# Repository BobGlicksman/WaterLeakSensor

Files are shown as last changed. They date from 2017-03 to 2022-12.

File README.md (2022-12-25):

# WaterLeakDetector - Version 2
The Water Leak Detector (WLD) is an IoT device that can monitor two specific locations for the presence of water. 
When water is detected, an alarm will sound and an SMS text alert will be sent to the user's mobile phone. 

A typical use case is to deploy the WLD in a laundry room where it can monitor water leaks that might occur from a washing machine, 
hot water heater, or sewer backup.

The WLD also includes a temperature and humidity sensor. These values are displayed on a dial and also in a smartphone app.  The
smartphone app (Android only at this time) is included in this project.  High and low temperature limits may be set via the smartphone
app.  When either limit is hit, an SMS text alert will be sent to the user's mobile phone.  The smartphone app allows the user to set the
high and low temperature limits.  The app displays the current temperature, relative humidity, and the status of all three alarms (low
temperature, high temperature, water leak).

This version (version 2) of the WLD eliminates Blynk and IFTTT integrations in favor or our current standard techniques for app development,
alarms and alerts, and for logging to Google cloud spreadsheets.  For details, see: 

https://github.com/TeamPracticalProjects/Connectivity_Tools_with_Particle_Devices

Begin with the file WLD Read Me First.pdf

<!--- ![front view completed project](Photos/Finished%20pointerB.JPG?raw=true "Completed Project") -->

<!--- ![app screen](Photos/App_screenshot.jpg?raw=true "App Screen") -->

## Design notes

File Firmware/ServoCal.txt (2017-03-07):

/* SERVOCAL: program to calibrate the servo.
    The servo is connected to a 3.3 volt to 5 volt converter.  The converter
    input is connected to Photon pin D3.  A 5.6K ohm pulldown resistor is used
    to ensure that the servo is quiet while the Photon is being flashed/reset.
    
    The SIS debug client is used to specify positions for the servo.  In order
    to calibrate the servo, the servo with a pointer is mounted on to the meter
    scale.  The user specifies positions for the sero and observes where the 
    servo pointer is on the meter scale.  The position values for the scale minimum
    and for the scale maximum are determined by trial and error and the final
    values are noted for use in the WaterLeakDetector program.
    
    date: 3/07/17, by Bob Glicksman
    
    (c) 2017 by Bob Glicksman, Jim Schrempp, and team Practical Projects
*/

Servo myservo;  // create servo object to control a servo

const int MIN_POS = 5;  // the minimum position value allowed
const int MAX_POS = 175;  // the maximum position value allowed

int pos = (MAX_POS - MIN_POS)/2;    // global variable to store the servo position

void setup() {
    Particle.function("Servo", servoCmd);
    
    myservo.attach(A5);  // attaches pin A5 to the servo object
    delay(2000);  // wait 2 seconds before continuing

} // end of setup

void loop() {
    myservo.write(pos); 
} // end of loop

int servoCmd(String cmd) {
    int servoPosition = cmd.toInt(); // get the user's desired position for the servo
    
    if(servoPosition > MAX_POS)  {
        pos = MAX_POS;
    }
    else if(servoPosition < MIN_POS)  {
        pos = MIN_POS;
    }
    else  {
        pos = servoPosition;
    }
    
    return servoPosition;
}  // end of servoCommand

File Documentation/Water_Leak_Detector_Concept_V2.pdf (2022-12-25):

# Water Leak Detector Concept Document

By: Jim Schrempp and Bob Glicksman; updated 12/04/2022

By: Team Practical Projects; 10 June 2017

This document is © Copyright 2022, 2017 Team Practical Projects, Bob Glicksman and Jim Schrempp. All rights reserved.

NOTICE: Use of this document is subject to the terms of use described in the

document “Terms_of_Use_License_and_Disclaimer” that is included in this release package. This document can also be found at: https://github.com/TeamPracticalProjects/WaterLeakSensor/blob/master/Documentation/Terms_of_Use_License_and_Disclaimer.pdf

© 2022, 2017, Team Practical projects, Jim Schrempp and Bob Glicksman; all rights reserved. Subject to “Terms of Use, License and Disclosure”

Table of Contents.

Table of Contents. | 1
Problem. | 2
Proposed Solution. | 2
Operational Details. | 4

Problem.

A leaking washing machine, overflowing tub or sink, or leaky pipes or toilet can cause considerable damage to a home if not detected and shut off early. Years ago, a washing machine water valve stuck open while washing clothes late at night. One of us awoke in the middle of the night to find a flood in the washer/dryer vestibule resulting in $12,000 in water damage. Since that time, we have been reluctant to run the washing machine at night or at any time when someone is not home to watch over it. This is not always convenient and it would help to have a solution that can detect a water leak and signal us via a local alarm (for when we are at home) and/or a smartphone notification (for when we are out).

Leaky or humid basements and leaking water heaters present similar problems. Adding a second water leak detection sensor, as well as temperature and humidity measurement to the project, can cover all of these bases.

Proposed Solution.

There are inexpensive, analog water detection sensors, such as: https://www.amazon.com/Solu-Detection-Arduino-Sensitivity-Surface/dp/B00UJ0DVN4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 (https://www.amazon.com/Solu-Detection-Arduino-Sensitivity-Surface/dp/B00UJ0DVN4)
This sensor looks as follows:

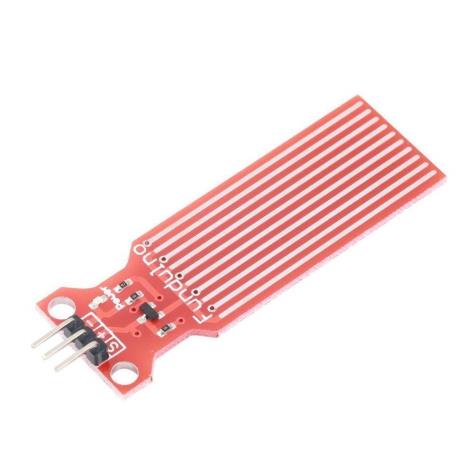
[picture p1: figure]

Water Leak Sensor.

The sensor consists of a bunch of parallel conductors that have a very high DC resistance when the sensor is dry. However, when water shorts out adjacent conductors, the resistance falls.

This project uses a Particle Photon (e.g. https://www.adafruit.com/products/2721) to sense the presence and amount of water via an analog input from this sensor. Based upon our analysis and test results for this water level sensor, the sensor’s analog output should be thresholded to produce an alarm condition when the voltage output goes from 0 volts (dry) to a relatively low value (e.g. 0.5 volts). Tests of the sensor have determined that a pool of water of as little as 2 mm deep will cause this level of change.

Whenever water is sensed, the project will sound a loud, pulsing, audible alarm made from an inexpensive piezo buzzer (e.g. https://www.adafruit.com/products/1536). An LED will also flash when the water level threshold is exceeded. A backlit push button switch (e.g. https://www.adafruit.com/products/1440) provides both the LED indicator and a means to mute the audible alarm when pressed.

Temperature and humidity are measured by one, inexpensive (DHT11) sensor (e.g. https://www.adafruit.com/products/386). An inexpensive servo (e.g. https://www.adafruit.com/products/169) is used to provide a visual “meter” for temperature or humidity, based upon a toggle switch selection (e.g. https://www.adafruit.com/products/3221).

The WiFi capability of the Photon is used to provide a smartphone notification of an alarm condition. Alarms are generated for: Water leak detection by either of the two sensors, low temperature detection, and high temperature detection. Publications to the Particle Cloud from the Photon firmware trigger a webhook which, in turn, runs a Google Apps Script that is deployed as a web app. The script sends an e-mail to the user’s mobile carrier’s SMS gateway, producing an alarm text message on the user’s mobile phone.

A smartphone app is provided as part of this project. The app is written in MIT App Inventor 2 and currently supports Android smartphones (iOS support is in beta testing by MIT as of this writing). The app allows the user to:

- Display the current temperature and relative humidity from the device, over the Internet.
- Display the current status of the alarms (temperature and leak).
- Set and display the low and high temperature alarm limits.

Communication between the Photon, the Particle Cloud and other necessary cloud services follow the Team Practical Projects now-standard approach, as described in the document:

https://github.com/TeamPracticalProjects/Connectivity_Tools_with_Particle_Devices/blob/main/TPP_Connectivity_Tools_Technical_Description.pdf (https://github.com/TeamPracticalProjects/Connectivity_Tools_with_Particle_Devices/blob/main/TPP_Connectivity_Tools_Technical_Description.pdf)

The concept is shown, schematically, below:

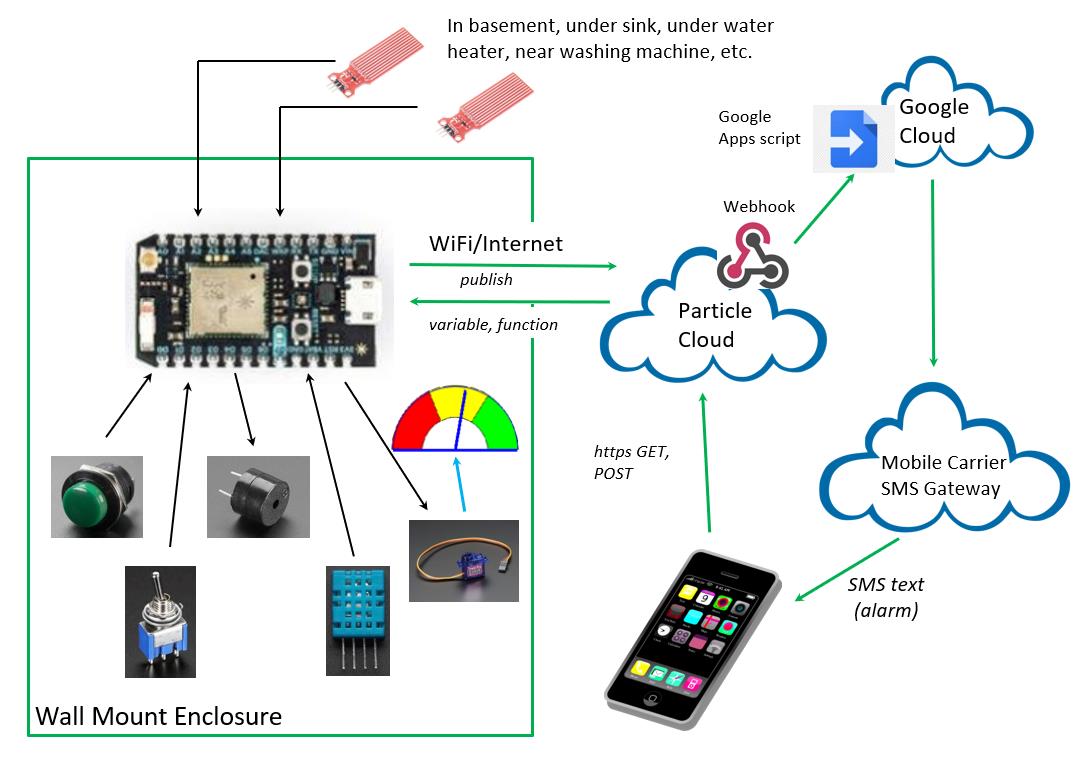
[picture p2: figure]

Water Leak Alarm Concept.

Operational Details.

The project supports two water level sensors. Each water level sensor may be placed under or near a sink, toilet, washing machine, water heater, or basement wall to be monitored. The sensors should be positioned vertically so that the maximum number of conductors are shorted when the water level rises to the bottom of the sensor and above.

The two sensors are cabled to the Photon which, along with the DHT11, toggle switch, pushbutton switch, piezo buzzer and servo, should be wall mounted in a plastic box. The location of the plastic box should be somewhere visible, so that the temperature/humidity indication can clearly be seen and the LED/mute button accessed. Analysis of the water level sensor has determined that it has an output impedance of about 100 ohms; thus, a relatively long cable (e.g. 25 feet) can be used between the sensors and the electronics enclosure, particularly if several threshold readings are required to trigger an alarm.

The firmware in the Photon continuously monitors the amount of water on the sensors, based upon their analog signal value. When a predetermined “flood alert” threshold is exceeded for five measurements, the piezo buzzer is pulsed to create an easily heard audible alarm and the backlit push button LED flashes. The alarm sounds continuously until someone presses the pushbutton to silence it or until the alarm condition is cleared. The LED continues to flash until the alarm condition is cleared. The alarm also publishes an alarm event to the Particle Cloud, which, in turn, results in an SMS alarm notification to the user’s mobile phone. The alarm resets and rearms automatically when five measurements fall below the threshold value.

The Photon reads out temperature and humidity values from the DHT11 sensor every few seconds. The servo “meter” displays either temperature or humidity, based upon the toggle switch selection. The Photon firmware tests to see if the temperature exceeds a low or high reading threshold and publishes an alarm accordingly. Low and high temperature alarms result in an appropriate SMS alarm notification to the user’s mobile phone.

The current temperature and humidity readings and the status of all of the alarms may be read, at any time, using a smartphone app that is part of this project. The app also provides a means for the user to set the high and low temperature alarm limits. The Particle Console may be used in lieu of the smartphone app or for testing purposes.

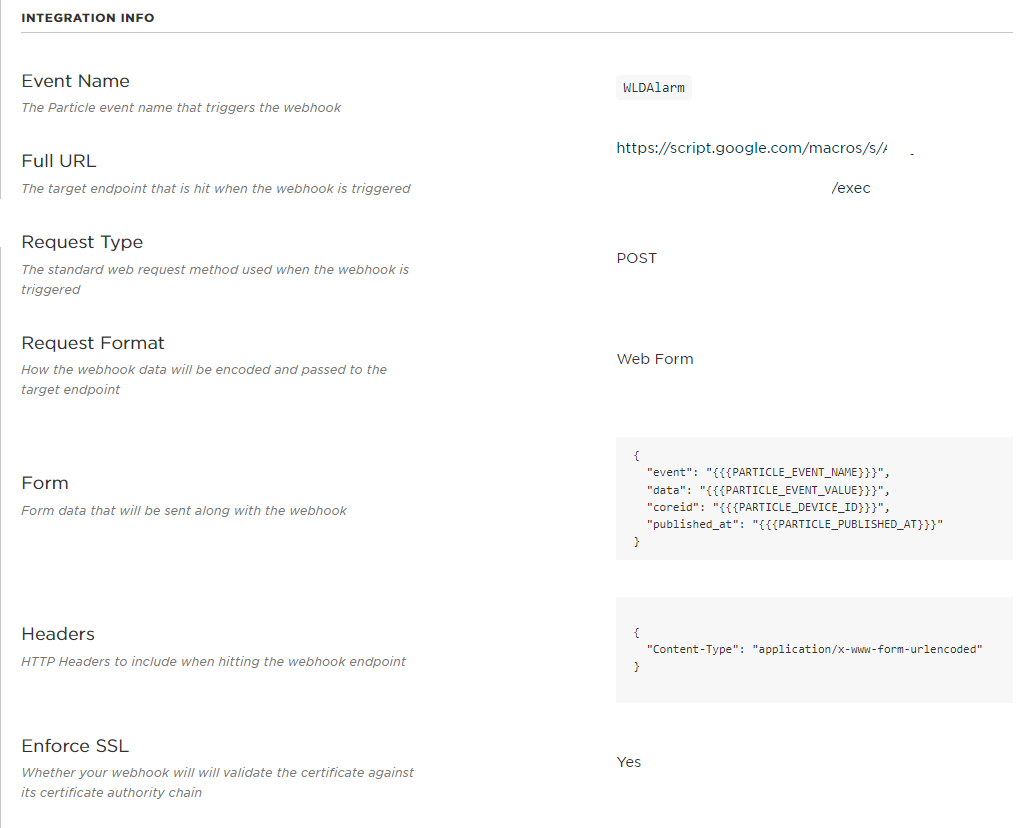
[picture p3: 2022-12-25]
Scripts/Webhook.png

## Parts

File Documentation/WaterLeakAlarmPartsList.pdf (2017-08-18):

REQUIRED PARTS FOR PCB ASSEMBLY
Item # | Qty | Vendor | Vendor Part # | Description | Link | Unit Price | Extended
| | | | | | | price

Notes

1 | 1 Dirty PCBs | N/A | PC Board | http://dirtypcbs.com/store/designer/details
| | | | | /JSchrempp/5148/water-leak-detector-pcb- | $12.00 | $12.00 Only $2 each in quantities of 10 or more.
2 | 1 Adafruit | 2721 | Particle Photon WiFi
| | | | Microcontroller with
| | | | breadboard headers | https://www.adafruit.com/products/2721 | $19.00 | $19.00 The Particle Electron may also be used.
3 | 1 Adafruit | 1787 | 74HCT125 level converter, 3 volt to 5 volt
https://www.adafruit.com/products/1787 | $1.50 | $1.50
4 | 1 Adafruit | 1536 | Piezo Buzzer | https://www.adafruit.com/products/1536 | $0.95 | $0.95
5 | 1 Adafruit | 169 | Micro Servo | https://www.adafruit.com/products/169 | $5.95 | $5.95
6 | 1 Adafruit | 386 | DHT11 temperature/humidity sensor with pullup resistor | https://www.adafruit.com/products/386 | $5.00 | $5.00
7 | 1 Adafruit | 1440 | Momentary pushbutton switch with green LED | https://www.adafruit.com/products/1440 | $1.50 | $1.50
8 | 1 Adafruit | 3221 | SPDT toggle switch | https://www.adafruit.com/products/3221 | $0.95 | $0.95
9 | 1 Adafruit | 501 | USB power supply, 5 volt/1 Amp | https://www.adafruit.com/products/501 | $5.95 | $5.95
10 | 1 Adafruit | 266 | strip of 40 female-female 6" jumper wires | https://www.adafruit.com/products/266 | $3.95 | $3.95
11 | 10 Jameco | 691024 | Resistor, 4.7 k ohm, 1/4 watt axial) | http://www.jameco.com/z/CF1-4W472JRC- Resistor-Carbon-Film-4-7k-Ohm-1-4-Watt-5- _691024.html | $0.10 | $0.99 Must order 10 pcs (need 5)
12 | 1 Jameco | 222608 | USB cable | http://www.jameco.com/z/10U2-02203-BK- Cable-USB2-0-A-B-3-Feet-Black-USB-A-Male- To-USB-B-Male_222608.html
$1.75 | $1.75
13 | 2 Amazon.com sensor | Solu water level sensor | https://www.amazon.com/gp/product/B00 UJ0DVN4/ref=oh_aui_detailpage_o00_s00? ie=UTF8&psc=1
$3.62 | $7.24 Order 1 or 2 sensors, as needed for your project.
14 | 2 Sparkfun.com 14021 | RJ11 dual breakout | https://www.sparkfun.com/products/1402
| | | 1 | $1.95 | $3.90
15 | 4 Sparkfun.com 132 | RJ11 6 pin PCB connector | https://www.sparkfun.com/products/132 | $1.25 | $5.00
16 | 10 Jameco | 690785 | Resistor, 470 ohm, 1/4 watt
| | axial) | http://www.jameco.com/z/CF1-4W471JRC- Resistor-Carbon-Film-470-Ohm-1-4-Watt-5- _690785.html | $0.10 | $0.99 Must order 10 pcs (need 1)
17 | 10 Jameco | 93761 | Capacitor, 100 uf, 25 v | http://www.jameco.com/z/R100-25-100-uF- 25-Volt-Radial-Capacitor_93761.html
$0.09 | $0.90 Must order 10 parts (need 1)

18 | 10 Jameco | 151116 | Capacitor, 0.1 uf, ceramic | http://www.jameco.com/z/DC-1-25- Capacitor-Ceramic-Disc-0-1-micro-F-25V- plusmn-20-37-_151116.html
$0.15 | $1.50 Must order 10 parts (need 7)
19 | 1 Jameco | 230958 | USB female type B connector | http://www.jameco.com/z/USB-B-S-RA-CS1- SPCC-WT-Adam-Technologies-Connector- USB-2-0-USB-B-Pcb-Female-Right-
$0.99 | $0.99 http://www.jameco.com/webapp/wcs/stores/servlet/Produ
ct_10001_10001_230958_-1
20 | 1 Sparkfun.com 10158 | Breakaway male pin
| | | headers (strip of 40) | https://www.sparkfun.com/products/1015
| | | | 8
$2.95 | $2.95
21 | 1 Jameco | 317197 | 14 pin DIP socket | http://www.jameco.com/z/6100-14-R- Socket-IC-14-Pin-Machine-Tooled-Low- Profile-0-3-Inch-Wide_37197.html
$0.50 | $0.50
22 | 1 Jameco | 164822 | 4 pin SIPP socket | http://www.jameco.com/z/6100-1-4-Socket- SIPP-1x4-Pin-Machine-Tool-Pins-Soldertail- Female_164822.html
$0.59 | $0.59 Best to mount the DHT11 in a socket. This miounts the part
vertically - can bend the DHT11 horizinal after installation.
23 | 2 Digi-Key | S7016-ND | 18 pin female header | https://www.digikey.com/products/en?key words=S7016-ND
$1.37 | $2.74
24 | 2 Jameco | 196227 7 ft 4 wire telephone cable http://www.jameco.com/z/8101-64207-
| | | | Modular-Network-Cable-RJ11-6P4C-7-Feet- Long-Reverse-Grey_196227.html
$1.75 | $3.50 NOTE: the assembly instructions are for "reverse" or
"telephone wired" cables. This part number is an example of a 7 foot cable. You can buy telephone cables in many sizes and colors in hardware stores and online. Be sure to get 4 wire (not 2 wire) cables!
TOTAL: | $78.29
| | | | ENCLOSURE AND MOUNTING HARDWARE (CUT BOX)
1 | 1 Office max | 452378 | Box | http://www.officedepot.com/a/products/4 52378/Really-Useful-Box-Plastic-Storage- Box/
$2.79 | $2.79 Use this part for the plastic box that you can cut to make the
enclosure per the instructions.
2 | 8 Digi-Key | 36-1902E-ND | Threaded standoff, F-F, 4- 40 x 1", Nylon | https://www.digikey.com/products/en?key words=36-1902E-ND
$0.90 | $7.20
3 | 8 Digi-Key | 36-9529-ND | Nylon screw, 4-40 x 1/2" | https://www.digikey.com/product- detail/en/keystone-electronics/9529/36-
$0.14 | $1.12
4 | 12 Digi-Key | 36-9427-ND | Nylon screw, 4-40 x 1/4" | https://www.digikey.com/products/en?key words=36-9427-ND
$0.14 | $1.68
5 | 4 Digi-Key | 36-9605-ND | Nylon nut, 4-40 | https://www.digikey.com/product- detail/en/keystone-electronics/9605/36-
$0.17 | $0.68
6 | 1 Home Depot 11364 | #8 wood screw and wall
| | | anchors | http://www.homedepot.com/p/E-Z-Ancor- Twist-N-Lock-75-lb-8-x-1-1-4-in-Philips-Zinc- Plated-Nylon-Flat-Head-Drywall-Anchors- with-Screws-4-Pack-11364/100165900
$1.49 | $1.49 4 pack (need 2)
7 | 1 N/A | N/A | Front panel, laser cut from
3 mm plastic or wood
N/A | N/A | N/A | This is a custom made part from a 2D CAD file. You need
access to a laser cutter to fabricate it.

8 | 1 N/A | N/A | Mounting bracket, laser cut
from 3 mm plastic or wood
N/A | N/A | N/A | This is a custom made part from a 2D CAD file. You need
access to a laser cutter to fabricate it.

ENCLOSURE AND MOUNTING HARDWARE (3D PRINTED)
1 | 1 Shapeways | | Mounting assembly | https://www.shapeways.com/product/HBS
| | | | DDYLAU/water-leak-detector-chassis (https://www.shapeways.com/product/HBSDDYLAU/water-leak-detector-chassis)
$24.00 | $24.00 Use this in lieu if the plastic box for a 3D printed ready to
assemble mounting enclosure.
2 | 1 Shapeways | | 3D printed front panel | https://www.shapeways.com/product/UST
| | | | N8GVJQ/wld-bezel (https://www.shapeways.com/product/USTN8GVJQ/wld-bezel)
$15.00 | $15.00 Use this with the Shapeways 3D printed Mounting assembly
3 | 8 Digi-Key | 36-9427-ND | Nylon screw, 4-40 x 1/4" | https://www.digikey.com/products/en?key
| | | | words=36-9427-ND
$0.14 | $1.12
4 | 8 Digi-Key | 36-9605-ND | Nylon nut, 4-40 | https://www.digikey.com/product-
| | | | detail/en/keystone-electronics/9605/36-
| | | | 9605-ND/2746252
$0.17 | $1.36
5 | 4 | Self tapping screw | [need link from Jim]
6 | 1 Home Depot 11364 | #8 wood screw and wall
| | anchors | http://www.homedepot.com/p/E-Z-Ancor-
| | | Twist-N-Lock-75-lb-8-x-1-1-4-in-Philips-Zinc-
| | | Plated-Nylon-Flat-Head-Drywall-Anchors-
| | | with-Screws-4-Pack-11364/100165900
$1.49 | $1.49

ENCLOSURE AND MOUNTING HARDWARE (LASER CUT)
1 | 1 Tap Plastics | 8x11 3mm material | $10.00 | $10.00 acrylic or wood. For this case you have to cut it yourself from the WLD plans.
2 | 4 Jameco | 77650 | Threaded standoff, M-F, 6-
| | 32 x 1", Metal

https://www.jameco.com/webapp/wcs/stores/servlet/ProductDisplay?productId=77650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 (https://www.jameco.com/webapp/wcs/stores/servlet/ProductDisplay?productId=77650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)

| | | $0.59 | $2.36
3 | 4 Jameco | 77578 | Threaded standoff, F-F, 6- 32 x 1", Metal

https://www.jameco.com/webapp/wcs/stores/servlet/ProductDisplay?productId=77578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 (https://www.jameco.com/webapp/wcs/stores/servlet/ProductDisplay?productId=77578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)

$0.90 | $3.60
4 | 8 Jameco | 2094418 | #6-32 x 1/4" Phillips Pan Head Machine Screw

https://www.jameco.com/webapp/wcs/stores/servlet/ProductDisplay?productId=2094418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 (https://www.jameco.com/webapp/wcs/stores/servlet/ProductDisplay?productId=2094418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)

$0.09 | $0.72
5 | 4 Jameco | 2094434 | #6-32 x 1/2" Phillips Pan Head Machine Screw

https://www.jameco.com/z/1128804--6-32-x-1-2-Phillips-Pan-Head-Machine-Screw_2094434.html (https://www.jameco.com/z/1128804--6-32-x-1-2-Phillips-Pan-Head-Machine-Screw_2094434.html)

$0.09 | $0.36
6 | 8 Jameco | 42420 | #6-32 Nut Hex | https://www.jameco.com/webapp/wcs/sto res/servlet/ProductDisplay?langId=- (https://www.jameco.com/webapp/wcs/stores/servlet/ProductDisplay?productId=42420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)
0.065 | $0.52

7 | 4 Digi-Key | 36-9529-ND | Nylon screw, 4-40 x 1/2" | https://www.digikey.com/product- detail/en/keystone-electronics/9529/36-
$0.14 | $0.56
8 | 8 Digi-Key | 36-9605-ND | Nylon nut, 4-40 | https://www.digikey.com/product- detail/en/keystone-electronics/9605/36-
$0.17 | $1.36
9 | 1 Home Depot 11364 | #8 wood screw and wall
| | | anchors | http://www.homedepot.com/p/E-Z-Ancor- Twist-N-Lock-75-lb-8-x-1-1-4-in-Philips-Zinc- Plated-Nylon-Flat-Head-Drywall-Anchors- with-Screws-4-Pack-11364/100165900
$1.49 | $1.49

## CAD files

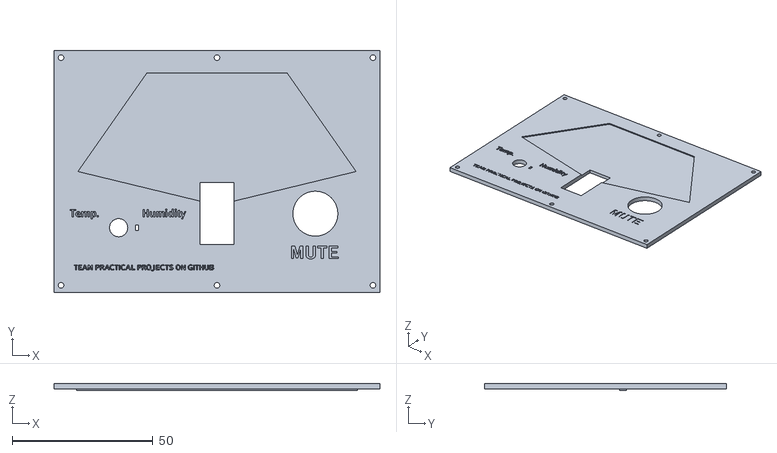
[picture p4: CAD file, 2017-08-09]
Case/casebezel.stl
116.0 x 86.0 x 2.50

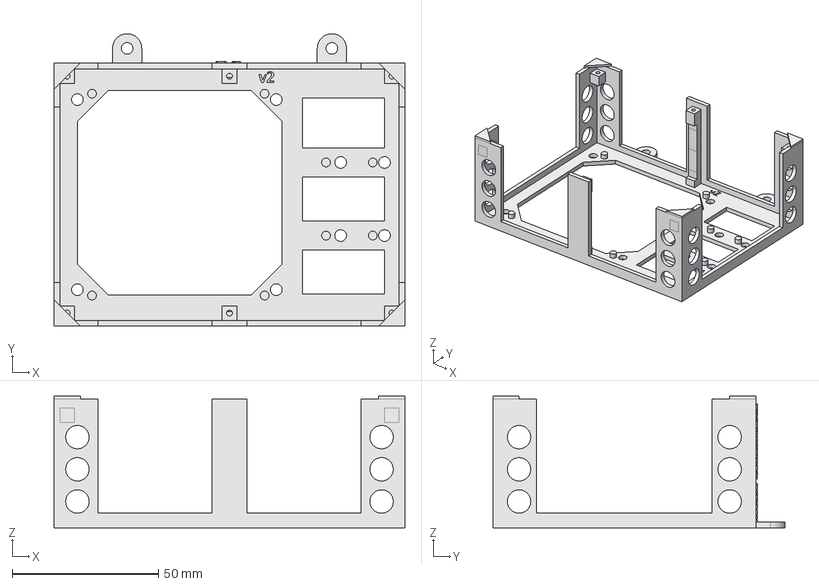
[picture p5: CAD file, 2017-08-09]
Case/casebottomskel.FCStd
120.0 x 100.0 x 45.0 mm

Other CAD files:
Case/casebottomskel.stl

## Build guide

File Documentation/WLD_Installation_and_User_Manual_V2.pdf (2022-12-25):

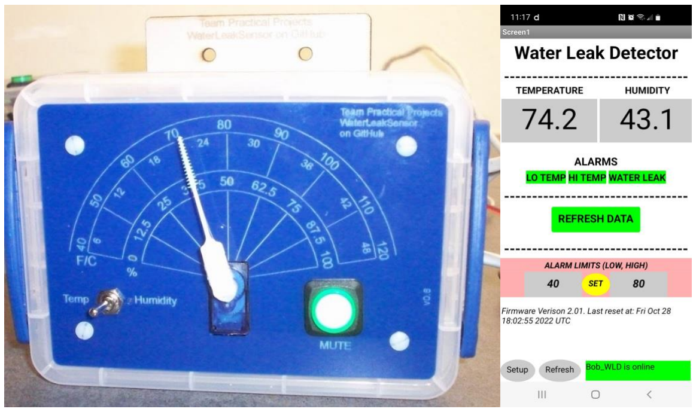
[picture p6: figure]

© 2022, 2017 Jim Schrempp and Bob Glicksman. All Rights Reserved

# Water Leak Detector Installation and User Manual

© 2022, 2017, Jim Schrempp and Bob Glicksman date: 12/23/22

NOTICE: Use of this document is subject to the terms of use described in the

document “Terms_of_Use_License_and_Disclaimer” that is included in this release package. This document can also be found at: https://github.com/TeamPracticalProjects/WaterLeakSensor/blob/master/Documentation/Terms_of_Use_License_and_Disclaimer.pdf

# Water Leak Detector

## Table of Contents

# 1.Overview

The primary purpose of the Water Leak Detector (WLD) is to detect leaks and to notify the user in time to contain the damage while it is still minor. To this end, the WLD provides both a local audible and visual notification and a remote notification to the user’s mobile phone. The WLD is designed to support two sensors, each of which may be placed anywhere that can be cable connected to the WLD electronics.

Secondarily, the WLD contains an inexpensive temperature and humidity sensor (DHT11) that monitors ambient conditions and may provide useful augmentation to the water leak sensor data; e.g. an indication of a steam leak in a boiler in the basement of a house.

The sensors used in the WLD are actually water level sensors whose data is processed to provide an alarm condition in the event of a puddle of water less than 2 mm in height. An alarm condition exists whenever either of the sensors detects the presence of water. The alarm condition persists until both sensors are dry, in which case the WLD automatically clears out the alarm condition and re-arms for subsequent triggering of a water leak alarm.

The WLD electronics are based upon the Particle Photon module (https://www.particle.io). The Photon contains an advanced 32 bit microcontroller with a built in Wi-Fi capability. The WLD electronics requires a Wi-Fi connection to the Internet and will not work (even locally) unless the Photon can communicate with the Particle cloud over the Internet. The Particle cloud service is available to users of Particle’s devices with a generous free monthly service allotment.

The WLD is designed to be accessed remotely via a smartphone. WLD uses a custom app (part of this project) to provide the user with current temperature, humidity and alarm status information, as well as to allow the user to set low and high temperature alarm limits. The app is written in MIT App Inventor 2 (http://ai2.appinventor.mit.edu/) and is currently supported on Android smartphones and tablets¹
(including Amazon Fire tablets). Water leak and temperature alarms are sent to the user’s mobile device using SMS texting.

The WLD is offered to all users free of charge for non-commercial use. Any and all use of the information provided in this package is subject to the restrictions described in the document “Terms_of_Use_License_and_Disclaimer.pdf” that is included in this release package. This document can also be found at:

https://github.com/TeamPracticalProjects/WaterLeakSensor/blob/master/Documentation/Terms_of_Use_License_and_Disclaimer.pdf

The WLD is only available as a set of documentation at this time. You must purchase all of the parts yourself and you must assemble the WLD yourself, including soldering of electronic

1 Support for iOS devices is currently in beta testing with Apple.

components and cabling, cutting and assembling of plastic material, mounting of materials on walls, setting up of accounts on cloud-based services and smartphones, and following written instructions. You will need basic hand tools (screwdrivers, files, knives, drill) and basic through hole soldering tools (soldering iron, long nose pliers, diagonal cutters, wire strippers) and the skills to use these tools properly in order to assemble the WLD.

We have endeavored to provide full, accurate, step by step instructions for each and every step in making a fully operational WLD. However, we explicitly disclaim any responsibility or liability for inaccuracies or confusion in any of our documentation. We are not a commercial entity and we cannot offer any guarantee of support or warranty of any kind if you are unable to successfully build and deploy a WLD. Therefore, we urge you to read through all of the documentation for this project and make sure that you are comfortable with everything that you will need to do to make a working WLD before proceeding to order parts or begin the manufacture of any of the WLD components.

# 2.Component Parts

An overview of the WLD can be found in the document “Water_Leak_Dectector_Concept.pdf” which is included in this package and can also be found at:

https://github.com/TeamPracticalProjects/WaterLeakSensor/blob/development/Documentation/Water_Leak_Detector_Concept.pdf.

Please read through this document first so that you are familiar with the WLD overall, before proceeding to read the details below. The WLD project consists of hardware, firmware (for the Photon), a Google Apps Script (deployed as a web app), and an app for your smartphone. These items are described in this section.

2.1. Hardware.

The WLD hardware consists of the following components:
- The water leak sensors
- The WLD electronics
- Your Wi-Fi router
- Your smartphone
2.1.1. Water Leak Sensors.

Figure 2-1 is a picture of the sensors that are used in this project. A US quarter is included in the photo to provide an indication of the size of these sensors (they are small). The sensors are intended to measure the level of water, where the bottom of the sensor is at the left of the photo and the electronics (right) are at the top.

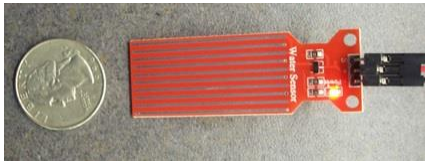
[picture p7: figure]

Figure 2-1. Water Leak Sensor.

Each sensor consists of a set of parallel conductive traces arranged as interleaved “fingers”. These traces are an open circuit when the sensor is dry. However, when the sensor encounters water at some level up from the bottom, the resistance of these traces lowers and the sensor outputs a voltage that is indicative of the level of the water between the bottom (lowest voltage) and the top of the traces (supply voltage).

The WLD is only interested in the presence of water. The WLD firmware in the Photon continuously measures the voltage from each of the sensors and compares this voltage to a threshold. When this threshold is exceeded for a set number of measurements, a water leak alarm is triggered. The alarm remains triggered until both sensors are dried off and thus below the alarm threshold for a set number of measurements. We have empirically set the threshold so that an alarm is triggered by a water level that is less than 2 mm from the bottom of the sensor.

The WLD accommodates two sensors so that one WLD can monitor two different locations; e.g. by a washing machine and by a water heater in a basement or garage. The sensors themselves connect using a 3 pin 0.1” spaced header. In order to cable the sensors to the electronics neatly and securely, the WLD design includes pin header to RJ11 connector boards. A short pin header cable at the sensor end connects to a miniature circuit board that wires it to an RJ11 telephone connector. A similar board and connector are used in the electronics enclosure to transition back from RJ11 cable to the WLD electronics. RJ11 cables are available on-line and in many hardware stores. They are inexpensive, available pre-terminated in many different cable lengths and in different colors for running along baseboards and up walls. They are jacketed, relatively rugged, and the connectors have a locking mechanism so that the cable won’t fall out of its mating socket. Make sure that you use 4 wire (not 2 wire) RJ11 cable. 2 wire RJ11 telephone cables will not work!

2.1.2. Electronics.

The WLD electronics are contained in a plastic enclosure. Figure 2-2 shows this enclosure with sensor cables, power cable and mounting bracket attached.

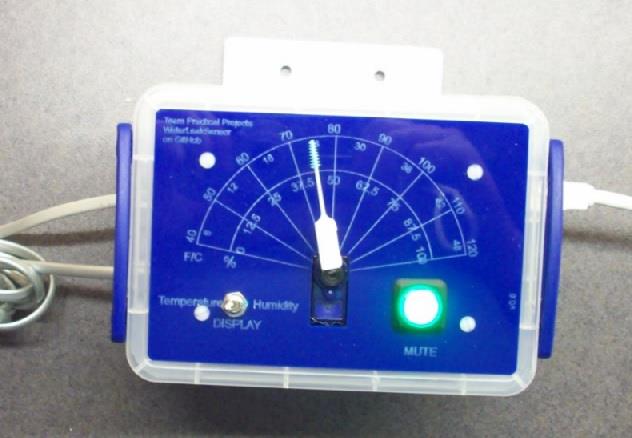
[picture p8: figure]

Figure 2-2. Assembled and Cabled Electronics Enclosure.

A plastic meter faceplate is attached to the cover of the box. The faceplate is laser cut from 3 mm plastic stock using a CAD file that is included in this project package. If you do not have access to a laser cutter, you can print out a paper copy of this faceplate from the included pdf file and carefully glue it to the cover of the box.

The faceplate mounts the “servo” meter, which indicates temperature and humidity locally. The toggle switch to the left of the servo meter is used to select whether the servo meter displays temperature or humidity. Both Fahrenheit and Centigrade scales are included on the faceplate. The humidity scale is always %RH.

The right side of the faceplate contains a backlit pushbutton switch. The backlight lights steady when the WLD is armed and ready. The backlight blinks rapidly when a water leak alarm condition is present. A piezo buzzer inside of the enclosure beeps annoyingly when a water leak condition occurs, but pressing the backlit pushbutton mutes the audible alarm until the system is automatically re-armed after the sensors are dried off.

The project documentation also includes a template for laser cutting a wall mounting bracket for the enclosure. This bracket may optionally be used both as a template for drilling mounting holes for the circuitry inside of the enclosure as well as providing holes for wall mounting the electronics enclosure after it is assembled and tested.

The two water level sensors are connected to the left side of the enclosure using RJ11 cables. The right side of the enclosure contains a USB “B” connector which is used to supply power to the enclosure. The enclosure must be placed in a location where AC power is available.

Figure 2-3 shows the inside of the electronics enclosure.

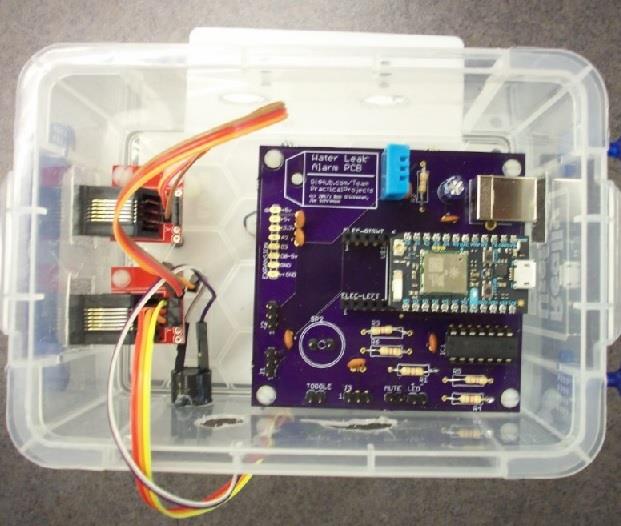
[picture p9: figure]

Figure 2-3. Inside View of Electronics Enclosure.

On the left side of the enclosure are two small printed circuit boards that transition RJ11 connections to pin header cables. The RJ11 jacks are accessible through holes cut through the side of the box. The main electronics printed circuit board is mounted on the right side of the enclosure with the USB “B” type power connector accessible through a hole cut through the side of the box. Figure 2-3 shows the piezo buzzer glued to the lower side of the box; however, the released version of the main printed circuit board allows the buzzer to be soldered directly to the board, obviating cutting and gluing it to the box itself.

2.1.3. Other Hardware.

The WLD project requires a Wi-Fi connection to the Internet. You must have a Wi-Fi router or gateway that is compatible with the Particle Photon – specifications can be found at:

https://www.particle.io/products/hardware/photon-wifi-dev-kit

The WLD project also requires that you have an app on a smartphone in order to receive current status information from the WLD. A suitable app for Android phones is included in this

project²
. You will need a mobile phone (not necessarily a “smart” one) to receive water leak and temperature alarms via SMS texts.
2.2. Firmware.

Firmware is what we call the software that runs on the Particle Photon microcontroller. The released WLD firmware is included in this package in the Firmware folder of this repository.

You must have an account at https://www.particle.io in order to flash the firmware to your Photon device. You will also need to have a Google account and an active account with a mobile carrier in order to receive SMS alarms messages from the WLD. Complete installation instructions are included in this document.

2.3. Smart Phone App (optional).

The WLD communicates with an app on your (Android) smartphone. The code for this app is included in the App folder of this repository. Both source code (.aia file) and an Android installer file (.apk file) are included. Installation instructions are included in this document.

2.4. Script.

The WLD requires a Google Apps Script to be installed in a Google account that is owned by the user. This script generates the SMS text alarms to the user’s mobile phone (via the user’s mobile carrier SMS gateway). Installation instructions are included in this document.

2 The Particle Console may be used in lieu of a smartphone app (see: https://console.particle.io)

# 3.WLD Hardware Build, Installation and

Placement.

The WLD hardware must be assembled from the parts that are listed in the “WaterLeakAlarmPartsList” document that is in the Documentation folder of this repository. The electronics are contained on a custom printed circuit board. Eagle CAD files are provided in the Hardware folder of this repository. Assembly instructions for the printed circuit board can be found in the document “PCB Assembly Instructions” in the Documentation folder of this repository.

The assembled printed circuit board becomes part of the overall WLD hardware assembly by adding an enclosure and two standalone RJ11 jack modules. There are three different options for the enclosure:
- An off the shelf plastic box with a laser cut faceplate.
- An enclosure made from 2D laser cut wood or plastic parts.
- A 3D printed plastic enclosure.

The Documentation folder of this repository contains instructions for fabricating and assembling each of these enclosure options. You may choose whichever option suits you best.

Once assembled, the Servo Meter must be calibrated. See the document “Servo_Meter_Calibration” in the Documentation folder of this repository. After calibrating the servo meter, the operating firmware needs to be flashed to the Photon microcontroller in the WLD and the WLD hardware operation should be tested using the Particle Console. See section 6.1 of this document for firmware installation instructions.

Once the WLD hardware is assembled and tested, the electronics should be mounted on a wall or otherwise accessible location within cable distance of the sensors. A wall mounting bracket is available as part of this project. The wall mounting bracket allows you to assemble and test the WLD electronics and then to mount it on a wall using two #8 screws. The wall mounting bracket also serves as a template for drilling holes in the bottom of the enclosure box for assembly of the electronic components into the box. The wall mounting bracket is provided as a CAD file with this project and you may use this CAD file to laser cut the bracket out of 3 mm plastic or wood material. If you do not have access to a laser cutter, you will have to fabricate your own means of mounting the WLD electronics to a wall.

The location of the WLD electronics must:

- Be accessible to AC power. A “wall wart” power supply plugs into a standard wall outlet and provides power to the WLD electronics via a standard USB A/B cable. The power cable plugs into a mating USB connector located on the right side of the enclosure.
- Be physically accessible. You will want to mount the WLD electronics enclosure in a location where you can see the servo meter and the backlit pushbutton switch on the face of the enclosure. You should also be able to easily operate the toggle switch and press the backlit pushbutton at this location.
- Be located where sensor cables can be run neatly to the enclosure. RJ11 cables from the two water level sensors plug into mating RJ11 jacks located on the left side of the WLD electronics enclosure.

The two water level sensors must be mounted vertically, with the bottom of the sensor in physical contact with the floor. The back of each sensor is completely blank. We recommend that you use high strength outdoor double sided tape to secure the sensor to a wall, in the proper orientation and location.

The best location for the water level sensors are along a wall that is the lowest point in the room, near where a leak would occur (sink, washing machine, water heater, etc.). If the room has its low point at a drain near the center of the room, you might want to improvise some sort of mount for the sensor, such as a block of wood. Note, however, that the sensor must be cabled to the electronics, so you will need to take care to ensure that the sensor, its mount and the cable run do not interfere with movement through the room. A better solution might be to place a flat pan or other container underneath where leaks are expected, with one edge of the pan against a wall where the sensor wires will run. This way, the water leak can puddle in the pan and trigger a sensor that is cabled along a wall.

Each sensor attaches to a miniature printed circuit board using a 3 wire female-female header cable. The printed circuit board transitions this header cable to a 4 wire RJ11 telephone cable, as shown in figure 3-1.

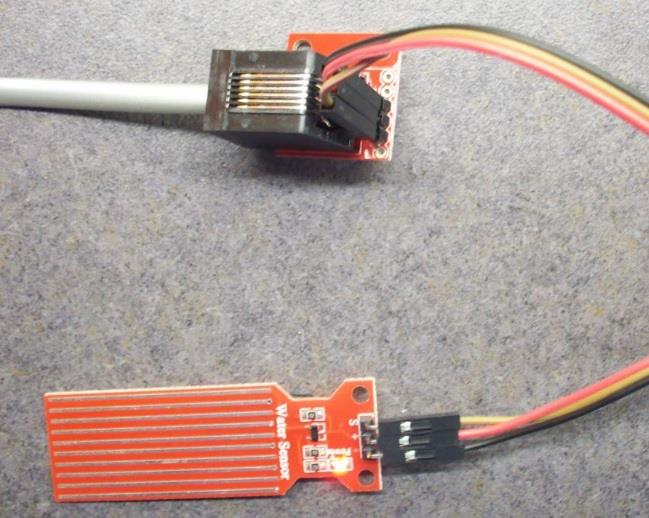
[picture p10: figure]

Figure 3-1. Water Level Sensor Transition to RJ11 Telephone Cable.

When locating the water level sensor along a wall or mounting block, provision must be made for similarly mounting this miniature printed circuit board nearby and for neatly routing the telephone cable from the miniature printed circuit board up to the electronics enclosure. We have tested connection of water level sensors to the WLD electronics enclosure using 10 foot long telephone cables. In theory, longer cables (25 feet or even 50 feet) should work fine; however, we have not tested longer cable connections.

Figure 3-2 is a schematic diagram for the wiring of the water level sensors through transitions to and from RJ11 jacks and cable and up to the WLD electronics printed circuit board on the enclosure.

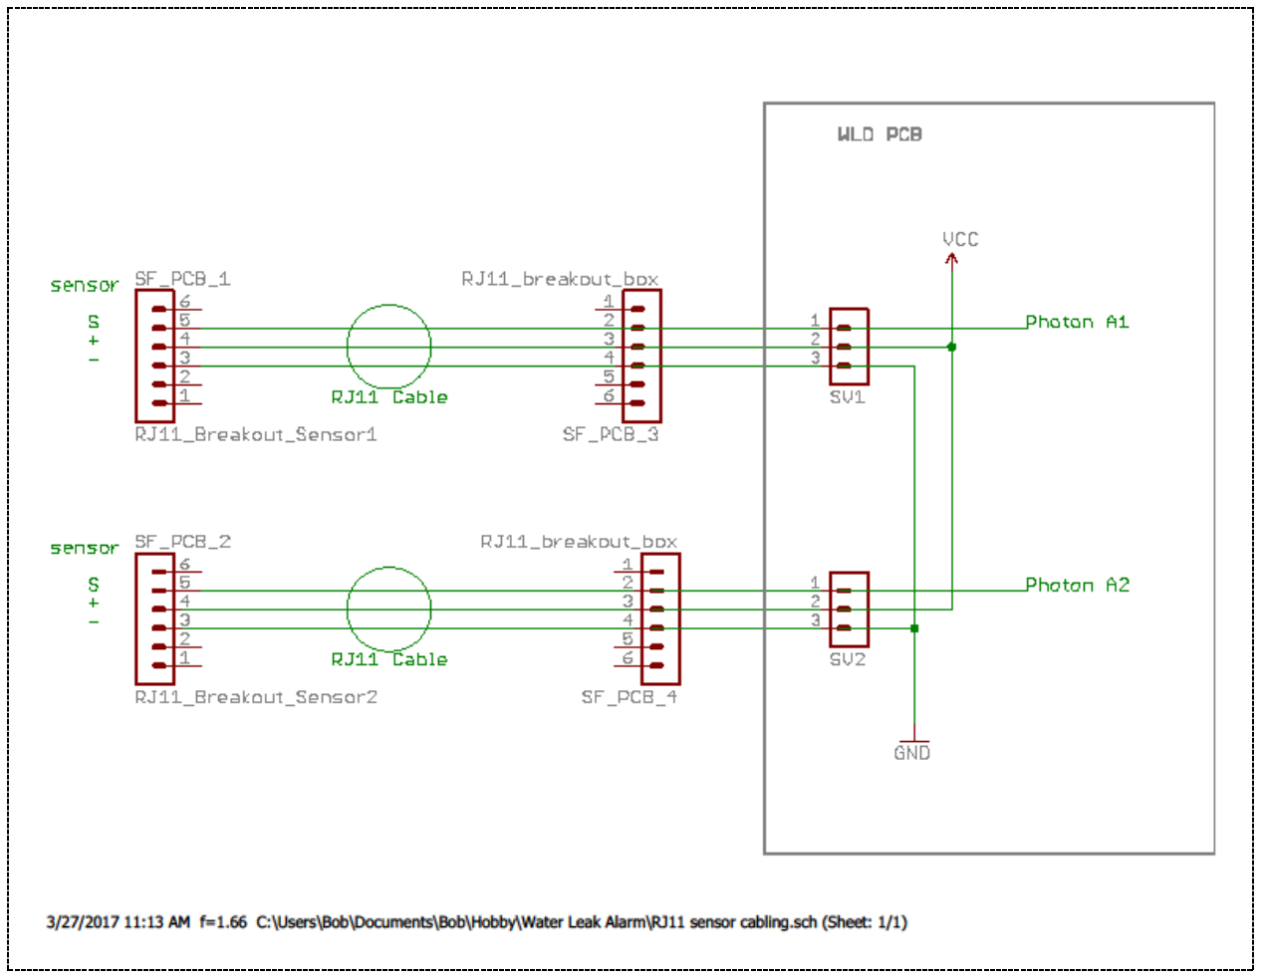
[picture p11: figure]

Figure 3-2. Water Level Sensor Cabling to WLD Electronics.

Note that the sensors connect to pins 5, 4 and 3 on the miniature PCB by the sensor, but the corresponding pins at the miniature PCB within the WLD electronics enclosure are pins 2, 3, and 4 respectively. Be careful to use the correct pins when wiring sensors to the miniature PCB and the corresponding miniature PCB to the main electronics PCB. Further details can be found in the document “WLD_Enclosure_Build_Instructions.pdf” which is included in the Documentation folder of this repository.

The WLD supports two water level sensors, so that two different locations can be monitored for leaks (e.g. a washing machine and a water heater in a basement or garage). It is best if you use both sensors, even if the sensors are monitoring two locations nearby the same appliance. If you wish to use only one sensor, you must ground the signal input pin at the 3 pin header connector for that sensor on the WLD electronics main PCB. This can be achieved by placing a female-female pin header jumper between pin 1 and pin 3 on whichever of the sensor connectors are not used. If you do not install either this jumper or a sensor to one of the sensor input connectors, ambient noise will trigger water leak alarms.

4.Local Operation.

The WLD has been designed for both local and remote operation. Local operation is described in this section.

In normal circumstances, the WLD is powered up and the green backlit pushbutton is lit continuously. This indicates that the WLD is powered up, connected to the Particle cloud via the Internet, reading temperature and humidity from the DHT11 sensor, and that the water leak detection is armed.

If either of the water level sensors detects a leak, the LED in the backlit pushbutton begins to blink and the piezo buzzer makes an annoying loud sound. This provides a local user with both an audible and visual alert to the leak condition. When the local user responds to the alarm, s/he can mute the buzzer sound by pressing the pushbutton. The backlight of the pushbutton will continue to blink until the alarm condition is cleared. The alarm condition is cleared whenever both water level sensors are dry. Clearing the alarm also automatically rearms the system for subsequent leak detection.

The servo meter on the front of the WLD enclosure continuously displays either the ambient temperature or the ambient humidity, depending upon the position of the toggle switch. When the toggle switch is in the Temperature position, the servo meter indicates the temperature which can be read off of either the Fahrenheit or Centigrade scales on the meter face; whichever scale is desired. When the toggle switch is in the Humidity position, the %RH can be read off of the humidity scale. Flipping the toggle switch position instantly changes the servo meter from temperature to humidity or visa-versa.

If the light on the backlit pushbutton is off (neither flashing nor lit constantly), then the WLD is not up and running properly. This may be due to one of the following conditions:

- Power is off.
- Photon is not connected to the Internet through Wi-Fi.
- Photon is connected to the Internet but not able to connect to the Particle cloud.
- Photon is cloud connected to Particle but the DHT11 temperature and humidity sensor is not responding.

If the light on the backlit pushbutton is off, check that the power supply is plugged into a working AC outlet and that the USB cable is connected to the power supply and to the WLD electronics. If power is connected, unplug the power supply or the power cable for 5 seconds and then plug it back in. The Photon should reset and reestablish all needed connections, if possible. This may take 30 seconds or more. If everything is working, the backlit pushbutton should light continuously. Otherwise, something did not connect properly.

In order to further diagnose a problem, it is necessary to observe the multicolor LED on the Photon module and also the blue “D7” LED on the Photon. These can be seen without removing the faceplate by looking in through the transparent right side of the WLD electronics enclosure. After unplugging and re-plugging the power supply, the following observations can be made:

- Power is on in the electronics. It may take a few seconds, but the Photon’s multicolor LED should start flashing different colors after power is applied. If not, there is a power problem.
- Photon acquisition. The Photon should blink green for a while, perhaps blink some other colors (but not red), and finally “breath cyan”. Breathing cyan means that the Photon is connected to the Particle cloud via Wi-Fi to the Internet. If the breathing cyan state is not reached after 30 seconds of power, consult the Particle documentation (https://docs.particle.io/guide/getting-started/modes/photon) for further definition of the problem.
- Setup. After the Photon starts breathing cyan, it enters setup mode. In setup mode, the Photon is connecting to the DHT11 sensor. This normally takes no more than 3 seconds. If setup mode completes correctly, the Photon enters normal operation with the backlit pushbutton LED on constantly and the servo meter reading the temperature or humidity, as selected by the toggle switch. When in normal operation, the Photon’s D7 LED flashes on and off at 4 second intervals. If the D7 LED is not flashing, then the Photon has not exited setup mode and there was a problem with the DHT11 communication. Make sure that the DHT11 is plugged into its socket correctly and solidly. If the D7 LED is flashing on and off but the backlit pushbutton is not lighting, then there is a problem with the wiring to the pushbutton (perhaps a wire has broken off).

5.Remote Operation (App, SMS Alarms).

The WLD sends standard SMS text messages to a specific phone number when an alarm condition is triggered: the presence of water; temperature that goes above or below specified limits. Alarm messages may be received by any device that supports receiving SMS text messaging - all cellular phones, tablets, and watches.

Remote access to the WLD is made possible through a smartphone app. Android installation package for this app (“WaterLeakDetectorApp.apk) is provided in the App folder on this repository. MIT App Inventor 2 source code for this app is also provided: “WaterLeakDetectorApp.aia”. See section 6.2, below, for further installation information. Use of this app is helpful, but optional.

The smartphone app provides real-time status from the WLD:
- Current temperature at the WLD (to one decimal place).
- Current RH at the WLD (to one decimal place).
- Status of the three alarms: low temperature alarm, high temperature alarm, leak alarm.

In addition, the app displays the current low and high temperature alarm thresholds and provides a button to set new temperature alarm thresholds.

5.1. SMS Alarms.

Three alarm conditions are processed by the WLD:
- Temperature is at or below the low temperature alarm limit.
- Temperature is at or above the high temperature alarm limit.
- A water leak is detected at either of the water leak sensors.

When an alarm condition is met, an SMS text message will be sent to the user’s mobile phone. An overview of this process is contained in the document “Water_Leak_Detector_Concept_V2” in the Documentation folder of this repository.

A low or high temperature alarm message will contain the nature of the alarm as well as the actual temperature measured when the alarm was triggered. A water leak alarm will contain the alarm message.

Each type of alarm is re-activated after the condition that causes the alarm is cleared; hence, a new alarm message will be sent immediately upon the alarm condition being met once more. However, for persistent conditions once an alarm message is sent, that alarm message will be held off for 24 hours. If the alarm condition persists for a full day, a new alarm message will be sent, followed by another one-day alarm holdoff. In other words, a persistent alarm condition will generate an SMS textual alarm message only once per day. The alarm hold off periods are also reset upon a power cycle of the WLD.

Note that alarm messages are immediate and independent of any smartphone app. In fact, alarm messages may be received by any mobile device that supports SMS text messaging. Alarm text messages are initiated by the Google Apps Script (part of this project) sending an email to the SMS gateway of the user’s cellular phone carrier. SMS text alarms may be sent to more than one device – simply add more lines of “EMAILapp.sendMail()” of the script. More information about this process can be found in the document:

https://github.com/TeamPracticalProjects/Connectivity_Tools_with_Particle_Devices/blob/main/TPP_Connectivity_Tools_Technical_Description.pdf (https://github.com/TeamPracticalProjects/Connectivity_Tools_with_Particle_Devices/blob/main/TPP_Connectivity_Tools_Technical_Description.pdf)

5.2. Smart Phone App.

This project includes a smartphone App. The App is currently available only for Android phones and tablets. The App allows the user to monitor and status the WLD in real-time. Figure 5-1 is an annotated screenshot of the App. See section 6 of this document for App installation instructions.

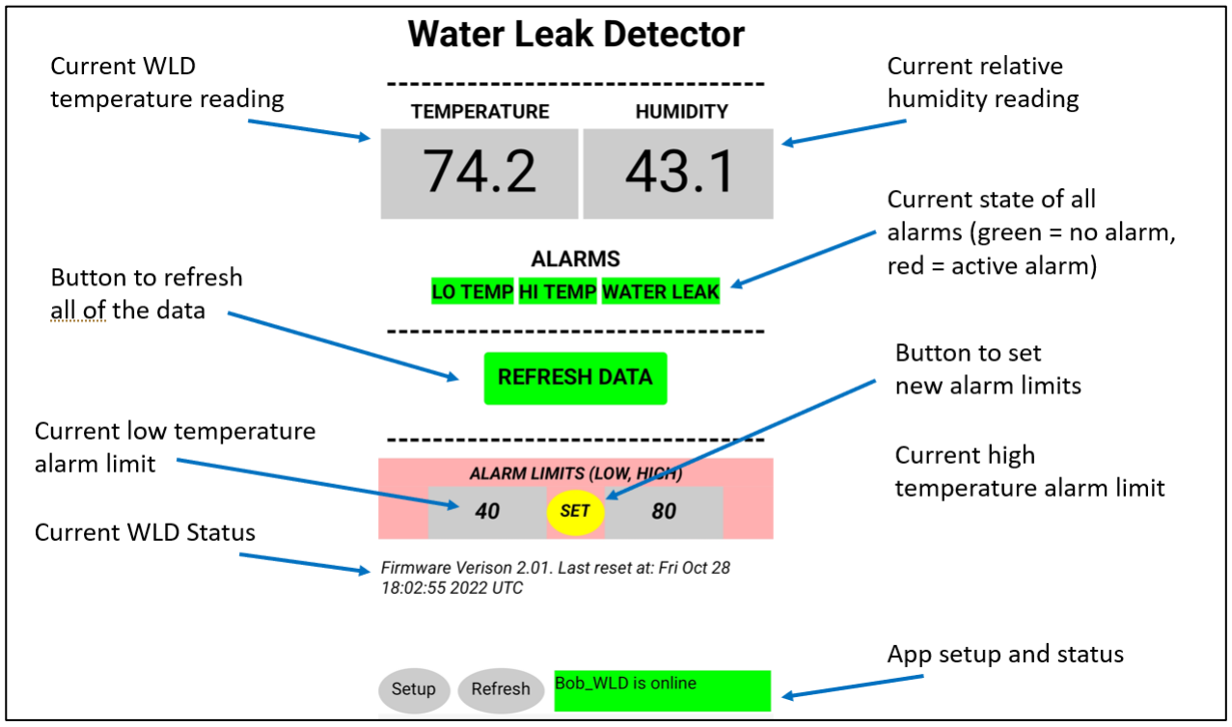
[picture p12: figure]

Figure 5-1. Smartphone App Screen.

The following is an explanation of the features and functions of the App, from top to bottom:

- TEMPERATURE. Displays the current temperature as measured by the WLD in degrees F (to one decimal place). The reading is updated each time that the REFRESH DATA button is tapped.
- HUMIDITY. Displays the current relative humidity as measured by the WLD in % RH (to one decimal place). The reading is updated each time that the REFRESH DATA button is tapped.
- ALARMS. The current status of three alarms is displayed in the following order: LOW TEMP(erature), HIGH TEMP(erature), WATER LEAK. The alarm text is always present, regardless of the alarm status. The alarm background color is: Green for no alarm, Red for a current alarm. The alarm status’ are updated each time that the REFRESH DATA button is tapped.
- REFRESH DATA. This button is tapped to refresh all of the data. This includes TEMPERAURE, HUMIDITY, and all three alarms. The current alarm limits (below) are also refreshed to show the latest information from the WLD.
- ALARM LIMITS. There are three parts to the ALARM LIMITS field. The leftmost part is the current low temperature alarm limit, in degrees F, as an integer. The rightmost part is the current high temperature alarm limit, in degrees F, as an integer. These fields are editable, so the user can change the alarm limits in the WLD by changing these values and tapping the SET button in the middle of this field. After tapping SET, the contents of the low temperature alarm limit and the high temperature alarm limit fields are stored into non-volatile memory inside the WLD and then the contents of both of these fields will be updated to show the current status of the WLD alarm limits. (Note that these values can also be set manually through use of the Particle.io console).

At the very bottom of the App screen are SETUP and REFRESH buttons and a STATUS field. These elements are part of our standard “Particle App Template”, see:

https://github.com/TeamPracticalProjects/Particle_App_Template

Briefly, tapping the SETUP button takes the user to the App’s setup screen, where the user can log into their Particle account and select the Particle device that the App communicates with³ .
The REFRESH button re-connects the App with the currently selected Particle device and also refreshes all of the App screen data (i.e. similar to REFRESH DATA). The status field shows which device the App is connected to and the connection status (Green denotes “connected OK”, Red denotes “not connected”, and Yellow denotes “awaiting response”). This field must be green in order for the App to work.

A note about the field and button colors and contents: After the REFRESH DATA or the SET button is pressed, the button color turns gray and stays gray until the operation is complete.

3

In this case, choose the Particle device you have used in your WLD.

After the button operation is complete, the button returns to its normal color (shown in figure 5-1). Temperature, humidity and temperature alarm limit fields turn blank (no displayed text) when the data is being refreshed. Only the newest data is displayed.

6.Software/Firmware Installation.

6.1. Firmware Installation and Servo Calibration.

The Firmware folder in this repository contains the Particle firmware that you need to flash to your WLD Photon. There are two subfolders:

- ServoCal/src: contains one file: “ServoCal.ino”. This is the source code that you need to flash to the WLD Photon in order to calibrate the servo that is used as a temperature and humidity meter.
- WaterLeakDetector: contains all source code and library files that are needed to flash the WLD operating firmware to the WLD Photon.

You must first build and test the WLD hardware before you flash firmware to the Photon. We strongly recommend that you thoroughly familiarize yourself with the WLD overall by reading this manual and the document “Water_Leak_Detector.pdf” before proceeding to build anything. Next, you will need to build the WLD printed circuit board, per the instructions in the document “PCB Assembly Instructions.pdf”. Finally, you will need to build one of the enclosures: either (1) “Enclosure Build Instructions Plastic Case.pdf”, or (2) “Enclosure Build Instructions 2D Box.pdf”, or (3) “Enclosure Build Instructions 3D Case.pdf”. The choice of which enclosure to use for your WLD is up to you. You will also need to claim a new Photon to your Particle account; see Particle’s documentation at:

https://docs.particle.io/quickstart/photon/

You should also familiarize yourself with the Particle Workbench IDE:

https://docs.particle.io/getting-started/developer-tools/workbench/

Once you have assembled all of the hardware, you will need to calibrate the servo meter. In order to do so, you need to flash the firmware “ServoCal.ino” to the WLD Photon and follow the instructions in the document “Servo_Meter_Calibration.pdf” in the Documentation folder in this repository. NOTE: you may use Particle’s WEB IDE or the Particle Workbench to flash this code to your WLD Photon.

After calibrating the servo meter, you will need to re-flash the WLD Photon with the WLD firmware. This firmware is found in the WaterLeakDetector subfolder in the Firmware folder in this repository. NOTE: There are multiple subfolders and firmware source code files in the WaterLeakDetector subfolder. We strongly recommend that you use the Particle Workbench to compile and flash this firmware to your WLD Photon. You must compile this firmware using the Particle Workbench and then you can use the Workbench to flash the compiled code to your

WLD Photon. We suggest compiling against Particle OS version 3.3 released. As of this writing, this is the latest version of the Particle OS that supports the Photon. You may use either the cloud compile and cloud flash options in the Workbench to do this, or else the local compile and local flash, if you prefer. Cloud compiling and cloud flashing is probably the fastest and easiest to use, while local compiling and flashing provides more information about the build progress.

6.2. App Installation.

You will need to install the smartphone app on an Android mobile phone or tablet if you want to read the status your WLD at any time. You do not need to install the app in order to get SMS text alarms from your WLD.

The smartphone app files are in the App folder in this repository. Two files are included:

- “WaterLeakDetectorApp.apk”: This is the installation package. You need to load this package onto your Android smartphone or tablet in order to install the App.
- “WaterLeakDetectorApp.aia”: This is the source code file, written in MIT App Inventor 2 (http://ai2.appinventor.mit.edu). You do not need this source code in order to install and use the App. The source code is provided for those users who wish to examine the code and perhaps modify the app to meet their unique needs.

In order to install the app on your Android device, you need to get the file “WaterLeakDetector.apk” loaded on to this device. There are several ways to do this:

- Download the .apk file directly to your Android device from this repository. Make note of where this file is downloaded to in the Android device’s folder hierarchy.
- Sideload the .apk file: Connect a USB cable from your development computer (where you downloaded this file) to your Android device. The Android device should appear as a memory device on your development computer. You can then drag and drop the .apk file somewhere on the Android device, e.g. in the Downloads folder. It doesn’t matter where you sideload this file to; just make note of where it is.
- Email the apk file from your development computer to yourself. Then read the email on your Android device and store the attachment (the .apk file) on the Android device, making note of where the file is stored.

However you choose to get the .apk file on to your Android device, you next need to use the Android device’s file explorer to locate the .apk file. Then tap on the file to install it. The Android OS will install the file on the Android device. NOTE: The installation process will warn you about the Android resources that the App requires – you need to accept this to install the App. Sometimes the Android installer will issue you a warning that the App is not trusted. This simply means that you didn’t download it from the Google Play Store. Go ahead and tap on the option to install it anyway.

Once the App is installed on your Android device, you may tap to open it. You can identify the App by the little leaky pipe icon that it presents on the Android device’s App selector screen.

Before continuing, power on your WLD and wait for the Particle Photon to connect to the cloud (the multi-color LED breathes cyan).

The first time that you open the App after installation, the App’s home screen will show a red ERROR! Message at the bottom right of the screen. This means that a Particle device has not been selected for the App to communicate with. Tap on the “Setup” button at the lower left of the home screen to get to the setup page of the App. On the Setup page, you need to type in your Particle login and Password where indicated and tap “Request Device List”. The gray button below that said “No Devices” will change to “Select device”. Tap on “Select device” to get a pick list of all of the Particle devices in your Particle account. Then tap on the device used for your WLD and then tap “Exit Setup” at the bottom of the setup screen to return to the App home screen. The status field at the bottom right of the home screen should turn yellow briefly and then turn green, indicating that the WLD Photon is on-line and the App can be used. If this field turns red, the selected Particle device is not on-line to the Particle cloud. Make sure that the Photon in your WLD is powered up and that the multicolor LED is breathing cyan, indicating that it is connected to the Particle cloud.

6.3. Script and Webhook Installation.

The Google Apps Script should be created and deployed first. The Script has a URL which needs to be copied and pasted into the webhook.

6.3.1. Script Installation.

Open an “Incognito” window on a web browser. Then log in to your Google account and open the Google “drive” app. Select “New” in the upper left hand corner and then find and select “Google Apps Script”; see figure 6-1. If you don’t see Google Apps Script in your Google account, you can add it by clicking on “+ Connect more apps”.

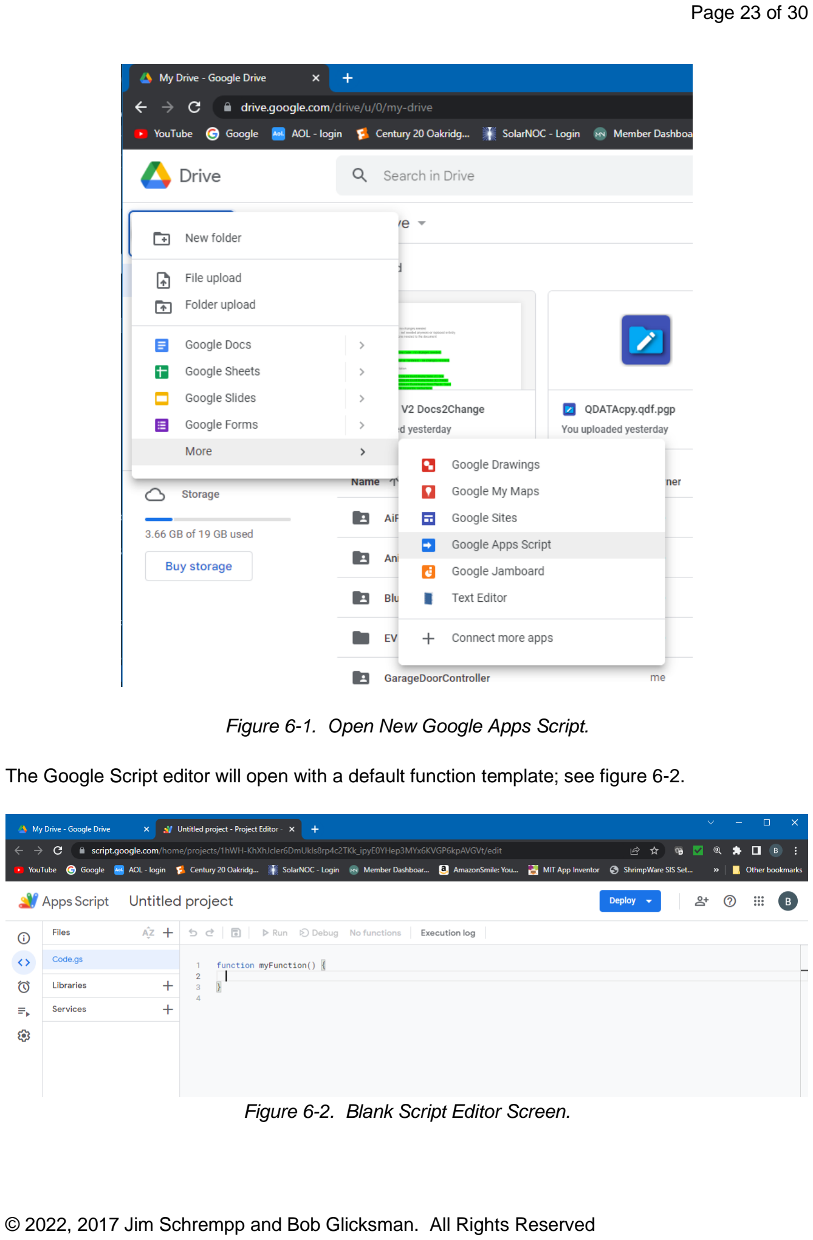
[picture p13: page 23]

Figure 6-1. Open New Google Apps Script.

The Google Script editor will open with a default function template; see figure 6-2.

Figure 6-2. Blank Script Editor Screen.

Delete the function template on the script editor screen so that nothing at all is in the editor window. Also, click on Untitled project at the top of the editor screen and give your project a name, such as “WLDAlarmScript”.

In the GitHub repository for this project, open the “Scripts” folder and open “Alarm_script.txt”. Select every line in this document and copy it to your computer’s clipboard. Make sure that you copy all lines (1-50). Then go back to the scripts editor and paste the script code in the editor window. Locate the line (line 10):

const targetBob = "<email for sms gateway goes here>";

Replace <email for sms gateway goes here> with the email address of your sms gateway account with your cellular carrier. The email address begins with your 10 digit cell phone number, @ sign, and then the address of the gateway. Gateway addresses for all cellular carriers in the United States can be found here:

https://jagerpro.com/help-center/sms-and-mms-gateway-list/

For example, mobile carrier “AT&T former Cingular” would be formatted:

111-222-3456@att.txt.net

If you are not in the US Pacific time zone, go to the script line 47 (begins with “var formattedDate = “) and replace the parameter “America/Los_Angeles” with the time zone that you want alarms reported in⁴
. Now save your script using the little disk icon near the top of the editor screen.

Check that the script is complete and correctly edited. Now click on the “Deploy” button near the top right of the screen. You will get a window similar to figure 6-3, below:

4 A list of these can be found at: https://en.wikipedia.org/wiki/List_of_tz_database_time_zones

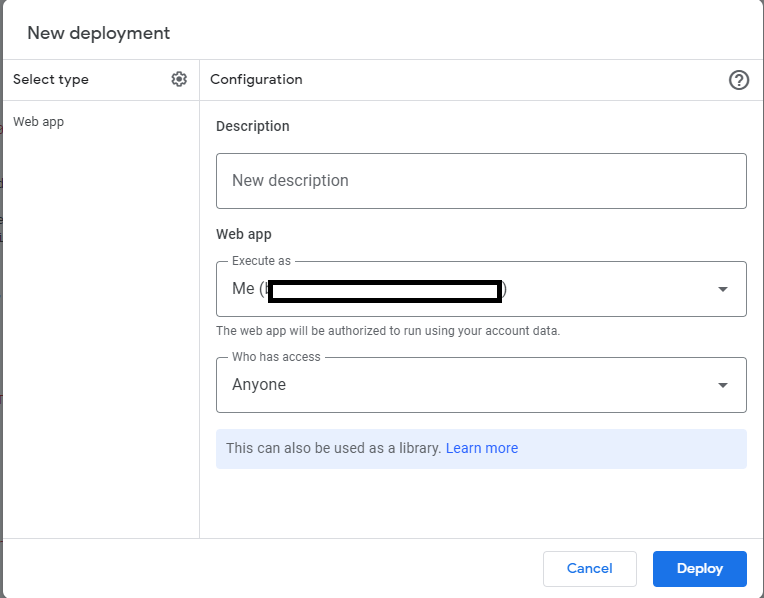
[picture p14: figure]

Figure 6-3. Script deployment.

Make sure to deploy the script as a “Web app”. Put something in the Description field, e.g. “Initial release” or “Version 1”. In “Execute as”, select the “Me” option. In “Who has access”, select “Anyone”. Double check your settings and click “Deploy”. You will see a popup with the App ID and the App URL. Click “Copy link” for the App URL to copy this link to your computer’s clipboard. If you accidently copy something else over this when you need it for the webhook, you can return to the Script editor “Manage deployments” and find and select it again.

6.3.2.Webhook Installation.

You create a new webhook by going to “console.particle.io” in your web browser and logging in to your Particle account. Select “Integrations” (the little star like icon in the left hand panel of the screen). Click on “NEW INTEGRATION” and click on “Webhook”. You will be presented with a form that has a number of fields to fill out. Fill them out as follows:

- Event Name: enter WLDAlarm (exactly as shown here – case sensitive).
- URL: paste in the script URL that you saved to your computer’s clipboard in the previous section.
- Request Type: POST

- Request Format: Web Form
- Device: Any
- Status: Enabled

You do not need to access the Advanced Settings. Just click on Create Webhook. You should see the webhook as in figure 6-4, below.

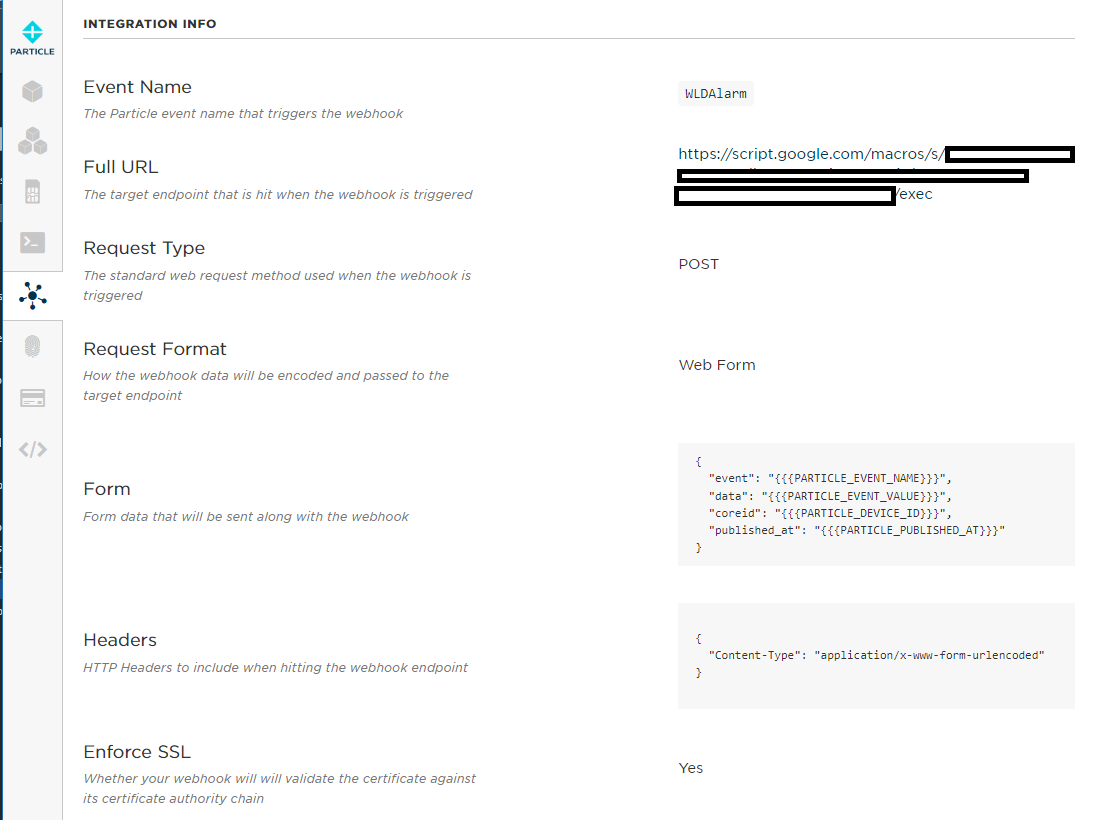
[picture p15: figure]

Figure 6-4. Webhook Setup.

The webhook is ready to go.

7.Testing Using the Particle Console.

The Particle console may be used to test out the hardware/firmware, and also to generate a test alarm to test that the webhook and Google Apps Script are working properly. Go to “console.particle.io” in your web browser and log in to your Particle account. You will see a list of the Particle devices in your account. Make sure that the WLD device is powered up and that the multicolored LED is breathing Cyan. Select the Photon device used in your Water Leak Detector in the Console. You will see the Console screen for this device. The Console screen has many helpful items, including device status, device health, etc. When using the Console for testing, you will use two sections of the Console screen:

- Events (on the left side of the screen).
- Functions and Variables (on the right side of the screen).

Figure 7-1 focuses in on the Functions and Variables. The WLD firmware has two cloud functions:

- “SetTempAlarmLimits”: used to set the low and high temperature alarm limits. Enter the data as “lowTempAlarmLimit,highTempAlarmLimit”; e.g. 40,85 as shown in figure 7-1. Clicking on “CALL” will set these limits (low temp alarm limit of 40 degrees and high temp alarm limit as 85 degrees) into the Photon’s non-volatile memory.
- “Send a test alarm”: clicking on “CALL” with no argument data will send a test alarm message to your configured SMS gateway and, from there, to your cell phone. You will also see the published alarm event in the Event window on the left side of the Console screen, as in figure 7-2. This shows that the Photon firmware sent out the test alarm event to the Particle cloud. If you don’t get an SMS text message within a few seconds, this means that either your webhook or your script was improperly set up. You can test that your mobile carrier SMS text gateway is working by sending an email to the gateway address that you configured in your Google Apps Script on the line:

const targetBob = ……

Below the Functions on the Console screen are the Cloud Variables:

- Info (string): Clicking on GET will return a string of information about the firmware – the version number and the time of the last reset (in UTC – not timezone adjusted).
- Temperature (string): Clicking on GET will return the currently measured temperature, in degrees F, rounded to one decimal digit.
- Humidity (string): Clicking on GET will return the currently measured relative humidity, in %RH, rounded to one decimal digit.

- Alarms (string): Clicking on GET will return a comma delimited string indicating the state of three alarms, in the order of: low temperature alarm, high temperature alarm, water leak alarm. A “0” indicates no alarm, a “1” indicates a current alarm condition. Note: this is the current status of the alarms which may be different from the alarm status when an SMS text was sent.
- LowTempAlarmLimit (string): Clicking on GET will return the low temperature alarm limit that is currently being used by the Photon firmware, rounded to the nearest integer value.
- HighTempAlarmLimit (string): Clicking on GET will return the high temperature alarm limit that is currently being used by the Photon firmware, rounded to the nearest integer value.

Note that you can force a low or high temperature alarm by setting the low temperature alarm limit higher than the current temperature, or setting the high temperature alarm limit lower than the current temperature. You will see the Alarm event publications in the Console Event panel, as depicted in figure 7-2.

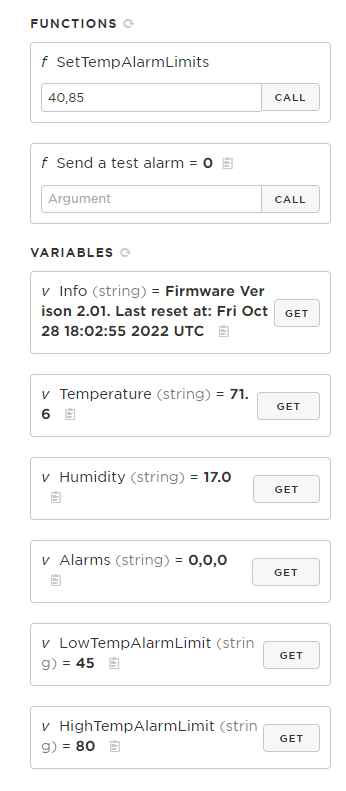
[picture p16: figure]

Figure 7-1. Variables and Functions.

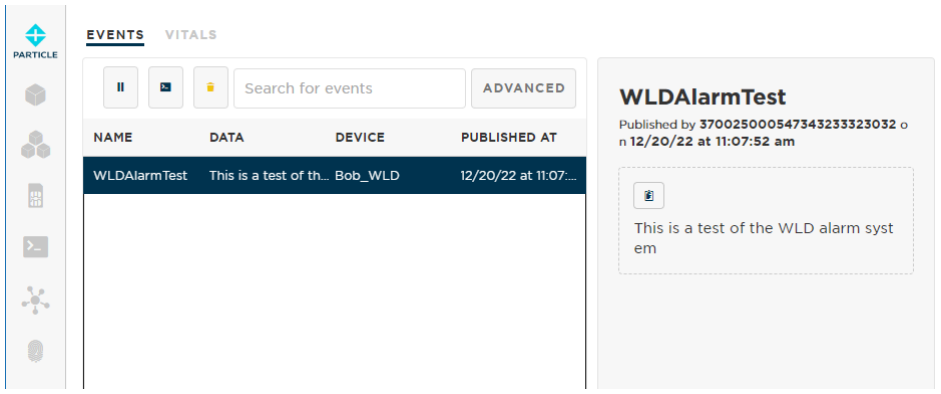
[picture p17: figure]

Figure 7-2. Test Alarm.

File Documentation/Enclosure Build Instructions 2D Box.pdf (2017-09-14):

# Water Leak Detector

## Enclosure Build Instructions for a 2D Box

By: Jim Schrempp and Bob Glicksman; updated 9/13/2017

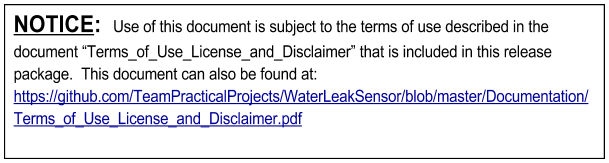
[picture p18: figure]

This document is © Copyright 2017 Bob Glicksman and Jim Schrempp. All rights reserved.

© 2017 Jim Schrempp and Bob Glicksman. All Rights Reserved

Table of Contents.

Introduction. | 3
What You Will Need. | 3
From the materials list: | 3
From your previous assembly steps: | 3
Tools: | 3
Step by Step Assembly Instructions | 4
Order or make the two box parts | 4
Install standoffs | 5
Add mounting bolts | 5
Mount WLD PCB | 5
Mount RJ11 PCBs | 6
Assemble The Bezel | 6
Mount Servo | 6
Mount toggle switch | 7
Mount push button | 7
Wire it up | 7
Mount bezel to chassis | 9
Appendix A - A More Enclosed Box | 11

Introduction.

This document contains instructions to fabricate a Water leak Detector (WLD) enclosure using 2D (flat) laser cut parts. A 2D enclosure is one of three options for housing the WLD electronics. The other two options are a 3D printed enclosure and an enclosure fabricated from a plastic box.
What You Will Need.

## From the materials list:

1. The two box parts
2. 8 ea. ½-inch 6-32 bolts
3. 8 ea. ⅜-inch 6-32 bolts
4. 16 ea. 6-32 nuts
5. 1 ea. Micro Servo
6. 4 ea. Female-Female 1-inch threaded standoffs 6-32
7. 4 ea. Male-Female 1-inch threaded standoffs 6-32

## From your previous assembly steps:

1. 2 ea. RJ11 jacks on breakout boards
2. 1 ea. WLD PCB
3. 1 ea. Backlit push button with wires soldered
4. 1 ea. Toggle switch with wires soldered

## Tools:

1. Screw driver

# Step by Step Assembly Instructions

## Order or make the two box parts

You will need to fabricate the two pieces of the box. Plans for the two pieces are in the file Graphics/CaseDial.pdf and the CorelDraw source is in Graphics/CaseDial.cdr. See: https://github.com/TeamPracticalProjects/WaterLeakSensor/tree/master/Graphics

Look at Page 2, labeled “open case”. There are two parts on the page: front and back.

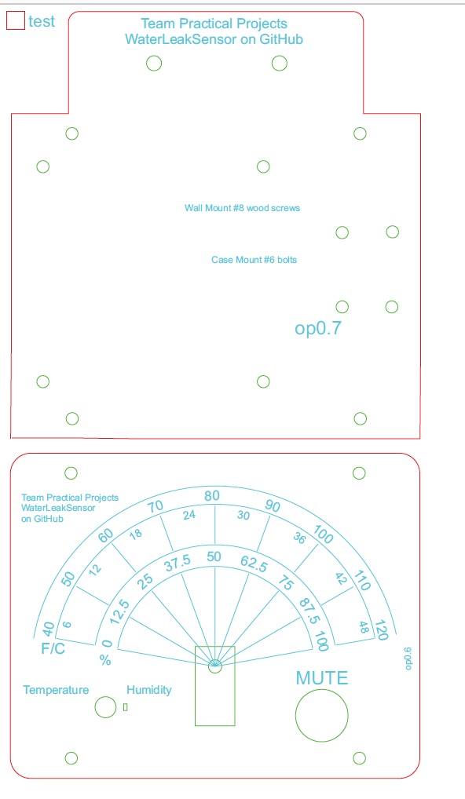
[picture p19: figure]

WLD Laser Cut Case

If you have access to a laser cutter, then you can easily cut the two pieces out of any 3mm (⅛ inch) material.

If you don’t have access to a laser cutter, then you can print out this page, paste the paper onto any 3mm (⅛ inch) material and carefully cut out and drill the pieces by hand.

You third option is to contact us at TeamPProjects@gmail.com and we may be able to sell you the case parts at our cost.

## Install standoffs

Screw each MF standoff into one FF standoff. You will now have 4, 2-inch long FF standoffs.

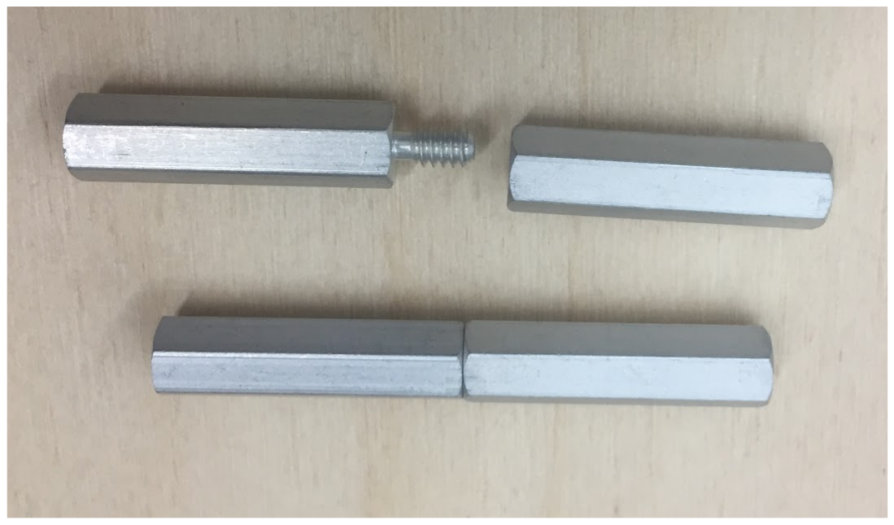
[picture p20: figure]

MF and FF Standoffs combined into one long FF standoff.

Use 4, ⅜-inch bolts to attach the standoffs to the backplate of the case.

## Add mounting bolts

Put ½-inch bolts into all the other mounting holes. Put a 6-32 nut on each and tighten.

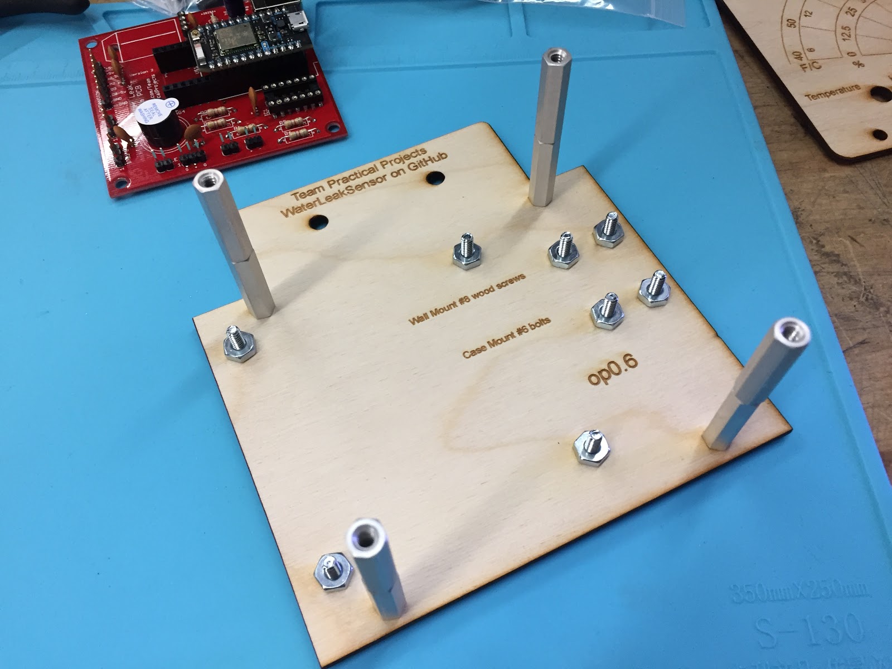
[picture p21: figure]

Standoffs in place. Bolts and nuts in all mounting holes.

## Mount WLD PCB

Place the WLD PCB over the four bolts. Add a nut to each screw and gently tighten.

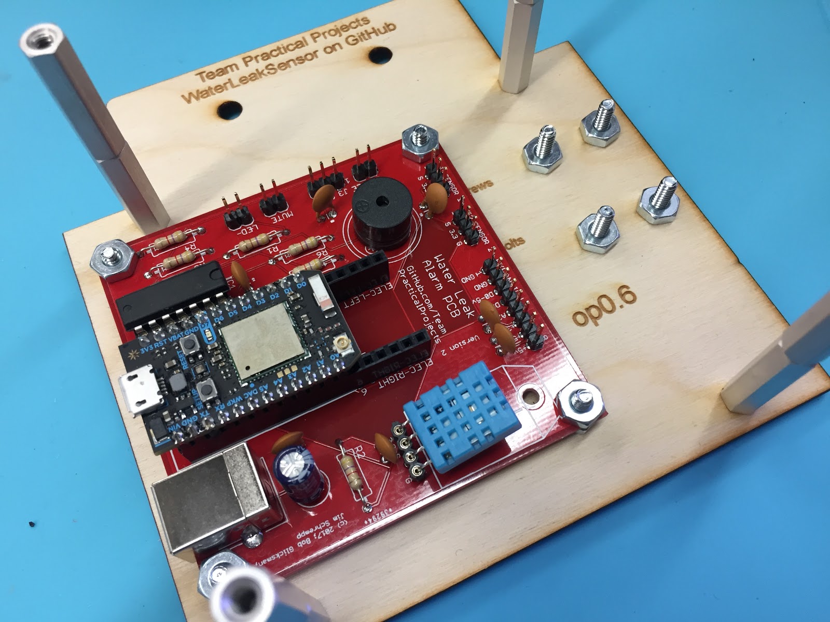
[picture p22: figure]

PCB in place.

## Mount RJ11 PCBs

Place the two breakout boards on the remaining bolts. Add a nut to each screw and gently tighten.

## Assemble The Bezel

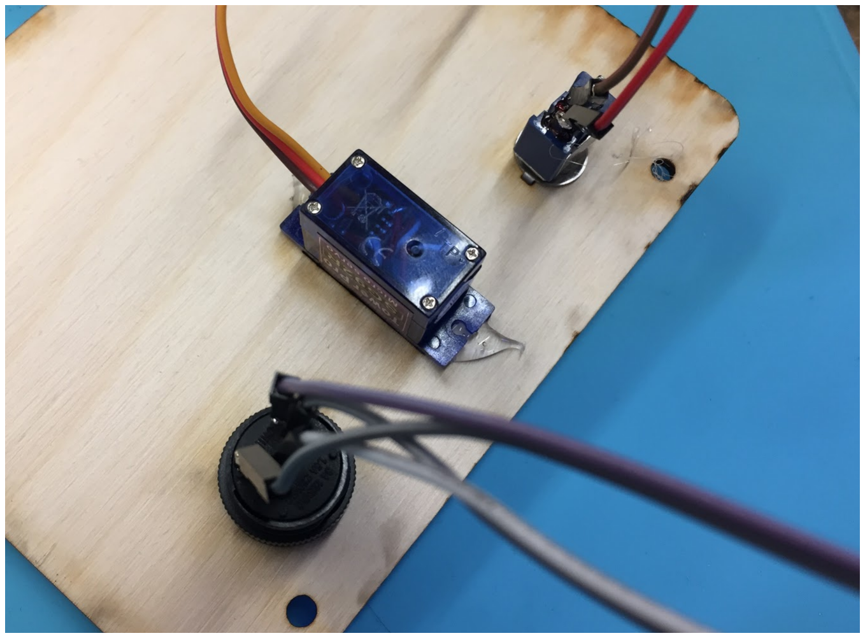
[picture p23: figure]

Back of bezel with components mounted.

### a. Mount Servo

Using hot glue, mount the Micro Servo to the top. Mount it from the back. Be sure that when looking at the front of the bezel, the rotating shaft is nearest the fan of numbers.

### b. Mount toggle switch

Remove the top nut from the toggle switch. Insert the toggle switch into the back of the bezel making sure the little bent tab fits into the provided slot. Put the nut on the toggle switch and tighten.

### c. Mount push button

Remove the round plastic nut from the push button. Insert the push button from the front of the bezel. The plastic nut has some rough fingers on one side. Thread the wires from the push button through the nut so that the rough fingers will contact the bezel and act as a locking mechanism. Tighten the nut.

## Wire it up

It is now time to connect all of the separate pieces together.

1. Wire up the RJ11 boards to their respective connectors on the PCB using three female-female header wires peeled off from the 40 wire ribbon cable. See the wiring diagram and photo below. Further instructions can be found in Section 3 of the “WLD Installation and User Manual” at:

https://github.com/TeamPracticalProjects/WaterLeakSensor/blob/master/Documentation/WLD_Firmware_Installation.pdf (https://github.com/TeamPracticalProjects/WaterLeakSensor/blob/master/Documentation/WLD_Firmware_Installation.pdf)

2. Connect the two wires from the toggle switch to the “toggle” pins on the PCB. There is no polarity to worry about here.
3. Connect the three wire cable from the servo motor to the servo connector (J3) on the PCB. Wires from left to right are: orange, red, brown.

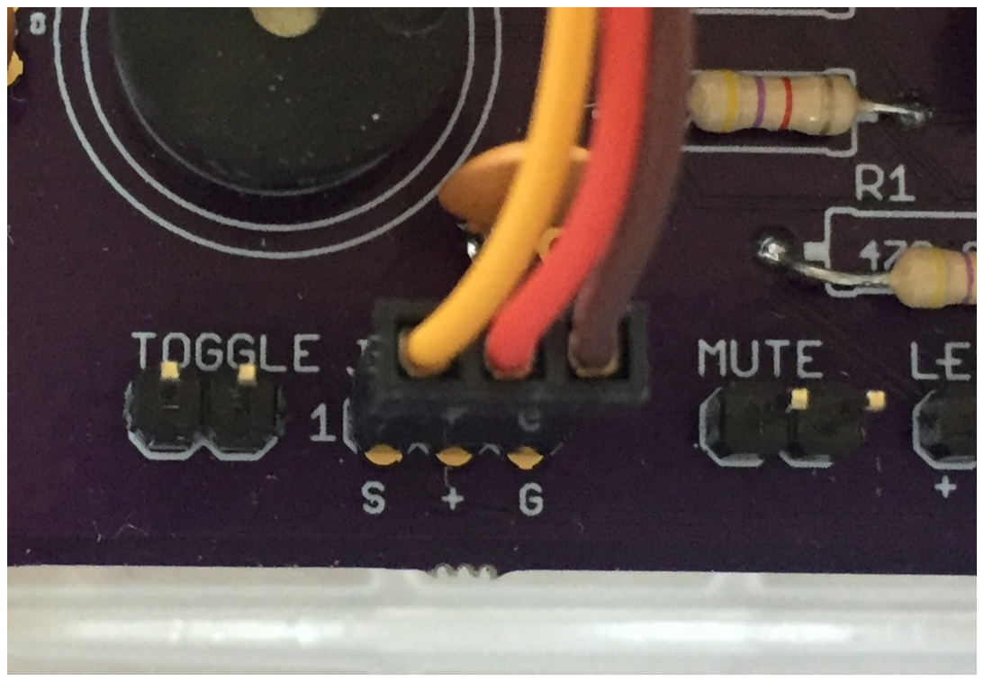
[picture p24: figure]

Servo cable connected

4. Wire the push button switch leads to the “mute” connector on the PCB. There is no polarity to worry about here.
5. Wire the pushbutton LED leads to the “LED” connector on the PCB. Be careful to observe the polarity marked on the switch and on the PCB. If you wire this backwards you won’t hurt your devices but the LED will not light.

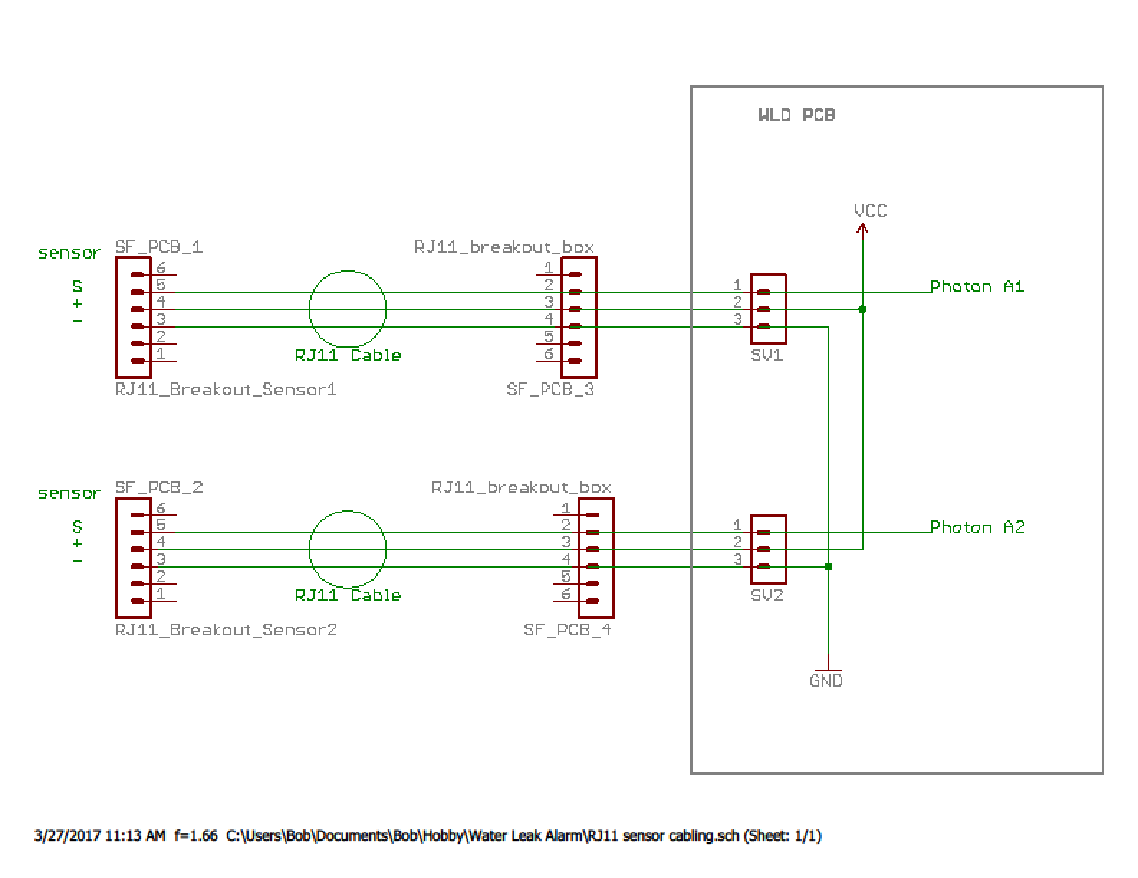
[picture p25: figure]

Diagram of wiring PCB to RJ11 boards, to sensors

## Mount bezel to chassis

Place the bezel onto the four standoffs. Secure it with four ⅜-inch 6-32 bolts. You’re done!

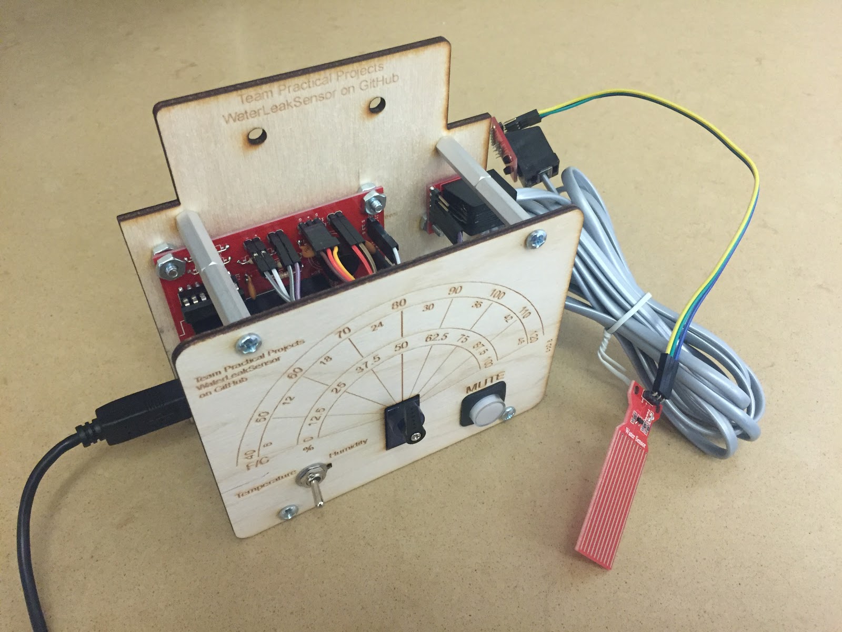
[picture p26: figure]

Completed water leak detector with one sensor

# Appendix A - A More Enclosed Box

In the file Graphics/CaseDial.pdf you will also find a third page with parts to make a more completely enclosed case. We do not fully document how to use these parts, but with some wood glue you should be able to figure it out.

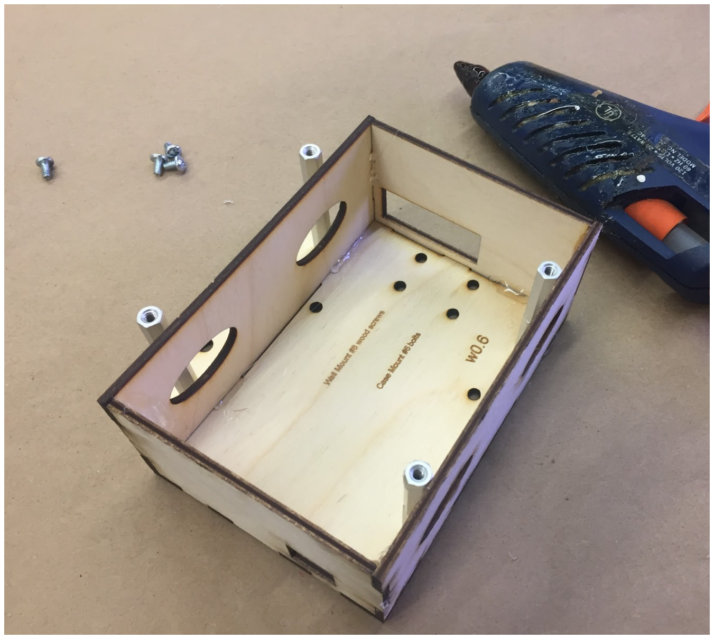
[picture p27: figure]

More enclosed box being assembled.

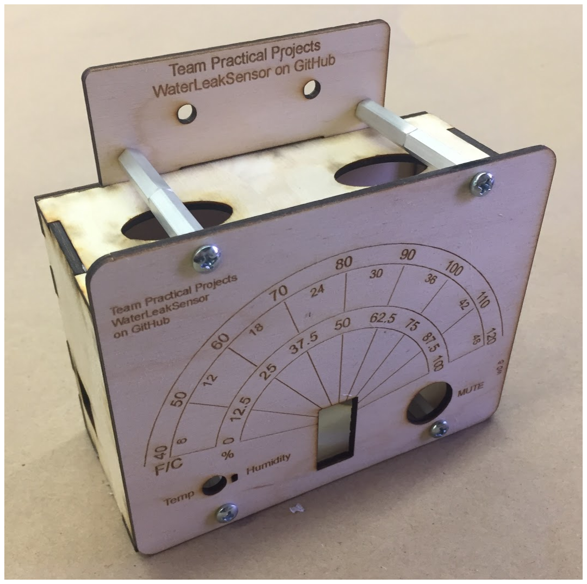
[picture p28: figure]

More enclosed box, assembled.

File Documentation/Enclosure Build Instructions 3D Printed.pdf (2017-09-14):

# Water Leak Detector

## Enclosure Build Instructions for 3D printed chassis

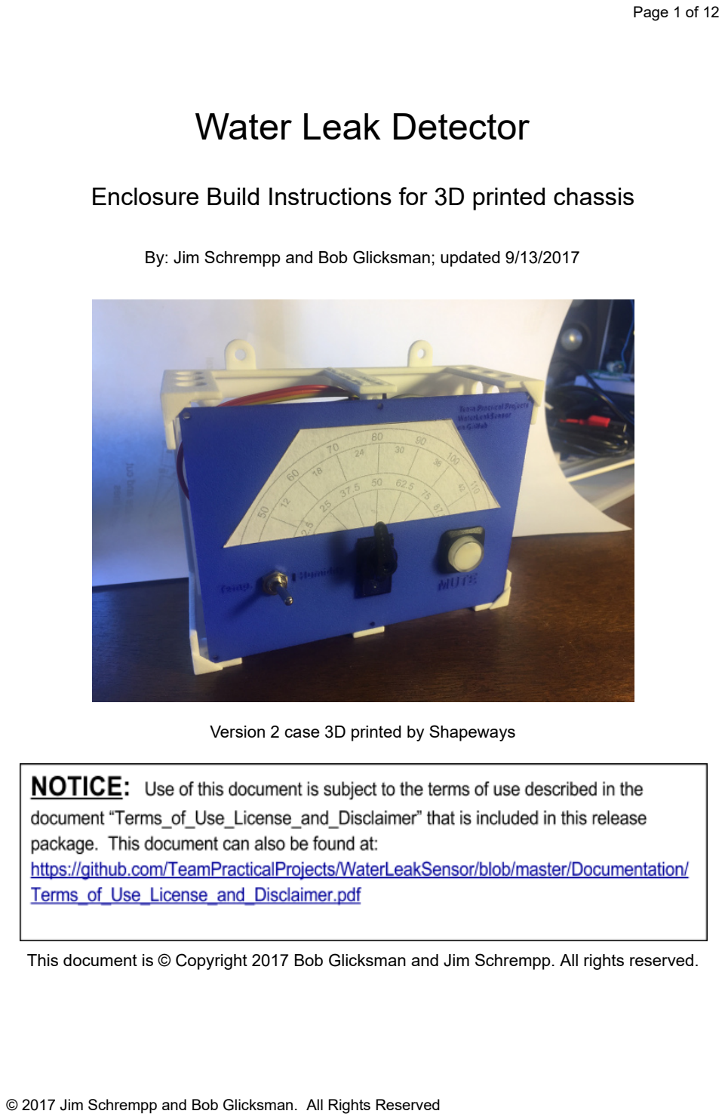
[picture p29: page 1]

By: Jim Schrempp and Bob Glicksman; updated 9/13/2017

Version 2 case 3D printed by Shapeways

This document is © Copyright 2017 Bob Glicksman and Jim Schrempp. All rights reserved.

© 2017 Jim Schrempp and Bob Glicksman. All Rights Reserved

Table of Contents.

Table of Contents. | 2
What You Will Need | 3
From the materials list | 3
From your previous assembly steps | 3
Tools | 3
Step by Step Instructions | 3
Order or make 3D parts | 3
Mount PCB | 4
Mount RJ11s | 4
Assemble Bezel | 5
Mount Servo | 6
Mount toggle switch | 6
Mount push button | 6
Glue on bezel pdf | 6
Wire it all up | 7
Mount bezel to chassis | 11

# What You Will Need

## From the materials list

1. Obtain a 3D printed chassis and bezel
2. Printed bezel pdf file
3. 8 ea. 6-32 bolts
4. 16 ea. 6-32 nuts
5. 1 ea. Micro Servo with 3 mounting screws

## From your previous assembly steps

1. 2 ea. RJ11 jacks on breakout boards
2. 1 ea. WLD PCB
3. 1 ea. Push button with wires soldered
4. 1 ea. Toggle switch with wires soldered

## Tools

1. Hot glue gun
2. White glue
3. Screw driver
4. Long nose pliers

# Step by Step Instructions

## 1. Order or make 3D parts

This enclosure requires you to either make or buy the 3D printed parts: chassis and bezel. The parts are currently available for purchase from Shapeways - a URL is provided in the parts list document. As of today the two parts cost about $40.

If you have access to a 3D printer, you could print the parts yourself. There are two STL files:

Case/casebottomskel.stl
Case/casebezel.stl

The models were created with FreeCAD and the two FCStd files are included in the Case folder (see: https://github.com/TeamPracticalProjects/WaterLeakSensor/tree/master/Case). If you do modify the case or bezel, do not remove the attribution to Team Practical Projects.

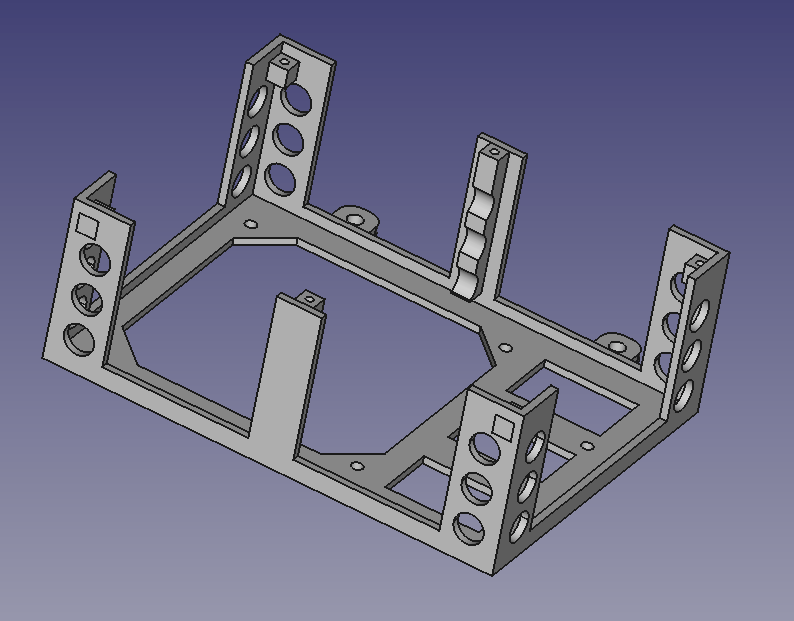
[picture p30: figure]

Version 2 Chassis in FreeCAD

## 2. Mount PCB

Position the WLD PCB in the chassis and use 4, ½-inch 6-32 bolts to hold it in place.

## 3. Mount RJ11s

Position each RJ11 breakout board in the chassis and use 4, ½-inch 6-32 bolts to hold them in place.

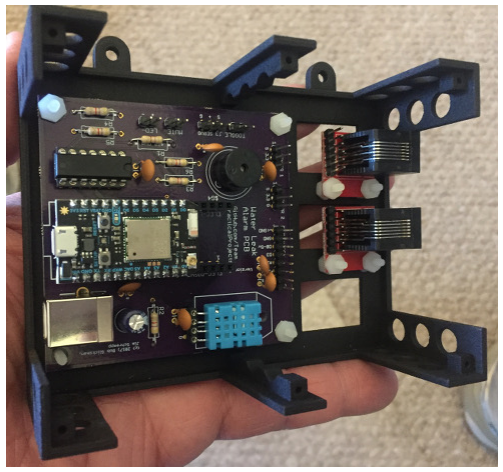
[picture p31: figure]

Chassis with PCB and RJ11 boards mounted.

## 4. Assemble Bezel

In this step you will add three components to the bezel.

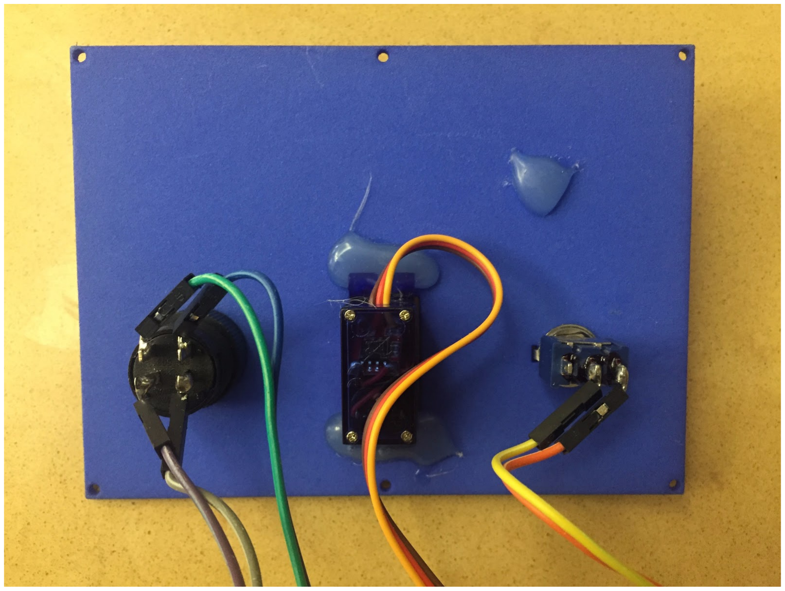
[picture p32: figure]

Back of 3D bezel with components mounted.

### a. Mount Servo

Place the servo into the bezel from the back. Be sure the rotating shaft is near the center of the bezel. Use some hot glue to hold it in place.

### b. Mount toggle switch

Remove the top nut and lock washer from the toggle switch. Place the switch into the bezel from the back, making sure that the small, bent registration tab fits into the supplied slot. From the front, add the lock washer and nut. Tighten the nut.

### c. Mount push button

Remove the round plastic washer from the back of the push button. Thread the push button wires through the round hole from the front of the bezel. Thread the washer back onto the push button base, making sure that the little plastic “fingers” are towards the bezel; these fingers help to lock the washer in place. Make sure the square faceplate of the button is square to the sides of the bezel and tighten the plastic washer.

## 5. Glue on bezel pdf

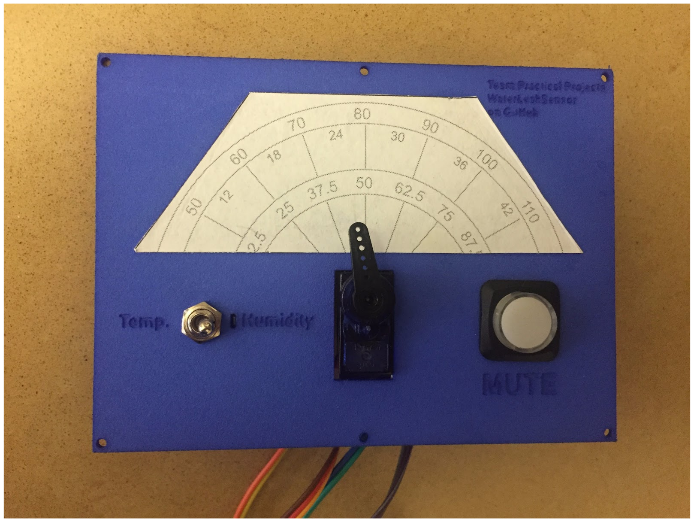
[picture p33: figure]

Finished bezel, version 2
Print out the file Graphics/CaseDial.pdf (see: https://github.com/TeamPracticalProjects/WaterLeakSensor/blob/master/Graphics/CaseDial.pdf)

Be sure to select the “actual size” choice in your printer properties.

Find the 3D case dial and cut it out along the dotted lines. Test that it fits into the depression on the face of the bezel; trim it if necessary.

Apply a bit of white glue to the depression on the face of the bezel and spread it out. Carefully place the printed dial into the depression and smooth it flat.

## 6. Wire it all up

It is now time to connect all of the separate pieces together.

1. Wire up the RJ11 boards to their respective connectors on the PCB using three female-female header wires peeled off from the 40 wire ribbon cable. See the wiring diagram and photo below. Further instructions can be found in Section 3 of the “WLD Installation and User Manual” at:

https://github.com/TeamPracticalProjects/WaterLeakSensor/blob/master/Documentation/WLD_Firmware_Installation.pdf (https://github.com/TeamPracticalProjects/WaterLeakSensor/blob/master/Documentation/WLD_Firmware_Installation.pdf)

2.

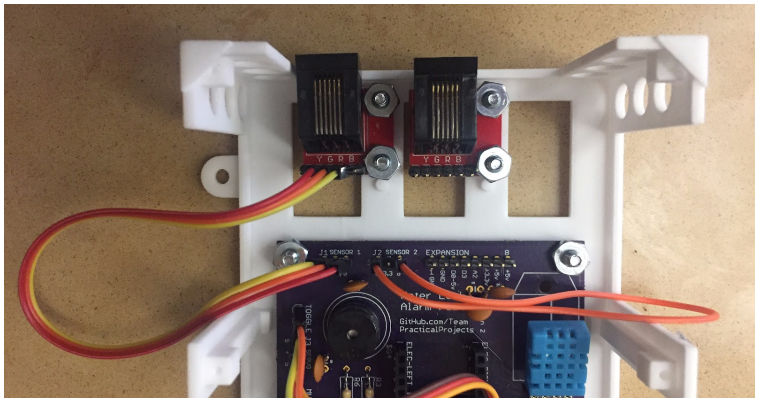
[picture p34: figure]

Showing one RJ11 connected to PCB with three wires. The second Sensor header is not connected and a jumper wire is in place on the PCB to prevent an alarm condition.

3. Connect the two wires from the toggle switch to the “toggle” pins on the PCB. There is no polarity to worry about here.
4. Connect the three wire cable from the servo motor to the servo connector (J3) on the PCB. Wires from left to right are: orange, red, brown.

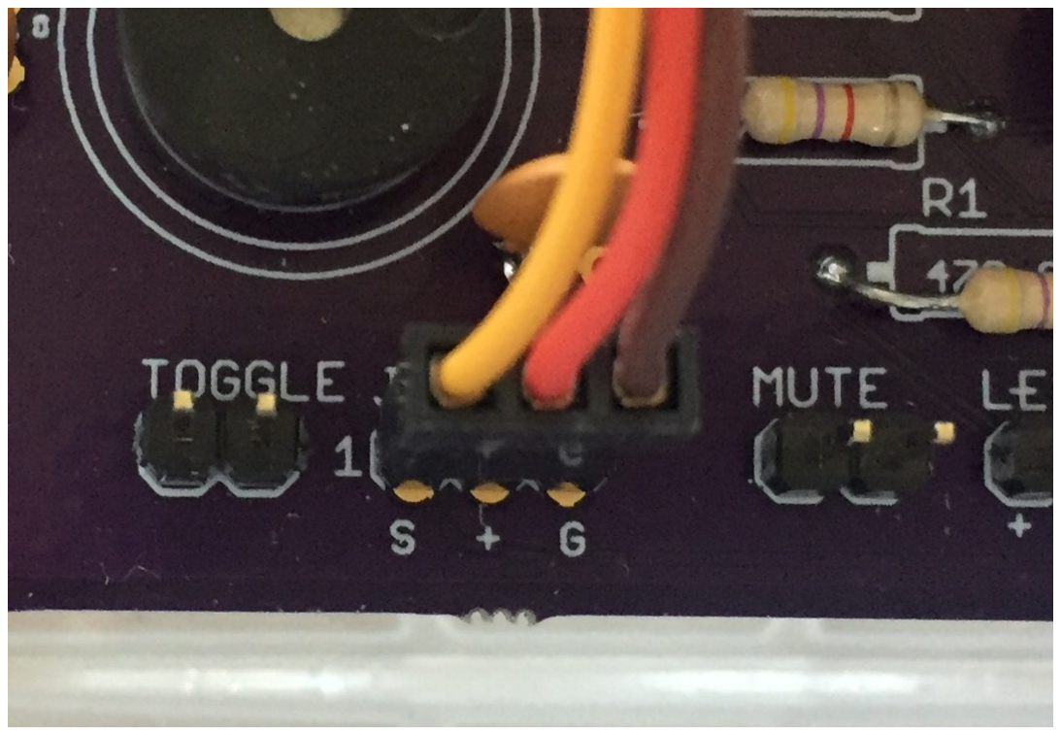
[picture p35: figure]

Servo cable connected

5. Wire the push button switch leads to the “mute” connector on the PCB. There is no polarity to worry about here.
6. Wire the pushbutton LED leads to the “LED” connector on the PCB. Be careful to observe the polarity marked on the switch and on the PCB. If you wire this backwards you won’t hurt your devices but the LED will not light.


Diagram of wiring PCB to RJ11 boards, to sensors

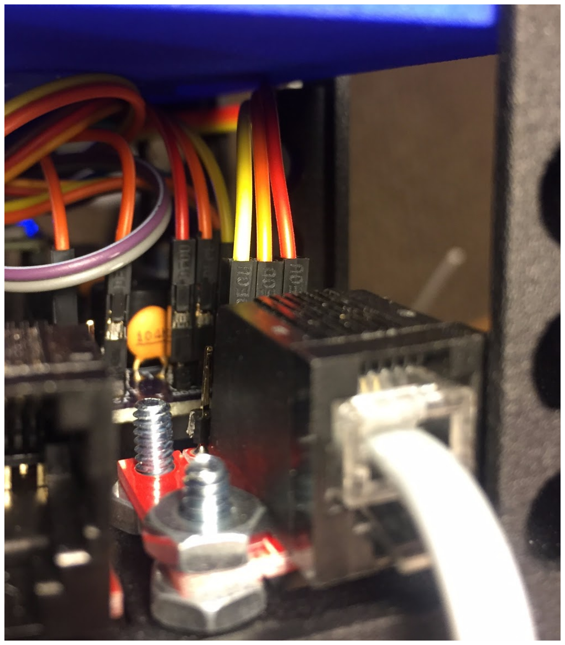
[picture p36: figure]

Note PCB to RJ11 cabling. Cable is twisted; yellow on right of PCB and on the left of the RJ11 breakout board.

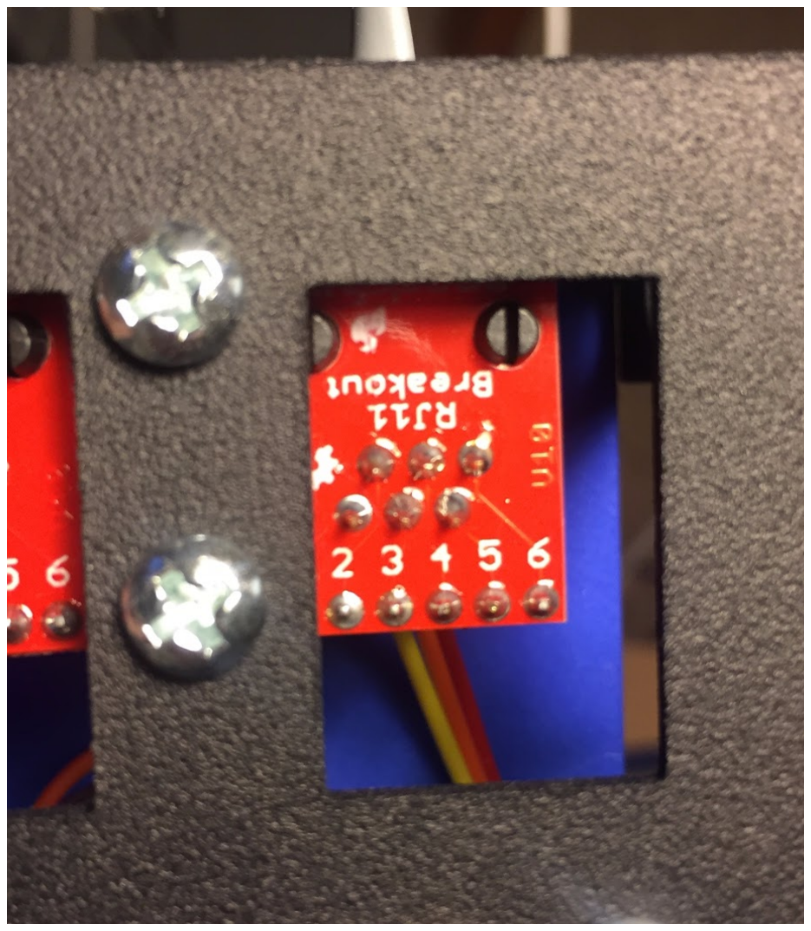
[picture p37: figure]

View of bottom of RJ11 breakout board.

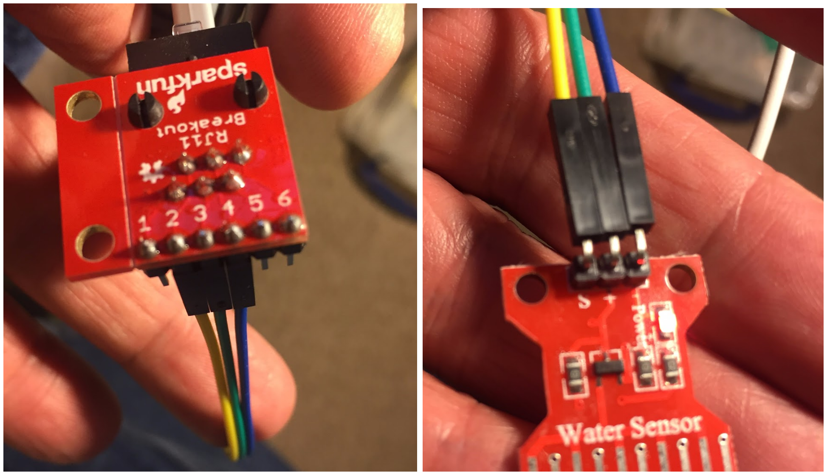
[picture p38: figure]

The far end of the sensor cable showing RJ11 breakout wired to a water sensor.

## 7. Mount bezel to chassis

The bezel is held in place to the chassis by four small covering tabs at the corners of the chassis. (See photo.) Place the bezel into position and under the left two tabs. If the bezel does not fit, then lightly sand the top of the bezel at just the tip of each corner until it does slide in.

Now gently flex the chassis at the upper right tab to allow the bezel to slip in under the tab. Do the same gentle flex at the lower right. The bezel should fit snugly, but not too tight.

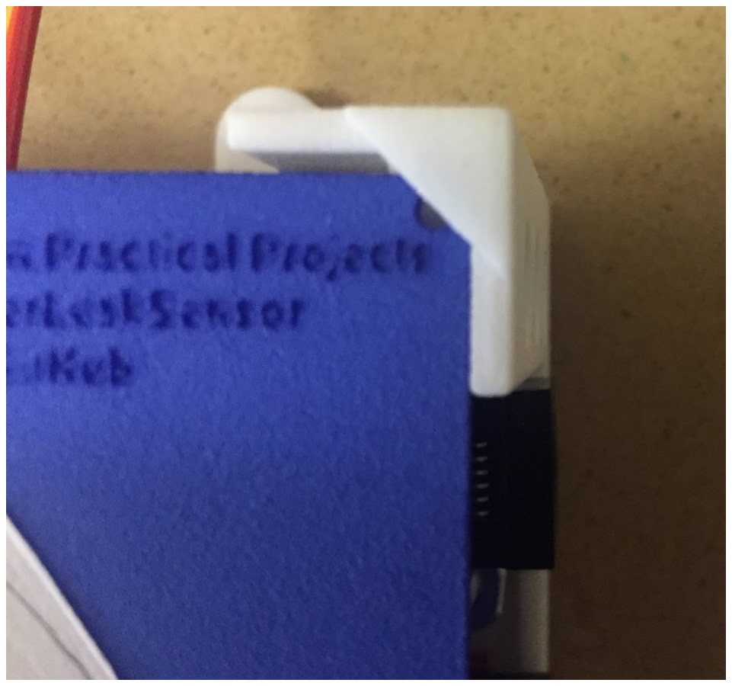
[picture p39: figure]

Detail of bezel corner under upper right chassis tab.

If you want your bezel to be more secure, you can use two of the mounting screws that came with the micro servo to attach the middle of the bezel to the middle supports of the chassis.

Your device is now completely built!

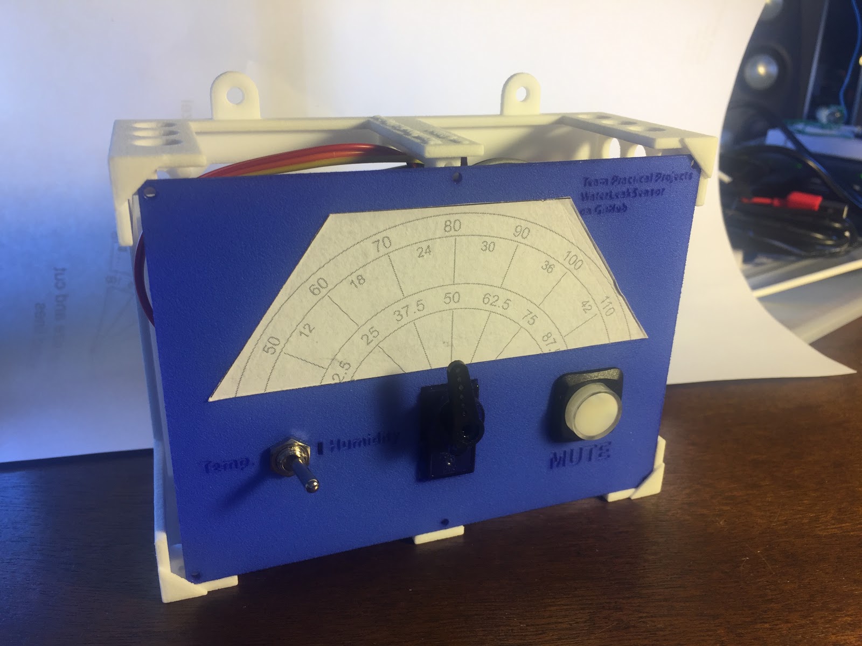
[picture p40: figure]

Version 2 of the 3D case, assembled.

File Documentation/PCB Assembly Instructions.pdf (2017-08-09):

# Water Leak Detector

## PCB Assembly Instructions

For PCB v2

This document is © Copyright 2017 Bob Glicksman and Jim Schrempp. All rights reserved.

© 2017 Jim Schrempp and Bob Glicksman. All Rights Reserved

## Table of Contents

Water Leak Detector | 1
PCB Assembly Instructions | 1
Notices | 1
Table of Contents | 1
Purpose | 2
What you will need | 2
Step by Step Instructions | 2
Resistors and Capacitors | 2
DIP Socket | 4
USB Connector | 5
Side Headers | 5
Side A | 5
Side B | 7
DHT11 Header | 8
Buzzer | 8
Photon Headers | 9
RJ11 Jacks | 10
Components | 11
Testing | 12

## Purpose

This document will provide step by step instructions for assembly of the Team Practical Projects Water Leak Detector printed circuit board.

You can find complete information about this project at: https://github.com/TeamPracticalProjects/WaterLeakDetector

Version 2 PCB with resistors already in place.

## What you will need

In addition to the electrical parts listed in the bill of materials spreadsheet, you will also need the following:

1. Soldering Iron
2. Solder
3. Diagonal cutters
4. Small nose pliers
5. Wire strippers
6. Masking tape

## Step by Step Instructions

### Double check the PCB

If you have a multi-meter it is a good idea to double check the PCB before starting the build.

Locate the 8 pad Expansion header on one edge of the PCB. Use your multi-meter in resistance measuring mode to test that there is no continuity between the pads labeled GND and the pads labeled +3.3v and +5v. If you find that there is connectivity between these pads, then you have a bad PCB.

### Resistors and Capacitors

Locate the single 470 ohm resistor. Locate the one position on the PCB for the 470 ohm resistor (“R1”). Bend the resistor leads to fit the holes on the PCB, insert the resistor, and solder it in place. Trim the extra wire with the diagonal cutters.

Now locate the 4.7K ohm resistors (“R2” through “R6”). Bend the leads of each to fit the locations on the printed circuit board. While not required, it is considered good practice to have them all face the same direction on the board. Solder them in place and trim the extra wire.

Find the 0.1 micro farad disc capacitors (there are 7 of them). Again, it is just good practice to have them all face the same direction. Place them on the PCB and solder them in place. Trim the extra wire.

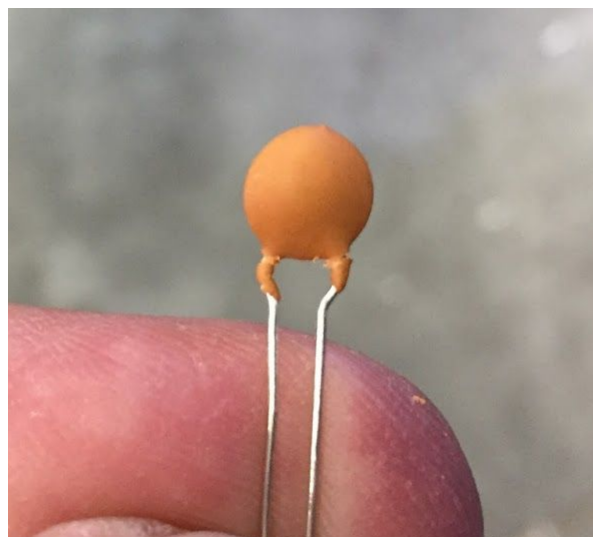
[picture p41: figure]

You may need to bend the leads in slightly, as shown here.

Find the one electrolytic capacitor and its location on the PCB. NOTE the polarity of the capacitor and the holes on the PCB. The negative side is the side with the silver stripe and it must be connected to the “-” round pad on the PCB, with the other side connected to the square pad on the PCB. Solder the capacitor in place and trim the extra wire.

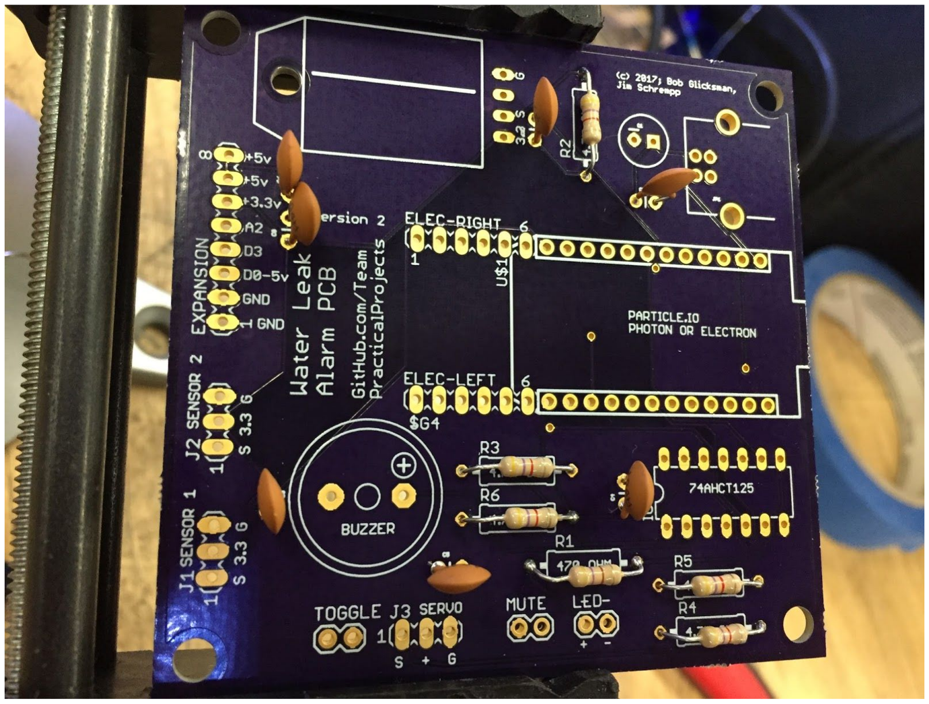
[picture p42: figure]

PCB with resistors and disk capacitors in place.

Note that there is one place where two of the capacitors are placed very close together. The two leads that are near each other are both grounded so it does not matter if those two leads touch. If we make a Revision 3 of the PCB then we will correct it there.

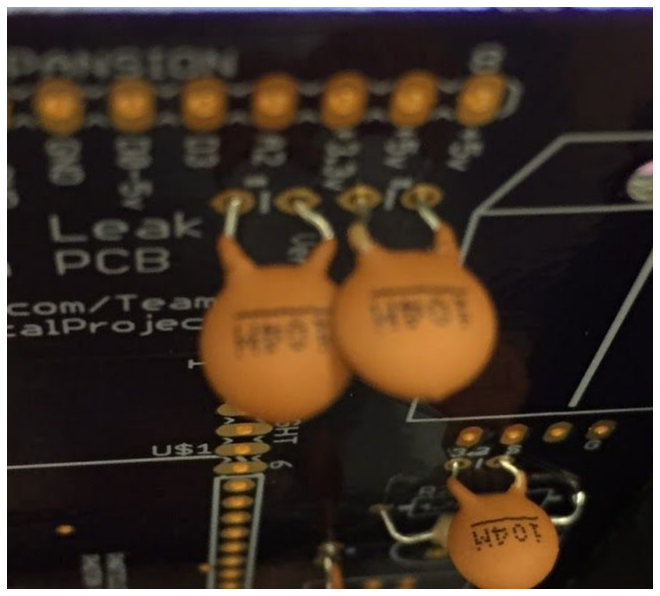
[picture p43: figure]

Two capacitor leads are close, but in this case it does not matter if they touch.

### DIP Socket

Locate the dual in-line socket. Note that one end of the socket had a small divot in it. Note that the icon on the PCB also has a small divot in it. Orient the DIP socket so that the divot is in the location indicated on the PCB. Use a piece of masking tape to hold the DIP in place and solder it to the board.

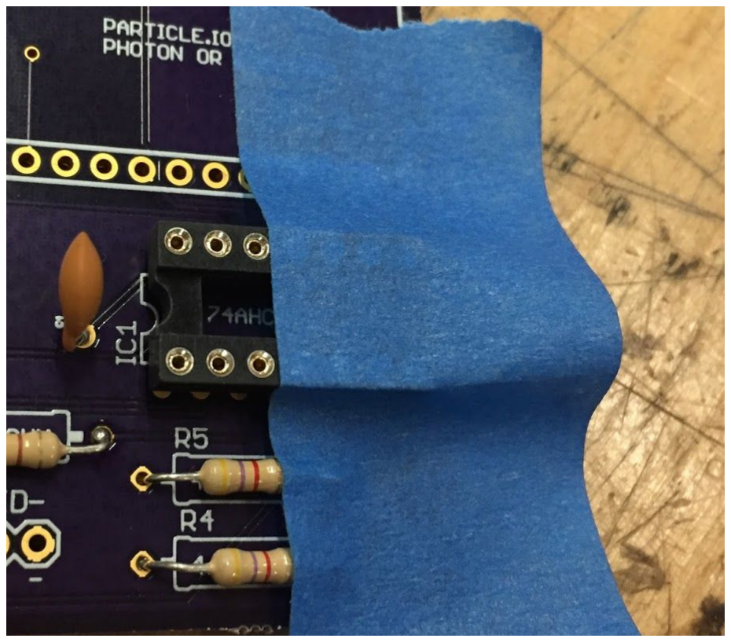
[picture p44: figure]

DIP held in place for soldering.

### USB Connector

Locate the USB connector. Place it on the PCB. Note that you will have to press gently but firmly to seat the big case pins into the PCB. Solder the four pins in place. Then solder the two big case pins to the PCB. Be sure to flow enough solder to fill the big holes.

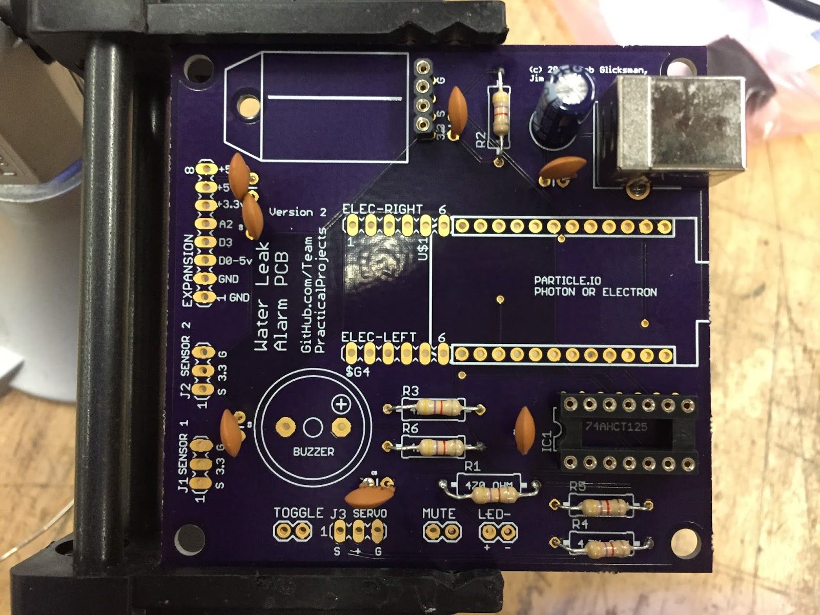
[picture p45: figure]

USB connector is soldered in place

### Side Headers

Side A
Locate the snap apart male pin headers. Make three pieces: one 8-pin and two 3-pin headers.

Locate one of the Photon headers. We will use the Photon header to hold the other headers in place while we solder them. Place the long pins of the 8-pin and 3-pin headers into the Photon header; do this so that the small headers are the correct distance apart to fit into their locations on the PCB.


Two snap apart headers in the Photon header

Now place the snap apart header pins into the PCB and use a bit of masking tape to hold them in place.


Headers in the PCB.


Ready to solder.

Now turn the PCB over and solder the headers to the PCB. Remove the tape and pull off the Photon header.

Side B
Locate the snap apart male pin header and create one 3-pin header and three 2-pin headers. Insert these into the Photon header at the correct locations to fit the PCB.


Snap apart headers in the Photon header


Note how the snap apart headers are in the correct positions to be inserted into the PCB.

Use masking tape to hold the headers in place and solder them to the PCB.


Second set of headers ready to solder.

Pull the photon header from the snap apart headers.

### DHT11 Header

Locate the 4-pin header for the DHT11. This header has round pin holders. Use masking tape to hold it in place and solder it to the PCB.

### Buzzer

Locate the buzzer. Note the polarity indication on the buzzer and on the PCB board. Insert the buzzer and solder it in place. If there is a protective label over the buzzer, remove and discard it.

### Photon Headers

It is critically important that the Photon headers are installed correctly. The procedure here is fool proof.

First insert the Photon into the two Photon headers.

Now place the Photon and headers into position on the PCB.


Photon in headers and on PCB.

Hold the Photon and headers in place with a bit of masking tape. Invert the board and solder the two ends of each header to the PCB.


The ends of each Photon header are soldered.

Now remove the Photon from the headers and set it aside. Solder all the remaining Photon header pins to the PCB. We remove the Photon to make sure it is not exposed to high heat while soldering the pins.

### RJ11 Jacks

Locate four RJ11 jacks and two sets of RJ11 breakout boards.

Break the breakout boards apart so that you have 4 pieces. Insert the RJ11 jacks into each board - you may have to press them gently but firmly into the break out boards. NOTE that the RJ11 jacks are inserted to the side of the breakout boards that say YGRB.


The RJ11 connector on a breakout board. You will make 4 of these

Invert the boards and solder the six pins of each RJ11 connector to their breakout board.
Now make four 3-pin snap apart male headers and solder them to the RJ11 breakout boards. NOTE: on two of the RJ11 boards you will solder the headers to pins 3, 4, and 5 and on the other two RJ11 boards you will solder the pin headers to pins 2, 3 and 4. Insert the snap apart headers on the same side of the board as the RJ11 connector.

## Components

Locate the 74AHCT125 DIP chip. Use straight pliers to gently bend the pins on one side and then the other so that they will fit into the DIP socket on the board. Note that the DIP chip has a small divot or white dot on one end. Insert the DIP chip into the socket so that the divot or dot aligns with the mark on the socket.

Once inserted, look closely at the pins to make sure they are all in their socket. It is easy to have a pin bend and not be inserted correctly.

Locate the DHT11, a blue rectangular component. Insert its four pins into the socket.


Mount the Photon into its socket with the micro USB connector facing forward (the side of the board where the large USB connector is located). Make sure that pin 1 of the photon is as far forward on the connector as it can go, When the Photon is installed in its socket, there will be 6 empty pins on each side at the back of the Photon. These pins are not used (they are for use with the Particle Electron 3G module).

## Prepare Switches

Since you have your soldering iron hot, now is a good time to attach wires to the panel switches.

Locate the two zip wire pieces, one with 2 conductors and one with 4 conductors. Cut the female connectors from one end of all the wires. Using wire strippers, carefully strip off 0.25 inch of insulation from the ends. Use a wire stripper for 22 gauge stranded wire. It is easy to break the strands, so be gentle. We recommend stripping off 0.125 inch at a time.

Comb the bare strands to a neat look, twist them slightly if needed. Use the soldering iron to tin the bare ends of each wire.


Two zip conductors stripped and tinned.

Locate the toggle switch. Solder the two conductor zip wire to the center and one end leads of the switch.

Locate the LED push button switch. Solder the four conductor zip wire to the four leads.


Zip wires soldered to switches.

## Testing

Carefully inspect all solder joints; a magnifier will help. Make sure each solder joint has enough solder on it. Make sure that none of the solder joints has bridged over to another solder joint.

At this point you should have already set up your Photon and tested it with the BlinkLED app from Particle.io.

Insert your Photon into the PCB. Be sure the Photon is all the way to one end of the header socket, with the micro USB connector at the edge of the board.


Photon mounted on PCB.

Connect USB power to the large USB connector on the PCB - not to the connector on the Photon. Your Photon should power up, connect to your Wifi, and run the BlinkLED app. This test shows that the WLD PCB is able to power the Photon.

Your PCB build is now complete. You can move on to the next module build process.

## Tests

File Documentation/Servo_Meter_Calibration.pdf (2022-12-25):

# WLD Servo Meter Calibration

Theory and Procedure.

By: Jim Schrempp and Bob Glicksman; updated 12/25/2022

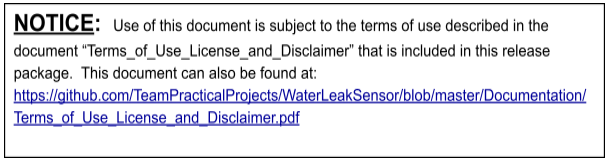
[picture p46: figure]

This document is © Copyright 2022, 2017 Team Practical Projects, Bob Glicksman and Jim Schrempp. All rights reserved.

© 2022, 2017, Team Practical projects, Jim Schrempp and Bob Glicksman; all rights reserved. Subject to “Terms of Use, License and Disclosure”

Table of Contents.

Table of Contents. | 2
1. Introduction. | 3
2. Servo Calibration Procedure. | 3
3. Theory of Servo Calibration. | 5
3.1. Servo end points calibration. | 5
3.2. Servo position calculation for temperature. | 6
3.3. Servo position calculation for humidity. | 7

1. Introduction.
When the servo is mounted onto the meter scale, it needs to be calibrated and scaled in order to convert temperature and humidity to a servo position number that reads out the correct value. Since every servo is a little bit different, each servo should be calibrated and the calibration values should be recorded and placed into named constants within the WLD firmware.

In order to calibrate your servo using the procedure in this document, you will need to build the WLD printed circuit board, per the instructions at:

https://github.com/TeamPracticalProjects/WaterLeakSensor/blob/master/Documentation/PCB%2 0Assembly%20Instructions.pdf (https://github.com/TeamPracticalProjects/WaterLeakSensor/blob/master/Documentation/PCB%20Assembly%20Instructions.pdf)

You will also need to mount your servo to the faceplate (bezel) and attach an indicator (servo horn) to the servo shaft so that you can read the servo position on the meter scale. This step varies slightly with the type of enclosure that you are building. Typical instructions can be found in the document:

https://github.com/TeamPracticalProjects/WaterLeakSensor/blob/master/Documentation/Enclosu re%20Build%20Instructions%20Plastic%20Case.pdf (https://github.com/TeamPracticalProjects/WaterLeakSensor/blob/master/Documentation/Enclosure%20Build%20Instructions%20Plastic%20Case.pdf)

Finally, you should complete the build of your WLD, flash the WLD firmware to the Photon on the PCB, and test out you WLD per the “WLD Installation and User Manual”:

https://github.com/TeamPracticalProjects/WaterLeakSensor/blob/master/Documentation/WLD_Installation_and_User_Manual_V2.pdf. (https://github.com/TeamPracticalProjects/WaterLeakSensor/blob/master/Documentation/WLD_Installation_and_User_Manual.pdf)

Once you have completed building and testing your WLD, you may proceed to calibrate the servo meter using the procedure described below. Note that calibrating the servo requires you to flash a different program to the Photon which is used to obtain calibration values, then modify the WLD Firmware using these calibration values in lieu of the default values, and re-flashing the WLD Firmware back to your Photon.

2. Servo Calibration Procedure.
Once you have completed a working WLD, you will need to flash a servo calibration program onto your WLD Photon. You will use this program to obtain calibration values that you can copy into the WLD Firmware in lieu of the defaults that we supply. You then recompile the WLD Firmware and flash it to your Photon so that your WLD is again operational but with calibrated servo meter values.

The program used to calibrate the servo meter is called ServoCal.ino. You can find this program

at:

https://github.com/TeamPracticalProjects/WaterLeakSensor/blob/master/Firmware/ServoCal/src/ServoCal.ino (https://github.com/TeamPracticalProjects/WaterLeakSensor/blob/master/Firmware/ServoCal/src/ServoCal.ino)

You need to compile this program for your WLD Photon and flash it to the Photon using either the Particle Workbench IDE (local) or the Particle Web IDE, whichever you prefer. You will already be familiar with this procedure by virtue of building and testing your WLD. After flashing ServoCal.ino to your Photon, make sure that the flashing was completed and that the Photon is breathing cyan, indicating that the firmware has been loaded, the Photon is talking to the Particle cloud and that it is ready for you to communicate with.

After compiling and flashing ServoCal.ino to your Photon, this program will set the servo near the center of the scale. Place a servo horn on the servo in the best possible position for indication of the center of the meter scale.

Next, open a web browser and go to the Particle.io web site (www.particle.io). Select “console” from the options at the top of this web page. You will be presented with a login screen. Use this screen to log in to your Particle.io account. After successful login, you will be presented with the Particle Console screen.

On the left hand side of the Console screen, you will see the Particle logo and some symbols below it. The first symbol below it looks like a little cube and mousing over this symbol will display “My Devices”. Click on this symbol and you will be on the “Devices” screen of the Particle Console.

Find your WLD Photon in the device list and click on it. This will open the “View Device” screen. On the right side of this screen, you will see a box called “Functions”. Inside this box will be “Servo”. Under “Servo” will be a text box labeled “Argument” and a button labeled “Call” to the right of the text box. If you don’t see the “Servo” function on the Console screen, make sure that you have selected the correct device and that you have flashed the correct firmware to this Photon device and that the Photon is “breathing cyan”.

At this point, you will be able to type numerical values into the textbox labeled “Argument” and click the “Call” button. This will send the value to the Photon which will use this value to move the servo per the value that you typed in. If the function executed successfully, the label “Servo” will change to “Servo = number” where number is the value that you typed into the Argument text box. NOTE: make sure that you type only numbers into the Argument text box. If you type some non-numeric character string into this box, you will see “Servo = some strange value”.

To calibrate your servo meter, first enter “170” into “Argument” and click “Call”. The servo should move to the left side of the meter scale, near 40 deg F / 0 %RH. You can play with this number in small increments until you determine the exact servo value that indicates 40 deg F / 0 %RH. Record this value as “MAX_POS”. Then enter “20” into “Argument” and click “Call”. Once again note the position of the servo. It should be near 120 deg F / 100 %RH. You can play with this number in small increments until you determine the exact servo value that indicates 120 deg F / 100 %RH. Record this value as “MIN_POS”.

You can test your MAX_POS and MIN_POS calibration values using a hand calculation of various intermediate values, as demonstrated in the examples in the “Theory of Servo Calibration”, below.

Keep your MAX_POS and MIN_POS calibration values handy. You will need to modify the default values in the WLD firmware to correspond to your servo calibration values when you compile and flash the operational firmware to your Water Leak Detector Photon.

Log out from the Particle Console. Follow the instructions in the WLD Firmware Installation document at:

https://github.com/TeamPracticalProjects/WaterLeakSensor/blob/master/Documentation/WLD_Installation_and_User_Manual_V2.pdf. (https://github.com/TeamPracticalProjects/WaterLeakSensor/blob/master/Documentation/WLD_Installation_and_User_Manual.pdf)

Before compiling this firmware, change the values of MAX_POS and MIN_POS (somewhere around line 70 of the WLD Firmware) to those that you obtained by running this calibration procedure. Then compile and flash this code to your WLD Photon. The WLD servo meter should then operate with your calibrated values.

3. Theory of Servo Calibration.
This section provides the theory behind the servo calibration procedure and some example calculations of servo position command for various temperature and humidity values.
3.1. Servo end points calibration.
When the servo is mounted onto the meter scale, a servo position of zero is fully clockwise, beyond the 100% RH and 120 deg F markings. Conversely, the servo position of 180 degrees is fully counterclockwise, beyond 0% RH and 40 deg F.

The value given to the servo that corresponds to 100% RH / 120 deg F must be determined by trial and error. Let us call this value MAX_POS. Likewise, the value given to the servo that corresponds to 0% RH / 40 deg F must be determined by trial and error. Let us call this value MIN_POS. MAX_POS and MIN_POS are the servo calibration values for any given servo device.

3.2. Servo position calculation for temperature.
Once the end point calibration values are determined, the servo position increment for each degree value of temperature can be determined. The full scale temperature range is 120 – 40 = 80 degrees F. The full scale of servo position values is MAX_POS – MIN_POS. Therefore, each degree of temperature requires an increment of servo position of:

Servo position increment per degree = (MAX_POS – MIN_POS) / 80

The minimum temperature on the scale is 40 deg F. Therefore, the indicated temperature is:

Indicated temperature = actual temperature – 40

The servo movement value is:

Servo mve = Indicated temperature * Servo position increment per degree =

(actual temperature – 40) * (MAX_POS – MIN_POS) / 80

Since the servo is mounted “upside down” so that MAX_POS represents the minimum counterclockwise position for the meter, the servo command must be the MAX_POS – (servo mve):

Servo cmd = MAX_POS – (servo mve)

For example: suppose that MAX_POS = 170 and MIN_POS = 20. Then:

Servo mve = (temp – 40) * (170 – 20)/80 = (temp – 40) * (150/80) =

(temp – 40) * 1.875.

Therefore:

Servo cmd = 170 – (int)((temp – 40)*1.875)

Examples:

For Temp = 40 deg F, Servo cmd = 170 – 0 = 170
For Temp = 60 deg F, Servo cmd = 170 – (20*1.875) = 132 For Temp = 85 deg F, Servo cmd = 170 – (45*1.875) = 86 For Temp = 95 deg F, Servo cmd = 170 – (55*1.875) = 67 For Temp = 115 deg F, Servo cmd = 170 – (75*1.875) = 29 For Temp = 120 deg F, Servo cmd = 170 – (80*1.875) = 20

3.3. Servo position calculation for humidity.
Similarly, the servo position command to indicate relative humidity (RH) can be determined as follows. The full scale RH range is 100 – 0 = 100. Therefore,

Servo position increment per RH = (MAX_POS – MIN_POS) / 100

The minimum RH on the scale is 0. Therefore, the indicated RH is:

Indicated RH = actual RH – 0 = actual RH

The servo movement value is:

Servo mve = Indicated RH * Servo position increment per RH =

(actual RH) * (MAX_POS – MIN_POS) / 100

Since the servo is mounted “upside down” so that MAX_POS represents the minimum counterclockwise position for the meter, the servo command must be the MAX_POS – (servo mve):

Servo cmd = MAX_POS – (servo mve)

For example: suppose that MAX_POS = 170 and MIN_POS = 20. Then:

Servo mve = (RH) * (170 – 20)/100 = (RH) * (150/100) =

RH * 1.5

Therefore:

Servo cmd = 170 – (int)(RH * 1.5)

Examples:

For RH = 0%, Servo cmd = 170 – 0 = 170
For RH = 15%, Servo cmd = 170 – (15 * 1.5) = 147 For RH = 25%, Servo cmd = 170 – (25 * 1.5) = 132 For RH = 50%, Servo cmd = 170 – (50 * 1.5) = 95
For RH = 75% deg F, Servo cmd = 170 – (75*1.5) = 57 For RH = 90% deg F, Servo cmd = 170 – (90*1.5) = 35 For RH = 100% deg F, Servo cmd = 170 – (100*1.5) = 20

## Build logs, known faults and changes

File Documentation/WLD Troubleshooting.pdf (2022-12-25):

# WLD Troubleshooting

If you’ve made your Water Leak Detector and it isn’t working as expected, here are some tips.

By: Jim Schrempp and Bob Glicksman; updated 12/23/2022


This document is © Copyright 2022, 2017 Team Practical Projects, Bob Glicksman and Jim Schrempp. All rights reserved.

Table of Contents.

Table of Contents. | 1
1. How do I know if my Water Leak Detector is armed and running? | 2

### 2. My WLD is powered up but the red LED on my water level sensors is not on. What’s

wrong? | 2
3. What do I do if my Water Leak Detector is not up and running properly? | 3
4. How do I test my Water Leak Detector to know if it is running properly? | 3

### 5. My Water Leak Detector is not working properly and I have tried all of your

suggestions to get it working. How can I get support to help me isolate and fix
problems? | 4

© 2022, 2017, Team Practical Projects, Jim Schrempp and Bob Glicksman; all rights reserved. Subject to “Terms of Use, License and Disclosure”

# 1. How do I know if my Water Leak Detector is armed and running?

The green light should be on solid and the small LED on the Photon should be “breathing cyan”. Also, the D7 LED on the Photon should go on and off at about 4 second intervals. The little red LED on each water level sensor should be on.

# 2. My WLD is powered up but the red LED on my water level sensors is not on. What’s wrong?

First, check the connections from the water leak sensor to the RJ11 connector board, then from the corresponding RJ11 connector board in the WLD enclosure to the WLD main printed circuit board. Make sure that you are using 4-wire (2 line) telephone cables between the sensor boards and the electronics enclosure. 2-wire (1 line) telephone cables will not work.

If these are correct, you may be using “instrument” (“straight”) cables instead of telephone (“reverse”) cables. In order to check this out, remove the cable from the RJ11 connectors and stretch it out flat. Note the locking tabs on the connectors at both ends of the cable. If they are both up or both down, you have the telephone style cable. If one tab is up and the other tab is down, you have an instrument style cable.

If you have an instrument style cable, no problem. You can use this cable, but you need to reverse the connections of the sensor to the RJ11 connector board:

Instrument (“straight”) cable:
S → pin 2
+ → pin 3
- → pin 4

By way of comparison, the sensor to RJ11 connector board wiring for a telephone (“reverse”) cable is:
S → pin 5
+ → pin 4
- → pin 3

# 3. What do I do if my Water Leak Detector is not up and running properly?

First, remove and restore power. That usually gets it running again. After re-applying power, note the multicolor LED on the Photon module. It should start blinking green after a few seconds, then transition to a fast green blinking after several seconds, and end up “breathing cyan”. If the Photon is breathing cyan, the green LED on the backlit pushbutton switch on the WLD front panel should light solid and the blue “D7” LED on the photon should turn on and off approximately every 4 seconds. If all of this is happening, the WLD is up and running correctly.

If you get no lights anywhere within about 3 seconds of applying power, you have a problem with the power connection or a short circuit on the power. Check that the power is not shorted to ground on the WLD printed circuit board and that the “wall wart” power supply and the USB cable are good. The WLD printed circuit board has an “expansion” connector where you can check the +5 and +3.3 volt power supplies against ground with a voltmeter to insure that the electronics are powered correctly.

If you have power and lights but the Photon multicolor LED does not follow the sequence above and does not get to “breathing cyan”, then you have some problems either with your Photon module or with connecting to the Internet over WiFi. Consult the Particle on-line documentation (https://docs.particle.io/guide/getting-started/modes/photon/) to troubleshoot.

If your Photon is breathing cyan but the green LED on the pushbutton does not light up and the “D7” LED on the Photon does not turn on and off at 4 second intervals, then the Photon has not completed its setup operations correctly. Usually, this is because it cannot communicate with the DHT11 temperature/humidity module. Check the connection of the DHT11 to the main printed circuit board - check that the DHT11 is oriented properly and that the connections to the board are good.

# 4. How do I test my Water Leak Detector to know if it is running properly?

If the green LED on the pushbutton is lit solidly and if the red LEDs on each water level sensor are lit, then your WLD is armed and ready. The front panel “servo meter” should read out the temperature or humidity, depending upon the position of the toggle switch. The App on your smartphone should show temperature and humidity readings and no alarm. You can also use the Particle Console to test that you can read data from your WLD hardware, set low and high temperature alarm limits into your WLD hardware, send a test alarm and observe alarm publications to the Particle cloud. See: “WLD_Installation_and_User_Manual”, section 7, in the Documentation folder in this repository for more information.

There are two ways to test that water leak sensors are working. You can use whichever of these methods that is convenient:

(1) Unplug one of the water level sensor cables from its connector at the enclosure. An alarm condition should result. Plug the cable back in and the alarm condition should clear. Repeat this test with the other cable.
(2) Drop a small amount of water on one of the water level sensors. The alarm should go off and the alarm condition should persist until the sensor is dried off. Repeat this test with the other sensor.

# 5. My Water Leak Detector is not working properly and I have tried all of your suggestions to get it working. How can I get support to help me isolate and fix problems?

This is a do-it-yourself project and we are not a commercial entity. Therefore, we cannot make a blanket offer of support. However, if you e-mail us at: TeamPProjects@gmail.com we will try and help you out. Please be advised, however, that any help that we offer will be on an “as-available” and “best effort” basis. We cannot offer you any guarantees or warranties of any sort.

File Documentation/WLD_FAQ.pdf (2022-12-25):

# Water Leak Detector Frequently Asked Questions

By: Jim Schrempp and Bob Glicksman; updated 12/23/22


This document is © Copyright 2022, 2017 Team Practical Projects, Bob Glicksman and Jim Schrempp. All rights reserved.

© 2022, 2017 Team Practical Projects, Jim Schrempp and Bob Glicksman. All Rights Reserved

Table of Contents.

Table of Contents. | 2
1. General Questions. | 4
1.1. What is the Water Leak Detector? | 4
1.2. How do I obtain a Water Leak Detector? | 4
1.3. Who is Team Practical Projects? | 4
1.4. I like the Water Leak Detector project. Has Team Practical Projects published other
projects that I might be interested in? | 5
1.5. I have ideas/suggestions for improving the Water Leak Detector. How do I
communicate these with Team Practical Projects? | 5
1.6. I have ideas/suggestions for projects that Team Practical Projects might be interested
in. How do I communicate these to you? | 5
2. Licensing Questions. | 5
2.1. Do I need to obtain a license/permission to build a Water Leak Detector for myself? | 5
2.2. Do I need to obtain a license/permission to build a Water Leak Detector for someone
else? | 6
2.3. Do I need to obtain a license/permission to manufacture Water Leak Detectors for sale? 6
2.4. Do I need to obtain a license/permission to sell kits for people to build Water Leak
Detectors? | 6
2.5. How do I obtain a commercial license to sell assembled Water Leak Detectors or Water
leak Detector kits? | 6
2.6. I made some changes/modifications to the Water Leak Detector (hardware, firmware, app or documentation). Do I need to inform someone about these changes, and how do I
do this? | 7
3. Building/Installing Questions. | 7
3.1. What tools do I need in order to build a Water Leak Detector from your documentation? 7
3.2. What skills do I need in order to build a Water Leak Detector from your documentation? 8
3.3. Where do I install the Water Leak Detector electronics? | 8
3.4. Where do I install the Water Level Sensors? | 8
4. Operating Questions (local). | 9
4.1. What does a steady green light on the pushbutton switch mean? | 9
4.2. What does a flashing green light on the pushbutton switch mean? | 9
4.3. What if there is no light on the pushbutton switch? | 9

4.4. How do I mute the audible alarm? | 10
4.5. How do I re-arm the Water Leak Detector after muting an audible alarm? | 10
4.6. How do I read temperature or humidity off of the face of the Water Leak Detector? | 10
4.7. How do I switch the “servo meter” on the Water Leak Detector from temperature to
humidity or visa versa? | 10
4.8. How do I read temperature in Fahrenheit (Centigrade)? | 10
4.9. My servo meter is not displaying the correct temperature or humidity. What do I do to
correct this? | 10
4.10. Will my Water Leak Detector provide me with local only operation in the event that my
Internet connection is down? | 11
5. Operating Questions (Remote - app). | 11
5.1. Where do leak detection notifications show up on my smartphone? | 11
5.2. How can I tell if the Water Leak Detector is currently detecting a leak alarm or not? | 12
5.3. What messages are displayed on the “Current WLD Status” line of the App and what do
these messages mean? | 12
5.4. How do I convert the time displayed on the “Current WLD Status” line of the App into
the local time where I am (local time where the Water leak Detector is)? | 12

1. General Questions.

## 1.1. What is the Water Leak Detector?

The Water Leak Detector (WLD) is an electronic device designed to alert you in the event that you have a water leak in the vicinity of one of the WLD’s water level sensors. The WLD supports two such sensors. In addition, the WLD measures and displays ambient temperature and humidity, and can generate alarms if the temperature is too low or too high.

The WLD is connected to the Internet via WiFi and the project can provide you with SMS text messages about new temperature and water leak alarm conditions. A smartphone App allows you to view the current temperature, humidity, and alarms status, and set new temperature alarm limits, anywhere over the Internet.

The WLD also has audible and visual alarm indicators and a local “servo meter” indication of temperature and humidity. The local alarm and indicator functions will alert you to leak conditions when you are at home, even if you are not near your mobile phone.

Further information about the Water leak detector can be found in the document “Water_Leak_Detector_Concept_V2” that is in the Documentation folder of this repository.

## 1.2. How do I obtain a Water Leak Detector?

The Water Leak Detector is a project that you build yourself, using parts that you purchase yourself from the included parts list and that you assemble using the included documentation.

## 1.3. Who is Team Practical Projects?

Team Practical Projects is a collaboration between Jim Schrempp and Bob Glicksman. Jim and Bob are both retired after long careers in technology development. We enjoy developing useful and practical devices for ourselves and for others and we are happy to share what we develop with people who might find our projects interesting and/or useful.

## 1.4. I like the Water Leak Detector project. Has Team Practical Projects published other projects that I might be interested in?

Yes. We post all of our projects on Github, at https://github.com/teampracticalprojects.

## 1.5. I have ideas/suggestions for improving the Water Leak Detector. How do I communicate these with Team Practical Projects?

Send us an email at TeamPProjects@gmail.com or open an issue in GitHub.

## 1.6. I have ideas/suggestions for projects that Team Practical Projects might be interested in. How do I communicate these to you?

Send us an email at TeamPProjects@gmail.com or open an issue in GitHub.

2. Licensing Questions.

## 2.1. Do I need to obtain a license/permission to build a Water Leak Detector for myself?

We offer the Water Leak Detector, and all of our projects, free of royalties to everyone, under a Creative Commons license Attribution-Non-Commercial 4.0. You can view the details of this license at: http://creativecommons.org/licenses/by-nc/4.0/ or send a letter to Creative Commons, 444 Castro Street, Suite 900, Mountain View, California, 94041, USA. In short, you may build Water Leak Detectors under this license, royalty free, for your own use. You may also expand or extend or otherwise incorporate part or all of our technology in your own projects, as long as you publish such projects under the same open source, non-commercial license and acknowledge the use of our technology.

## 2.2. Do I need to obtain a license/permission to build a Water Leak Detector for someone else?

You may build as many Water Leak Detectors as you wish, royalty free, under the terms of the Creative Commons license Attribution-Non-Commercial 4.0. Under this license, you may charge others up to the cost of the parts, materials, and labor that you use to build the Water Leak Detectors. You may not, however, charge others for the use of our technology nor can you sell Water Leak Detectors in any way commercially (either as assembled and tested units or as kits).

## 2.3. Do I need to obtain a license/permission to manufacture Water Leak Detectors for sale?

Yes. We are willing to discuss commercial licensing with people/companies who are genuinely interested in making Water Leak Detectors for sale (as kits or as finished products) or in using our WLD technology inside of your own product(s). Please e-mail us with your interest: TeamPProjects@gmail.com.

## 2.4. Do I need to obtain a license/permission to sell kits for people to build Water Leak Detectors?

Yes. We are willing to discuss commercial licensing with people/companies who are genuinely interested in making Water Leak Detectors for sale (as kits or as finished products) or in using our WLD technology inside of your own product(s). Please e-mail us with your interest: TeamPProjects@gmail.com.

## 2.5. How do I obtain a commercial license to sell assembled Water Leak Detectors or Water leak Detector kits?

We are willing to discuss commercial licensing with people/companies who are genuinely interested in making Water Leak Detectors for sale (as kits or as finished products) or in using our WLD technology inside of your own product(s). Please e-mail us with your interest: TeamPProjects@gmail.com.

## 2.6. I made some changes/modifications to the Water Leak

Detector (hardware, firmware, app or documentation).

## Do I need to inform someone about these changes, and how do I do this?

We love collaborators! The best way to do this is to engage with us on GitHub or email (TeamPProjects@gmail.com). Let’s talk about the changes you’re making. If your changes are in-line with our objectives for the project, we’d like to add them. The best way to do this is to fork our repository on GitHub, do your work, and submit a pull request to our development branch. If you’re not a GitHub user, email us and we can work something out.

3. Building/Installing Questions.

## 3.1. What tools do I need in order to build a Water Leak Detector from your documentation?

You will need basic hand tools and through hole soldering tools. Here is a suggested list:
- Small, straight screwdriver.
- Needle nose pliers.
- Diagonal cutter.
- Wire stripper (#16 awg - #26 awg stripping dies).
- Fine tip soldering iron.
- Electrical solder.
- Electrical tape or painters tape (for holding things in place while soldering).
- Sturdy double sided tape for mounting things.
- Solder wick or solder pullit (for when you make a mistake).
- “3rd hand” support stand to hold a printed circuit board while soldering.
- Magnifying glass (for inspecting your work).
- Electrical multimeter (with VDC and ohms settings).
- Electric drill and ¼” general purpose drill bit set.
- Shop knife (if cutting a plastic box for your enclosure).
- Plastic glue (hot glue gun is recommended).

## 3.2. What skills do I need in order to build a Water Leak Detector from your documentation?

You will need basic through hole soldering skills to assemble the WLD printed circuit board and the RJ11 boards. Minimum pin spacing is 0.1”; we do not use small outline devices or surface mount devices because of the extra skills and tools needed.

You will need to drill and cut a plastic box to use as an enclosure, unless you select some other enclosure option (such as 3D printed parts).

You will need to glue plastic parts together; a hot glue gun is recommended.

You don’t need to be a super programmer (or even a beginner programmer), but you have to be willing to follow our instructions on how to install the firmware, webhooks, scripts, and the smartphone app.

## 3.3. Where do I install the Water Leak Detector electronics?

You will want to install the WLD electronic enclosure somewhere where you can see the faceplate, access AC power, and at a location where you can run the cables to the sensor(s). We have tested sensor cable lengths up to 10 feet, but longer cables should work (in theory).

## 3.4. Where do I install the Water Level Sensors?

The water level sensors should be placed along a wall so that the bottom tip of the sensor contacts the ground. The location should be at a low point in the floor where leaked water is likely to pool first. If such a location is not available, you might want to consider placing a rectangular pan directly below the likely leak location and mount a sensor vertically along one side of the pan.

4. Operating Questions (local).

## 4.1. What does a steady green light on the pushbutton switch mean?

A steady green light means that the Water Leak Detector is powered, armed and ready to detect leaks, but that no leak is currently being detected. It also means that it is measuring temperature and pressure and that it is connected to the Particle cloud via the Internet. Under rare circumstances, the Photon might crash but leave the LED on solid.

## 4.2. What does a flashing green light on the pushbutton switch mean?

A flashing green light means that a water leak has been detected or that a sensor has become disconnected. The light will continue to flash as long as either of the sensors is wet. After the leak is cleaned up and both sensors are dried off (with a dry cloth), the light will go back to solid green (armed and ready).

## 4.3. What if there is no light on the pushbutton switch?

If the pushbutton switch does not display a solid or flashing green light, it means that the Water Leak Detector is not armed and ready. There are many reasons for this, including but not limited to:
- No power to the WLD electronics.
- The WLD electronics (Photon) is not connected to the Particle cloud via the Internet.
- The WLD electronics (Photon) has not exited setup, perhaps because of a problem with the electronics (such as with communicating with the DHT11 temperature/pressure sensor).
- A wire has come loose between the WLD printed circuit board and the LED terminals on the pushbutton switch.
- A bad LED inside the pushbutton switch.

You can find further information about troubleshooting your WLD in the “WLD troubleshooting” document in the Documentation folder of this repository.

## 4.4. How do I mute the audible alarm?

Pressing the pushbutton switch will mute the audible alarm. The green LED will continue to flash until the sensors are dry and the device rearms.

## 4.5. How do I re-arm the Water Leak Detector after muting an audible alarm?

The WLD will automatically re-arm after the water leak has been cleaned up and the sensors have been dried off. This will be indicated by the backlight LED returning to a constant on state.

## 4.6. How do I read temperature or humidity off of the face of the Water Leak Detector?

Once you have calibrated the servo as described in our documentation, the pointer on the servo will indicate the temperature or humidity. You change from one to the other by throwing the toggle switch on the faceplate.

## 4.7. How do I switch the “servo meter” on the Water Leak Detector from temperature to humidity or visa versa?

Change position of the toggle switch.

## 4.8. How do I read temperature in Fahrenheit (Centigrade)?

Both scales are available on the front panel “servo meter”. You can read whichever scale that you choose. The App that we supply with this project displays temperature in Fahrenheit. You can change the WLD firmware to report in Centigrade yourself if you wish.

## 4.9. My servo meter is not displaying the correct temperature or humidity. What do I do to correct this?

First, repeat the calibration step from the documentation. Second, consider the environment of the WLD. If the detector is installed in a cabinet with a water heater, then the temperature and humidity may be different from the ambient environment outside the cabinet. Check the temperature and humidity that is reported on the App or via the Particle Console. If the servo meter readings are the same as those reported to the cloud, then these are the values that the DHT11 temperature/humidity sensor is reporting. Replace the DHT11 sensor if it is not reading correctly. If the reading on the app are correct but the servo indicator is off, try re-aligning the pointer horn on the servo to the correct value. Re-run the servo calibration routine if this is necessary:
https://github.com/TeamPracticalProjects/WaterLeakSensor/blob/master/Documentation/Servo_Meter_Calibration.pdf (https://github.com/TeamPracticalProjects/WaterLeakSensor/blob/master/Documentation/Servo_Meter_Calibration.pdf)

## 4.10. Will my Water Leak Detector provide me with local only operation in the event that my Internet connection is down?

No. When the internet is down the Photon is unable to connect to the Particle Cloud. This can prevent the Photon from executing the WLD firmware.

5. Operating Questions (Remote - app).

## 5.1. Where do leak detection notifications show up on my smartphone?

Leak detection alarms show up in two places: (1) when any alarm is generated, an SMS text is sent to the user’s mobile phone. The mobile phone need not be a smartphone; any mobile phone that supports SMS texts will suffice. (2) the current status of all three alarms are displayed on the smartphone App that is part of this project. See section 5.2 of the “WLD_Installation_and_User_Manual_V2” in the Documentation folder of this repository for details. Active alarms are backgrounded in red; no alarms are backgrounded in green. Note the distinction between alarm texts and the Alarm status shown on the App. The alarm texts occur when the alarm condition is first detected, and are timestamped as such. The App shows the state of the alarms when the App is opened or the REFRESH DATA button is tapped. This may occur some time after the alarm was detected and the alarm status may have changed in the interim (e.g. someone repaired and cleaned up the water leak prior to the App being used).

## 5.2. How can I tell if the Water Leak Detector is currently detecting a leak alarm or not?

Open the App on your smartphone. If any of the three alarms are backgrounded in red, then that alarm is still active. If the alarm is backgrounded in green, then the alarm condition is no longer present.

## 5.3. What messages are displayed on the “Current WLD Status” line of the App and what do these messages mean?

This message contains two items relating to the current (as of opening the App or tapping REFRESH DATA) status of the WLD hardware: (1) the version of the firmware that is installed on the Photon device, and (2) the date and time of the last reset of the Photon (in UTC - not converted to local time). This information may be helpful in troubleshooting.

## 5.4. How do I convert the time displayed on the “Current WLD Status” line of the App into the local time where I am (local time where the Water leak Detector is)?

The time in these messages is UTC (Coordinated Universal Time). You can convert this time to your local time via one of the many on-line time zone converters that you can find on the Internet.

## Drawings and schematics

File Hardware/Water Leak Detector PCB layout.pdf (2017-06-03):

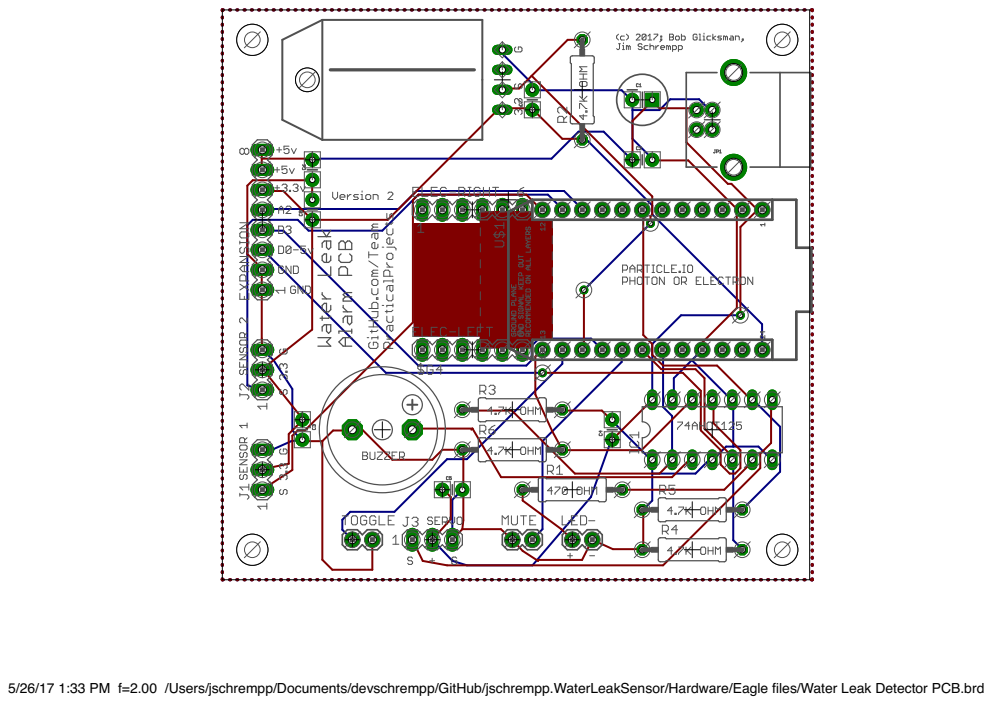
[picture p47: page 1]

5/26/17 1:33 PM f=2.00 /Users/jschrempp/Documents/devschrempp/GitHub/jschrempp.WaterLeakSensor/Hardware/Eagle files/Water Leak Detector PCB.brd

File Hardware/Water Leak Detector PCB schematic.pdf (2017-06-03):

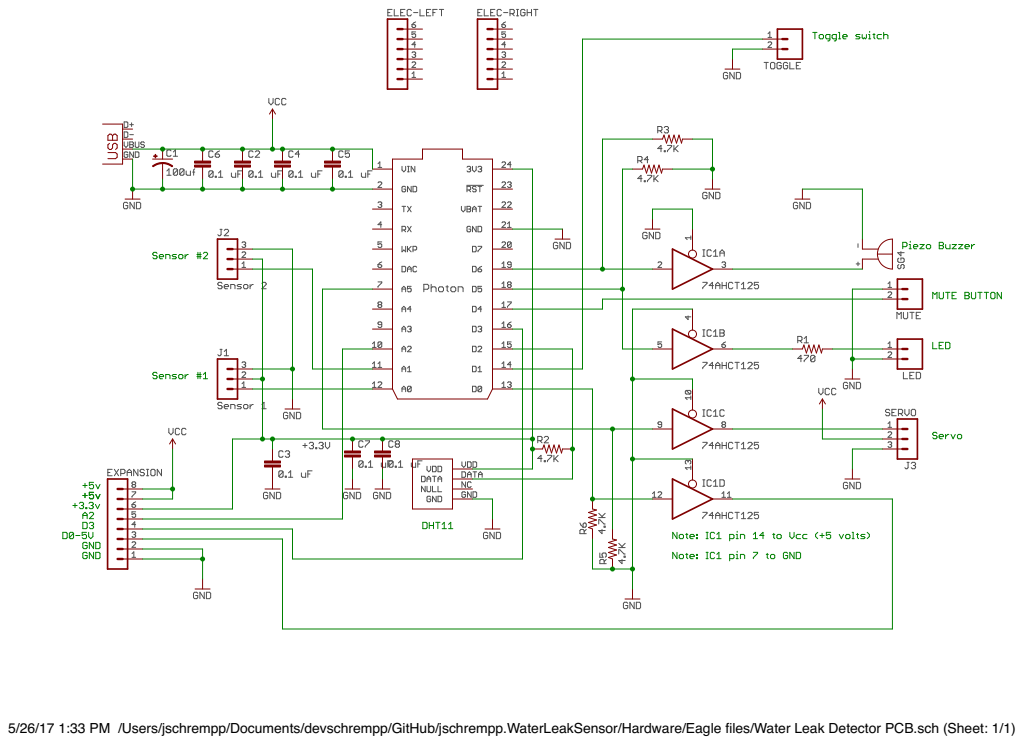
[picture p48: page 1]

5/26/17 1:33 PM /Users/jschrempp/Documents/devschrempp/GitHub/jschrempp.WaterLeakSensor/Hardware/Eagle files/Water Leak Detector PCB.sch (Sheet: 1/1)

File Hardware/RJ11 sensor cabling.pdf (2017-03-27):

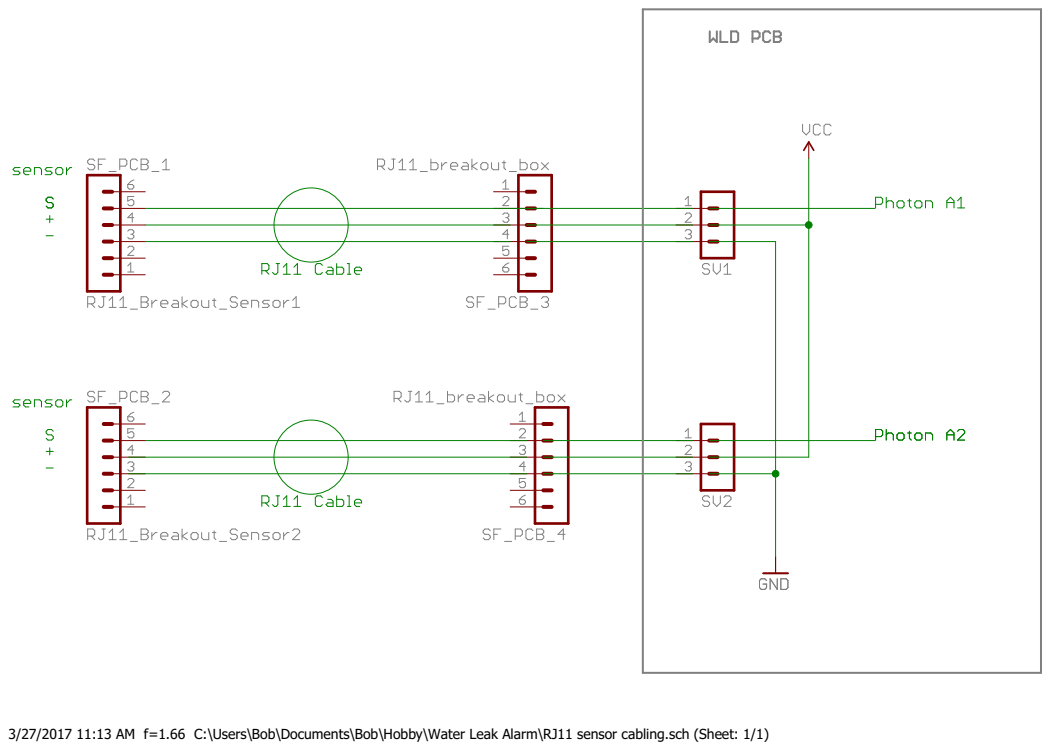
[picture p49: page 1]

3/27/2017 11:13 AM f=1.66 C:\Users\Bob\Documents\Bob\Hobby\Water Leak Alarm\RJ11 sensor cabling.sch (Sheet: 1/1)

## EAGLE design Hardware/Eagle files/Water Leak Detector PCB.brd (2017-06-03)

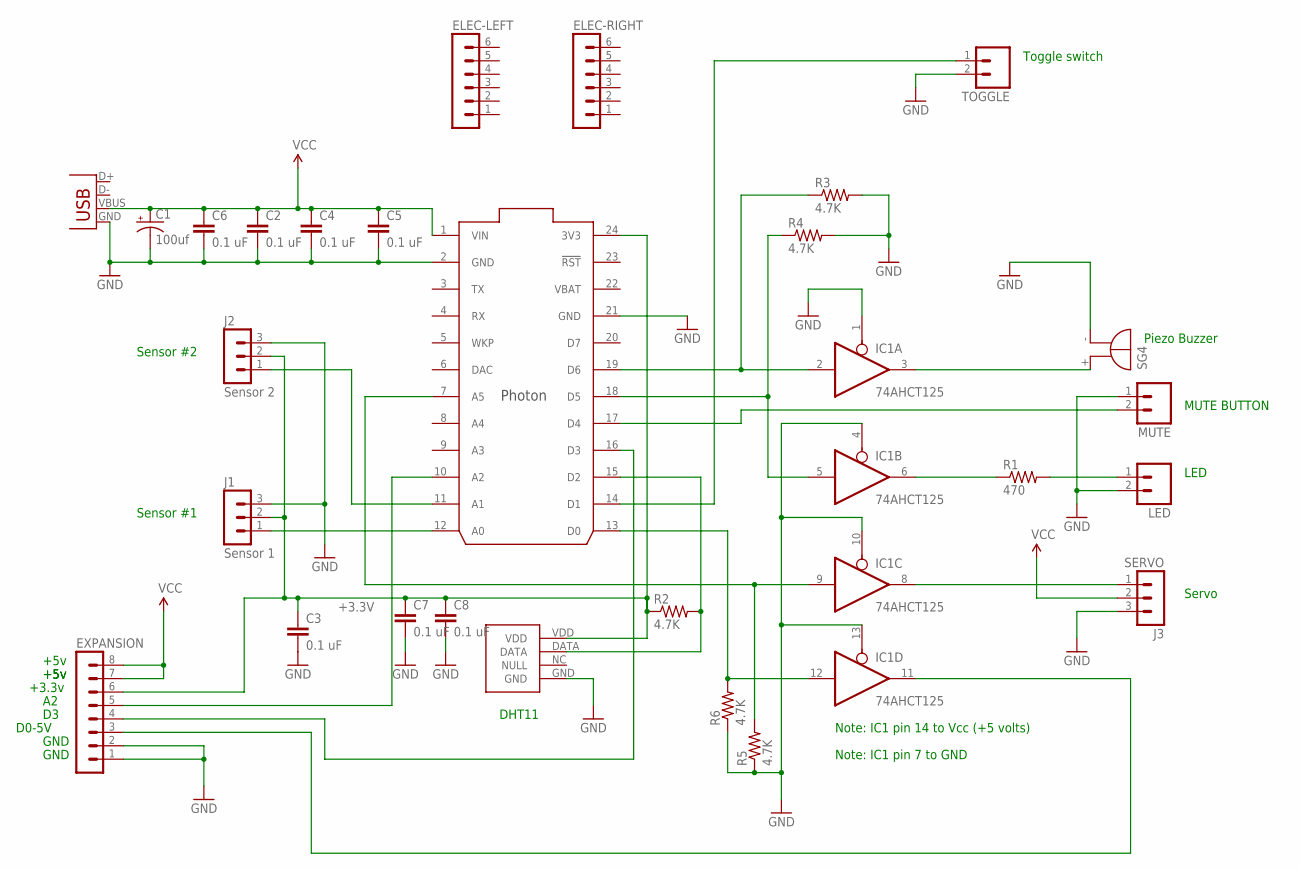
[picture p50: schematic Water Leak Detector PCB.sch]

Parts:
C1: 100uf; CPOL-RADIAL-100UF-25V
C2, C3, C4, C5, C6, C7, C8: 0.1 uF; CAP-PTH-SMALL
ELEC-LEFT: MA06-1
ELEC-RIGHT: MA06-1
EXPANSION: MA08-1
IC1: 74AHCT125; DIL14
J1: Sensor 1; MA03-1
J2: Sensor 2; MA03-1
J3: SERVO; MA03-1
JP1: USB-B; USB-B-PTH
LED: M02PTH; 1X02
MUTE: M02PTH; 1X02
R1: 470; 0309/12
R2, R3, R4, R5, R6: 4.7K; 0309/12
SG4: F/HMB
TOGGLE: M02PTH; 1X02
U$1: PHOTON_WITH_HEADERS; PHOTON
U$2: DHT22

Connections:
+3.3V: C3.1, C7.1, C8.1, EXPANSION.6, J1.2, J2.2, R2.1, U$1.24 (3V3), U$2.VDD
GND: C1.2 (-), C2.2, C3.2, C4.2, C5.2, C6.2, C7.2, C8.2, EXPANSION.1, EXPANSION.2, IC1.1 (OE), IC1.4 (OE), IC1.7 (GND), IC1.10 (OE), IC1.13 (OE), J1.3, J2.3, J3.3, JP1.GND, LED.2, MUTE.1, R3.2, R4.2, R5.1, R6.1, SG4.-, TOGGLE.2, U$1.2 (GND), U$1.21 (GND), U$2.GND
unnamed: IC1.8 (O), J3.1
unnamed: J2.1, U$1.11 (A1)
unnamed: J1.1, U$1.12 (A0)
unnamed: IC1.2 (I), R3.1, U$1.19 (D6)
unnamed: IC1.3 (O), SG4.+
unnamed: IC1.9 (I), R5.2, U$1.7 (A5)
unnamed: IC1.6 (O), R1.1
unnamed: LED.1, R1.2
unnamed: MUTE.2, U$1.17 (D4)
unnamed: EXPANSION.4, U$1.16 (D3)
unnamed: EXPANSION.3, IC1.11 (O)
unnamed: EXPANSION.5, U$1.10 (A2)
unnamed: IC1.12 (I), R6.2, U$1.13 (D0)
unnamed: R2.2, U$1.15 (D2), U$2.DATA
unnamed: TOGGLE.1, U$1.14 (D1)
unnamed: IC1.5 (I), R4.1, U$1.18 (D5)
VBAT: U$1.22 (VBAT)
VCC: C1.1 (+), C2.1, C4.1, C5.1, C6.1, EXPANSION.7, EXPANSION.8, IC1.14 (VCC), J3.2, JP1.VBUS, U$1.1 (VIN)

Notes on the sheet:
Sensor #1
Sensor #2
DHT11
Servo
Note: IC1 pin 14 to Vcc (+5 volts)
Piezo Buzzer
Note: IC1 pin 7 to GND
Toggle switch
MUTE BUTTON
LED
+5v
+3.3v
GND
D0-5V

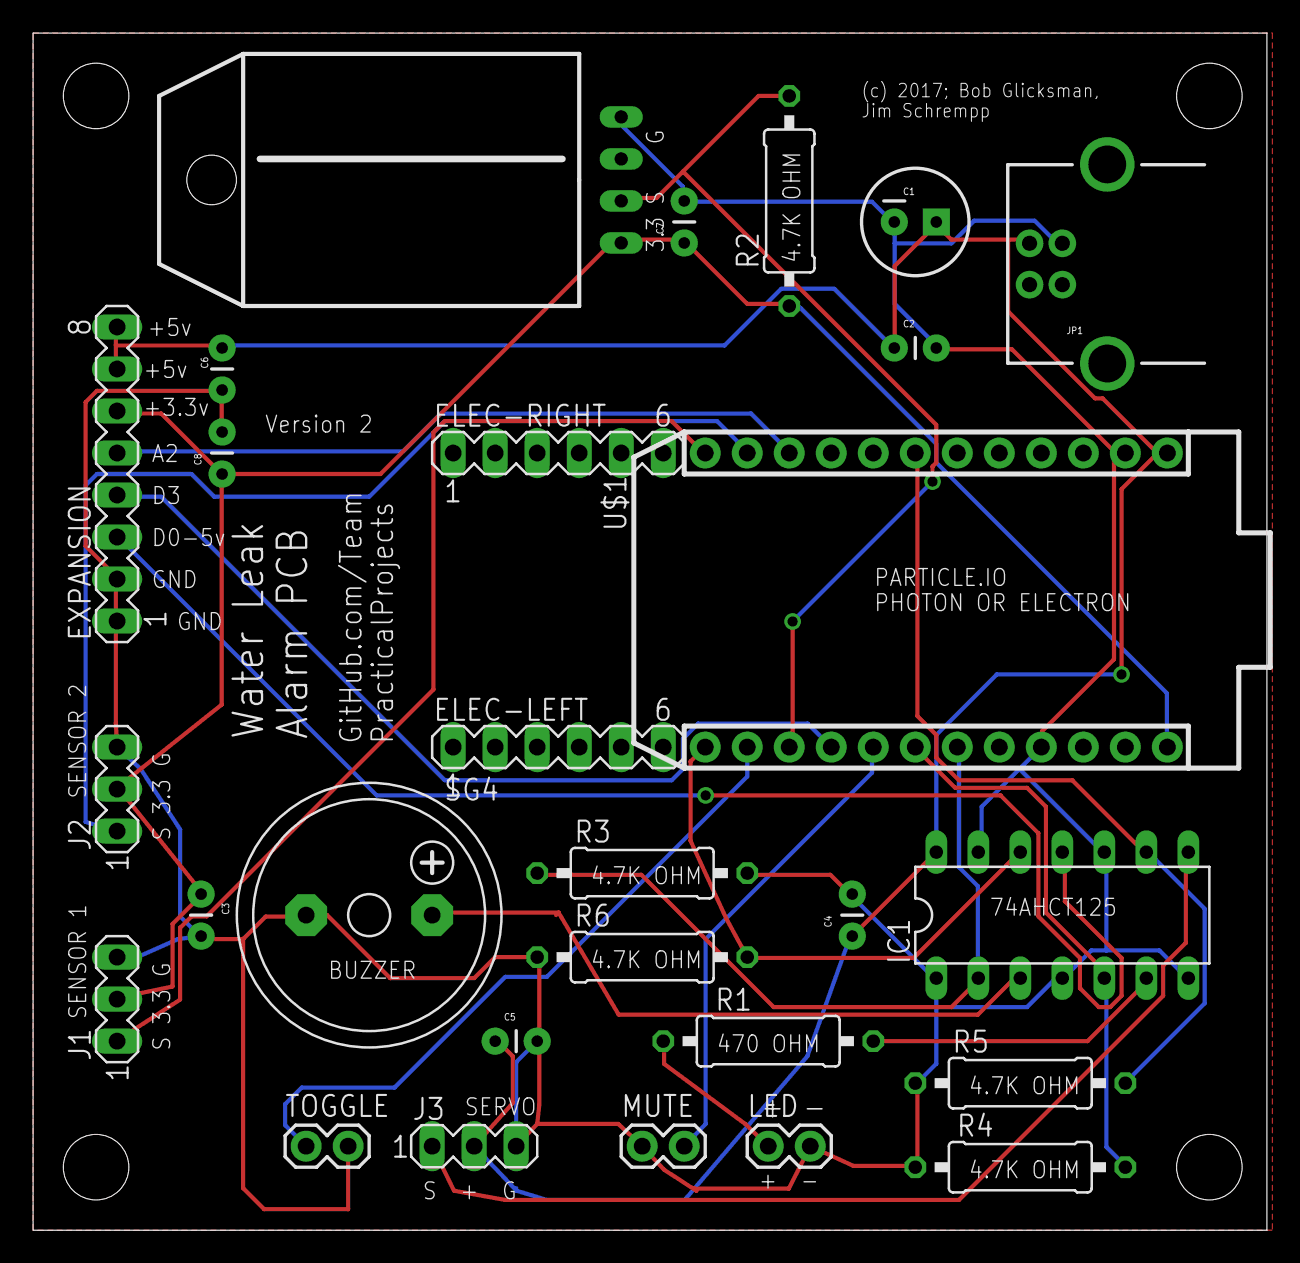
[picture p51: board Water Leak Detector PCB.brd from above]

Board: 2 copper layers, 74.6 x 72.4 mm, 28 parts (0 on the bottom side), 19 nets.

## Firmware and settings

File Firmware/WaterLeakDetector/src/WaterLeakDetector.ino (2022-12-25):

/*********************************************************************************************************
    WaterLeakDetector: Detect a water leak and sound the alarm!  Read the ambient temperature
        and humidity, display them on a "servo meter" and publich the data to the cloud."

        This program reads two water level sensor analog outputs, converts each to a voltage,
        thresholds the voltages to detect a water leak condition, integrates the thresholds to filter
        out false readings, introduces some hysteresis into the alarm/reset process, and indicates the alarm.
        The program uses a non-blocking delay that reads each sensor every 20 milliseconds and requires
        5 readings above a threshold for either sensor in order to trigger an alarm.

        This program supports both an alarm and an indicator.  The indicator turns on and off
        based solely upon the threshold hysteresis.  The alarm also turns on and off based upon the
        threshold hysteresis but, additionally, mutes when a pushbutton is pressed and stays muted until the
        alarm indication is cleared.  Although two sensors are supported, there is only a single alarm
        indication.  Either sensor can trigger the alarm and both sensors must be in the non-alarm
        state for the alarm indication to be cleared.

        The indicator is normally lit to show that the system is working.  The indicator flashes when
        an alarm condition is detected (water level threshold) and remains flashing until the alarm
        condition is cleared.  The alarm is a piezo buzzer that is pulsed whenever there is an alarm
        condition and the mute pushbutton has not been pressed.

        When a new alarm condition is sensed, a message to this effect is published to the cloud.

        This program also reads ambient temperature and humidity from a DHT11 sensor.  This data might
        be useful to determine if a leak in a basement is due to a burst steam pipe.  The temperature
        and humidity are read out every 4 seconds (nominally).  This data is published to the cloud and
        is also indicated on  "servo meter"; the latter using a 10 value moving average.
        A toggle switch determine whether the servo meter displays the temperature or the humidity.

        This version of code also also includes a diff() function for computing time differences using
        millis(), for use in non-blocking delay functionality.

        This version includes all of Jim's Blynk integration code plus coding for a second alarm notification
        30 seconds after the first alarm notification.

        This version also fixes a bug in the previous Blynk integration code for proper handling of
        sending an alarm.


    author: Bob Glicksman, Jim Schrempp; 10/28/2022

    (c) 2017, 2021, 2022 Bob Glicksman and Jim Schrempp, Team Practical Projects

20221028:  Version 2.01:  Added a flag to not send out alarms on the first temp/Rh reading, because
    the DHT11 library gives a false reading the first time through.  This was a legacy bug which did
    not impact anything because there were no alarms.  Now, we got a low temperature alarm when the
    Photon rebooted, so this flag surpresses this bogus alarm.  Also formatted the temperature and 
    humidiy strings for cloud publication (%4.1f).

20221025:  Version 2.0:  Removed IFTTT and Blynk.  This version uses a custom built app (AI2) to read out
    the status of the WLD - temperature, humidity and alarms.  This version adds high and low temperature
    alarms to the previous water leak alarm.  This version uses an instance of the included WLDAlarmProcessor
    class to manage the three alarms.  Alarms are implemented as SMS text messages to the user's mobile
    phone, via Particle.publish() from the WLDAlarmProcessor instance.  Each such publication triggers
    a webhook in the Particle cloud to POST the alarm event to a Google Apps Script.  The script, in turn,
    sends an email to the user's mobile carrier SMS gateway, resulting in an SMS text to the user's mobile
    phone.  More information about this process can be found at:
    https://github.com/TeamPracticalProjects/Connectivity_Tools_with_Particle_Devices
    
    This version of the WLD firmware uses the same logic as earlier versions
    to detect and clear leak conditions and to average the temperature and humidity reading for the purposes
    of display, reporting, and detecting/clearing alarms.  The instance of the WLDAlarmProcessor class manages
    alarm holdoffs so that this firmware does not have to manage alarm states.  Rather, when this firmware
    detects an alarm condition, it calls the appropriate object method and when it determines that an alarm
    condition does not exist, it calls a re-arm method for that alarm.  The object manages alarm holdoffs so that
    any persistant alarm only alarms the user.

    Manual display of temperature/humidity (via the servo meter) and alarm/mute functionality are unchanged from
    earlier version of the WLD.

20210320:  Commented out Particle.publish() of temp and humidity b/c of Particles new pricing policy
20170530a: Added Blynk application notification of water detection with Blynk Terminal and LED.
***********************************************************************************************************/
#include <PietteTech_DHT.h> // non-blocking library for DHT11
#include <WLDAlarmProcessor.h>  // the alarm processor class

// Constants and definitions
#define DHTTYPE  DHT11              // Sensor type DHT11/21/22/AM2301/AM2302
const int WATER_SENSOR_A_PIN = A0;
const int WATER_SENSOR_B_PIN = A1;
const int LED_PIN = D7;
const int ALARM_PIN = D6;
const int INDICATOR_PIN = D5;
const int BUTTON_PIN = D4;
const int DHTPIN = D2;        	    // Digital pin for communications
const int TOGGLE_PIN = D1;               // pin for temperature/humidity toggle switch
const int SERVO_PIN = A5;                // servo pin
#define DHT_SAMPLE_INTERVAL   4000  // Sample every 4 seconds
#define PARTICLE_PUBLISH_INTERVAL 60000 // Publish values every 60 seconds
const float WATER_LEVEL_THRESHOLD = 0.5;    // 0.5 volts or higher on either sensor triggers alarm

// servo calibration values
const int MIN_POS = 5;  // the minimum position value allowed
const int MAX_POS = 175;  // the maximum position value allowed

// meter face range values
const int HI_TEMP = 120;  // based upon meter dial face for temperature (F)
const int LO_TEMP = 40;   // based upon meter dial face for temperature (F)
const int HI_HUM = 100;  // based upon meter dial face for humidity (%RH)
const int LO_HUM = 0;  // based upon meter dial face for humidity (%RH)

// calculate meter dial ranges from hi and lo values
#define TEMP_RANGE (HI_TEMP - LO_TEMP)
#define HUM_RANGE (HI_HUM - LO_HUM)

// sensor return status codes
const unsigned int ACQUIRING  = 0;
const unsigned int COMPLETE_OK  = 1;
const unsigned int COMPLETE_ERROR  = 2;

// global to hold the result code from DHT sensor reading
int dhtResultCode;

// global to hold the smoothed values of humidity and temperature that we display and report
float mg_smoothedTemp = 0.0, mg_smoothedHumidity = 0.0; // smoothed for the display

// Lib instantiate
PietteTech_DHT DHT(DHTPIN, DHTTYPE);    // create DHT object to read temp and humidity
Servo myservo;  // create servo object to control a servo
WLDAlarmProcessor alarmer;  // create alarmer object to manage alarms

// Globals

    // This global structure holds the temperature alarm limits.  The limits are cloud accessible for reading 
    //  via the cloud variable "currentAlarmLimits" by the app.  The alarm limites are set by the app via 
    //  Particle.function() calls.  The latest values are stored in non-volitile EEPROM.
struct {
  uint8_t version = 0;
  int16_t tempAlarmLowLimit = -1;
  int16_t tempAlarmHighLimit = -1;
} AlarmLimits;

boolean ledState = false;   // D7 LED is used for indicating water level measurements

    // These globals are for Particle.variable() data for cloud access by the app.
String info = "";   // this string will hold the firmware version number and the last reset time.
String temperature = "";   // this string will hold the currently averaged temperature
String humidity = "";   // this string will hold the currently averaged humidity
String currentAlarms = "0,0,0"; // this string holds the high temp alarm, low temp alarm, leak alarm
                                //  in a comma separated format. 0 is no alarm, any other number is an
                                //  alarm.
String lowTempAlarmLimit = "";    // this string holds the low temp alarm limit
String highTempAlarmLimit = "";   // this string holds the high temp alarm limit

struct {
    bool lowTempAlarm;
    bool highTempAlarm;
    bool waterLeakAlarm;
} Alarms;


// Utility functions

// create a string of the current date-time in UTC
String dateTimeString(){
    time_t timeNow = Time.now();
    String dateTime = Time.format(timeNow,TIME_FORMAT_DEFAULT) + " UTC";
    return dateTime;
}   // end of dateTimeString()

// cloud function to write alarm limits to the struct
int writeValue(String data) {
  for(int i = 0; i < data.length(); i++) {
    if(data.charAt(i) == ',') {
      AlarmLimits.tempAlarmLowLimit = (int16_t)(data.substring(0, i).toInt());
      AlarmLimits.tempAlarmHighLimit = (int16_t)(data.substring(i+1).toInt());
    }
  }
  EEPROMwrite();  // call function to write struct to the EEPROM
  displayData();  // copy the struct data into the cloud variable string
  return 0;
}   // end of EEPROMwrite

// function to store struct to EEPROM
void EEPROMwrite() {
  EEPROM.put(100, AlarmLimits);
  return;
}

// Cloud function to read object data into a string
void displayData() {
  lowTempAlarmLimit = String(AlarmLimits.tempAlarmLowLimit);
  highTempAlarmLimit = String(AlarmLimits.tempAlarmHighLimit);
  return;
}   // end of displayData()

// write the cloud accessible variable string that contains the current alarms
void writeAlarmStatusString() {
    currentAlarms = "";
    if(Alarms.lowTempAlarm == false) {
        currentAlarms += "0";
    } else {
        currentAlarms += "1";
    }
    currentAlarms += ",";

    if(Alarms.highTempAlarm == false) {
        currentAlarms += "0";
    } else {
        currentAlarms += "1";
    }
    currentAlarms += ",";  

    if(Alarms.waterLeakAlarm == false) {
        currentAlarms += "0";
    } else {
        currentAlarms += "1";
    }

}   // end of writeAlarmStatusString

// Cloud function to send out a test alarm
int testAlarm(String nothing) {
    alarmer.sendTestAlarm(); 

    return 0;   
}   // end of testAlarm


// setup()
void setup() {
    pinMode(LED_PIN, OUTPUT);
    pinMode(ALARM_PIN, OUTPUT);
    pinMode(INDICATOR_PIN, OUTPUT);
    pinMode(BUTTON_PIN, INPUT_PULLUP);
    pinMode(TOGGLE_PIN, INPUT_PULLUP);  // toggle switch uses an internal pullup
    myservo.attach(SERVO_PIN);  // attaches to the servo object

    DHT.begin();
    alarmer.begin();

    // declare Cloud variables and functions
    Particle.variable("Info", info);
    Particle.variable("Temperature", temperature);
    Particle.variable("Humidity", humidity);
    Particle.variable("Alarms", currentAlarms);
    Particle.variable("LowTempAlarmLimit", lowTempAlarmLimit);  
    Particle.variable("HighTempAlarmLimit", highTempAlarmLimit);

    Particle.function("SetTempAlarmLimits", writeValue);
    Particle.function("Send a test alarm", testAlarm);

    // set the information global
    info = "Firmware Verison 2.01. Last reset at: ";
    info += dateTimeString();

    // clear out alarm structure
    Alarms.lowTempAlarm = false;
    Alarms.highTempAlarm = false;
    Alarms.waterLeakAlarm = false;

    // read the temp alarm limits from EEPROM into the struct and set the global variables
    EEPROM.get(100, AlarmLimits);
    if(AlarmLimits.version != 0) {  // EEPROM never written
        // set some defaults
        AlarmLimits.tempAlarmLowLimit = -460; // below absolute zero!
        AlarmLimits.tempAlarmHighLimit = 1000;  // melts lead!
    }
    displayData();

}  // end of setup()


// loop()
void loop() {
    static boolean mute = false;  // set to true to mute the audible alarm
    static boolean indicator = false;  // set to true to flash the indicator
    static boolean alarm = false;   // set to true to sound the alarm
    static unsigned long lastReadTime = 0UL;    // DHT 11 reading time
    static boolean newData = false; // flag to indicate DHT11 has new data
    static boolean toggle = false;  // hold the reading of the toggle switch; false for humidity, true for temperature
    static boolean lastToggle = false;  // hold the previous reading of the toggle switch
    static bool firstTimeRead = true;  // special handing for first time reading
    float currentTemp, currentHumidity;

    //  read the toggle switch position and set the boolean for type of display accordingly
    if(digitalRead(TOGGLE_PIN) == LOW)  {   // indicates a temperature reading
        toggle = true;
    } else {
        toggle = false;
    }

    // determine if the toggle state has changed
    if(toggle != lastToggle) {  // user has changed the toggle switch state
        lastToggle = toggle;
        if(toggle == false) {   // display humidity now
	        meterHumidity(mg_smoothedHumidity);
        } else {
            meterTemp(mg_smoothedTemp); // display temperature now
        }
    }

    // Non-blocking read of DHT11 data and publish and display it
    int sensorStatus = readDHT(false);  // refresh the sensor status but don't start a new reading

	if(sensorStatus != ACQUIRING) {
        if(newData == true) { // we have new data
            currentTemp = DHT.getFahrenheit();
            currentHumidity = DHT.getHumidity();

            // Smooth the readings for display
            if (mg_smoothedTemp < 10) {   // first time init
                mg_smoothedTemp = currentTemp;
            }
            if (mg_smoothedHumidity < 10){  // first time init
                mg_smoothedHumidity = currentHumidity;
            }
            
            // 10 point moving average
            mg_smoothedTemp =  (0.9 * mg_smoothedTemp) +  (0.1 * currentTemp);
            mg_smoothedHumidity =  (0.9 * mg_smoothedHumidity) +  (0.1 * currentHumidity);

	        // set temperature or humidiy on the servo meter
	        if(toggle == true)  {   // temperature reading called for
	            meterTemp(mg_smoothedTemp);
	        }  else  {  // humidity reading called for
	         meterHumidity(mg_smoothedHumidity);
	        }
  
            // set the cloud temperature and humidity globals
            temperature = String::format("%4.1f", mg_smoothedTemp);
            humidity = String::format("%4.1f", mg_smoothedHumidity);



            // test for low and high temperature alarms and set the flags
            if(mg_smoothedTemp < lowTempAlarmLimit.toFloat()) { // we have a low temperature alarm
                Alarms.lowTempAlarm = true; // set the low temperature alarm flag
            } else {    // no low temperature alarm now
                Alarms.lowTempAlarm = false; // set the low temperature alarm flag
            }
        
            if(mg_smoothedTemp > highTempAlarmLimit.toFloat()) { // we have a high temperature alarm
                Alarms.highTempAlarm = true; // set the high temperature alarm flag
                alarmer.sendHighTemperatureAlarm(mg_smoothedTemp); // send out the alarm for processing
            } else {    // no high temperature alarm now
                Alarms.highTempAlarm = false; // set the low temperature alarm flag
            }

            if(firstTimeRead == false) {    // process alarms only after the first time through

                // process the alarm flags to send or reset the alarms, as appropriate
                if(Alarms.lowTempAlarm == true) {   // low temp alarm needs processing
                    alarmer.sendLowTemperatureAlarm(mg_smoothedTemp); // send out the alarm for processing
                    alarmer.armHighTempAlarm();  // reset the alarm processing for a new alarm in the future
                } else if(Alarms.highTempAlarm == true) {     // high temp alarm needs processing
                    alarmer.sendHighTemperatureAlarm(mg_smoothedTemp); // send out the alarm for processing
                    alarmer.armLowTempAlarm();  // reset the alarm processing for a new alarm in the future            
                } else {    // not temp alarms, therefore both alarms need rearming
                    alarmer.armHighTempAlarm();  // reset the alarm processing for a new alarm in the future
                    alarmer.armLowTempAlarm();  // reset the alarm processing for a new alarm in the future 
                }

            }
            firstTimeRead = false;  // skipped the first reading, now allow alarms
            writeAlarmStatusString();   // write out the current status of all alarms

	        newData = false; // don't publish/process results again until a new reading
        }

        if((diff(millis(), lastReadTime)) >= DHT_SAMPLE_INTERVAL) { // we are ready for a new reading
          readDHT(true);  // start a new reading
          newData = true; // set flag to indicate that a new reading will result
          lastReadTime = millis();


            // toggle the D7 LED to indicate loop timing for DHT11 reading
            ledState = !ledState;
            if (ledState) {
                digitalWrite(LED_PIN, HIGH);
            } else {
                digitalWrite(LED_PIN, LOW);
            }
        }

    }


    // measure and test water level at pre-determined interval
    if(nbWaterMeasureInterval(20) == false) {  // 20 ms between sensor readings

        // read the water level from the sensor; convert to a voltage value
        int waterLevelA, waterLevelB;
        float waterSensorVoltageA, waterSensorVoltageB;

        waterLevelA = analogRead(WATER_SENSOR_A_PIN);
        waterLevelB = analogRead(WATER_SENSOR_B_PIN);
        waterSensorVoltageA = ((float)waterLevelA * 3.3) / 4095;
        waterSensorVoltageB = ((float)waterLevelB * 3.3) / 4095;

        // integrate and threshold measurement for alarm
        if(alarmIntegrator(waterSensorVoltageA, waterSensorVoltageB) == true) {
            indicator = true;
            // process a water leak detection
            Alarms.waterLeakAlarm = true;   // set the alarm flag
            alarmer.sendWaterLeakAlarm();   // send the alarm for processing
            writeAlarmStatusString();   // update the alarm status global string

            if(mute == false) {
                alarm = true;
            } else {
                alarm = false;
            }
        } else {
            indicator = false;
            // no water leak alarm so process and rearm
            Alarms.waterLeakAlarm = false;   // set the alarm flag
            alarmer.armLeakAlarm();   // send the alarm for processing
            writeAlarmStatusString();   // update the alarm status global string

            alarm = false;
            mute = false;   // reset alarm muting
        }
    }

    // process the mute pushbutton
    if(readPushButton() == true) {
        mute = true; // set the alarm mute flag
        alarm = false; // mute the alarm right now
    }

    // refresh non-blocking alarm & indicator status
    nbFlashIndicator(indicator);
    nbSoundAlarm(alarm);
    
} // end of loop()
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

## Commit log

2017-01-19 In process develop-and-test
    This test code reads sensor values every 3 seconds and thresholds and
    integrates the thresholded values to test software filtering for
    reliable water level detection and alarming.
2017-01-20 Added documents
    Added preliminary (incomplete) parts list, final concept document and
    sensort test report
    [WaterLeakAlarmPartsList.xlsx]
2017-01-20 Added test version 03
    This version changes the loop measurement delay from blocking to
    non-blocking. It adds an indicator and processes a push button to mute
    the alarm (but not the indicator).
2017-01-21 Updated parts list
    Added in new, cheaper source for water level sensor on Amazon.com
    [WaterLeakAlarmPartsList.xlsx]
2017-01-25 Added version 04
    This test version now flashes the LED and pulses the alarm. It also
    lights the LED solidly if nto alarming, to show that system is armed and
    ready.
2017-01-31 Added Schematic
    Full schematic for the project, including 2 sensors, servo, DHT11, and
    backlit pushbutton.
    [Full Water Level Detector Project Schematic.sch]
2017-01-31 added PDF version of full schematic
    PDF is the same as the eagle .sch version
2017-01-31 Updates schematic
    Added pullup resistor required for DHT11.
    [Full Water Level Detector Project Schematic.sch]
2017-01-31 Added Piezo Buzzer annotation
    Annotated the speaker to indicate that it is a piezo buzzer.
    [Full Water Level Detector Project Schematic.sch]
2017-02-02 Added support for two sensors and cleaned up directory
    Version 05 adds support for two sensors. Deleted the older test
    firmware versions. This version 05 is the one version that tests all
    leak sensor detection and alarming functions.
2017-02-03 Updated schematic
    1. added pulldown resistor to piezo buzzer driver input so that buzzer
    doesn't sound when flashing/resetting the Photon.
    2. added toggle switch.
    3. clarified some annotations.
    [Full Water Level Detector Project Schematic.sch]
2017-02-03 Reorganized
    Added folders for hardware, Firmware and Documentation and moved files
    appropriately.
    [Full Water Level Detector Project Schematic.sch, WaterLeakAlarmPartsList.xlsx]
2017-02-04 Changed sensor sample interval
    Changed the sensor sample interval to 20 ms vs 2 ms for improved
    detection reliability. It now takes 5 x 20 ms = 100 ms to confirm a
    change in state (to detect leak or clear leak).
2017-02-07 Updated schematic
    Changed DHT11 data to Photon D2 instead of D0. D0 does not work with
    Piettetech library. Changed IC1D input to D0 to free up D2 for the
    DHT11.
    [Full Water Level Detector Project Schematic.sch]
2017-02-08 Updated schematic
    Placed 5.6 Kohm pulldown resistors on all input pins of the 74AHCT125 to
    clamp off noise when the Photon is flashing/reset. Used 5.6 Kohm in
    lieu of 4.7 Kohm because that is what I had on hand.
    [Full Water Level Detector Project Schematic.sch]
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2017-03-07 Added routine to calibrate the servo meter
    This routine uses the SIS debug client to allow the user to exercise the
    servo with different values and to find the proper endpoint values for
    any given servo when mounted with the meter scale.
2017-03-07 Added Calibration Document
    This document describes the theory behind calibrating and scaling
    temperature and humidity to read out on the servo meter. It also
    describes the calibration and scaling testing procedure that must be
    used to obtain the values of MAX_POS and MIN_POS for any given servo.
2017-03-08 Changed servo control pin to A5
    Changed the servo control pin from D3 to A5 for compatibility with Core,
    Photon and Electron (according to Particle documentation).
    [Full Water Level Detector Project Schematic.sch]
2017-03-16 moved ServoCal to new folder. Changed return code so that actual servo position is returned if a limit is exceeded
2017-03-16 added two new cloud methods: pos plus 5 and pos minus 2. Makes it easier to dial in the correct limits.
    [ServoCal.ino]
2017-03-23 Improved toggle switch response
    Added code to process the toggle selector immediately, vs at the next
    DHT11 reading interval. Also explicitly initialialized the temperature
    and humidity integrator variables to 0.0 (vs. implicit initialization
    previously).
2017-03-27 Schematic of Sensor wiring with SF RJ11 PCB
    The wiring of the Sparkfun RJ11 breakout boards through a 4 wire
    telephne cable is screwy, to say the least! Here is a schematic for how
    it must be wired up. Pins 3,4, and 5 are used on the sensor side, and
    pins 2,3, and 4 are used on the Box side. Sensor 5 --> Box 2 (signal),
    Sensor 4 --> Box 3 (+3.3 volt) and Sensor 3 --> Box 4 (GND). Tested
    this with > 10 feet of telephone cable and it works fine.
2017-04-07 Final PCB Eagle Files
    Final copies of Eagle schematic and board files as well as PDFs of
    these.
    [Full Water Level Detector Project Schematic.brd, Full Water Level Detector Project Schematic.sch]
2017-04-07 Moved PCB files to the correct folders for publication
2017-04-08 Corrected and renamed files
    Changed Photon to through hole version. Changed the layout somewhat to
    improve placement and routing. Changed the names to be more
    descriptive.
    [Water Leak Detector PCB.brd, Water Leak Detector PCB.sch]
2017-04-08 Updated parts list
    Need to order parts and verify correct footprints for all (particularly
    the piezzo buzzer).
    [WaterLeakAlarmPartsList.xlsx]
2017-04-08 Updated parts list
    [WaterLeakAlarmPartsList.xlsx]
2017-04-21 Added 4 pin SIPP socket to parts list
    Added 4 pin SIPP socket to the parts list for mounting of the Adafruit
    DHT11 on a PCB.
    [WaterLeakAlarmPartsList.xlsx]
2017-04-22 Updated schematic
    Updated schematic to show the resistor values for the components that
    are on the parts list.
    [Water Leak Detector PCB.brd, Water Leak Detector PCB.sch]
2017-05-01 Fixed bug in Blynk Notification Logic
    Fixed the bug in the Blynk notification logic that required the mute
    button to be pressed to reset the condition for a subsequent alarm.
    This version also includes a second notification 30 seconds after the
    first notification, for enhanced alarm notification reliability.
    [WaterLeakDetector.ino]
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2017-05-24 Updated parts list
    Updated the parts list to add a link for the PCB
    [WaterLeakAlarmPartsList.xlsx]
2017-05-26 pcb v2. changed buzzer. adjusted position of J1-4 to align. Added much text to top silk.
    [Water Leak Detector PCB.brd, Water Leak Detector PCB.sch]
2017-05-30 Blynk Terminal and LED added. Need Blynk app of 5/30/2017 or later
2017-06-01 untested. includes Bob's fix
    [WaterLeakDetector.ino]
2017-06-04 Added change detection to LED state
    Added a change detector to changing the Blynk LED state to prevent
    flooding errors. How the Blynk server only gets an LED state message
    when the state changes. Setup() initializes the alarm LED to off.
    [WaterLeakDetector.ino]
2017-07-06 v0.4 of the mount. RJ11 mounts now correct. Lowered wall mount holes a bit.
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2017-07-30 v2 casebezel: bigger, switch down, stiffener
    [casebezel.stl]
2017-08-02 case bottom version 2. PCB mounting standoffs. bezel retention corners.
    [casebottomskel.FCStd, casebottomskel.stl]
2017-08-09 Updated Parts List
    Still missing a few links from Jim: V2 PCB, Shapeways, small mounting
    screws for 3D faceplate. This version of the parts list specifies Nylon
    4-40 hardware (metal or nylon 6-32 hardware can also be used). It also
    specifies a jameco 7 foot telephone cable with a note about other
    lenghts and colors being available in hardware stores.
    [WaterLeakAlarmPartsList.xlsx]
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2017-08-15 updated CaseDial to have smaller cut out for servo, and organized laser cut case pages. This case was actually cut and assembled.
2017-08-18 Updated Parts List
    Updated the parts list and prublished as PDF. Moved from Hardware to
    Documentation.
    [WaterLeakAlarmPartsList.xlsx]
2017-08-20 wood case v0.6 makes it larger to give standoffs clearance from PCB
2017-09-02 open case v0.7 fixed RJ11 position. Also removed large box bezel
2017-09-06 Updated Servo Meter Calibration doc
    Reorganized to show the procedure up front and the theory at the end.
    Changes Shrimpware debug instructions to Particle console instructions.
    Formatted doc for publication.
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2017-09-13 v3 with cylndrical standoffs.
    [casebottomskel.stl]
2017-09-13 v3 with cylndrical standoffs (again).
    [casebottomskel.stl]
2021-03-20 Update WaterLeakDetector.ino
    Added DHT.begin() call to setup(), per ScruffR's suggestion. Temp and Humidity reporting are now working! This code is otherwise identical to the previous version, except that it no longer reports temp and humidity to the Particle Console every minute. This latter change is necessary as a result of Particle's limiting free tier cloud publications to 100,000 per month.
    [WaterLeakDetector.ino]
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2022-10-27 WLD version 2.0
    Looks like all bugs are corrected
    [WaterLeakDetector.ino]
2022-10-28 WLD version 2.0
    EEPROM initialization bug fixed. There is still a latent bug that initially has a temp of -4.000 F until the first new reading. This is visible on the servo meter - it goes max negative and then goes to the correct temp. This wasn't an issue before temp alarms -- now sends a low alarm upon bootup, even when temp is normal.
    [WaterLeakDetector.ino]
2022-10-28 WLD version 2.01
    Completed and tested. Temp alarm limits now stored in EEPROM and restored upon reboot. Eliminated the initial low temp alarm on reboot, Formatted the temp and humidity cloud variables to read out to one decimal place.
    [WaterLeakDetector.ino]
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

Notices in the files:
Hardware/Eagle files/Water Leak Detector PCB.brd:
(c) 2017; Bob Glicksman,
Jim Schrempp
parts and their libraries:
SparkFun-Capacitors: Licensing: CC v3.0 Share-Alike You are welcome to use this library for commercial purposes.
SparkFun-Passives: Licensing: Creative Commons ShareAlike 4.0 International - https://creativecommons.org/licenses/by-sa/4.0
